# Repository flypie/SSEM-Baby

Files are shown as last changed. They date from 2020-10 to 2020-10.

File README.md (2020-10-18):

# SSEM-Baby

This is a work in progress.

All of the IP belongs to the Computer Conservation Society this project is purely to convert the diagrams to KiCAD as a format with greater utility. https://computerconservationsociety.org/ssemvolunteers/volunteers/index.html

I do not claim any rights whatsoever.

If anyone want to do help out with checks or corrections let me know and I'll try and work out how Merge works.

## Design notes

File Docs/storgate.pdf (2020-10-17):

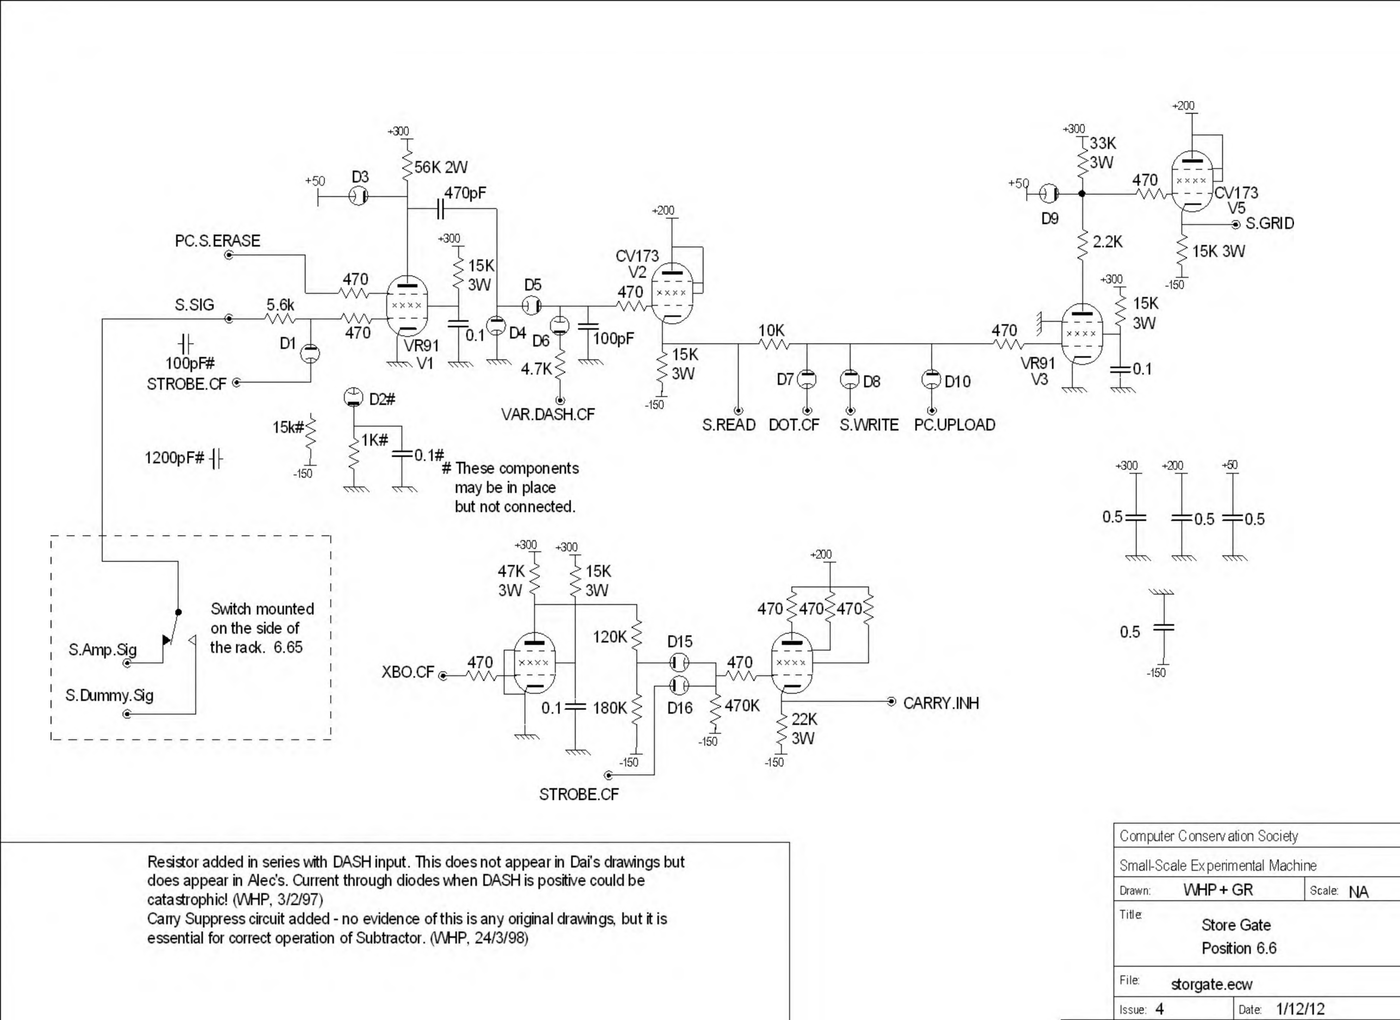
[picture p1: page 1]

Resistor added in series with DASH input. This does not appear in Dai's drawings but does appear in Alec's. Current through diodes when DASH is positive could be catastrophic! {]NHP, 3/2/97)
Carry Suppress circuit added - no evidence of this is any original drawings, but it is essential for correct operation of Subtractor. (WHP, 24/3/98)

C o m p u te r C o n s e rv a tio n S o cie ty

S m a ll-S c a le E x p e rim e n ta l M a ch in e

Drawn: | VMHP+GR | Scale: |\|/\
| Store Gate Position 6.6
Flle | storgate.ecw

Issue:

4 | Date: | 1/12/12

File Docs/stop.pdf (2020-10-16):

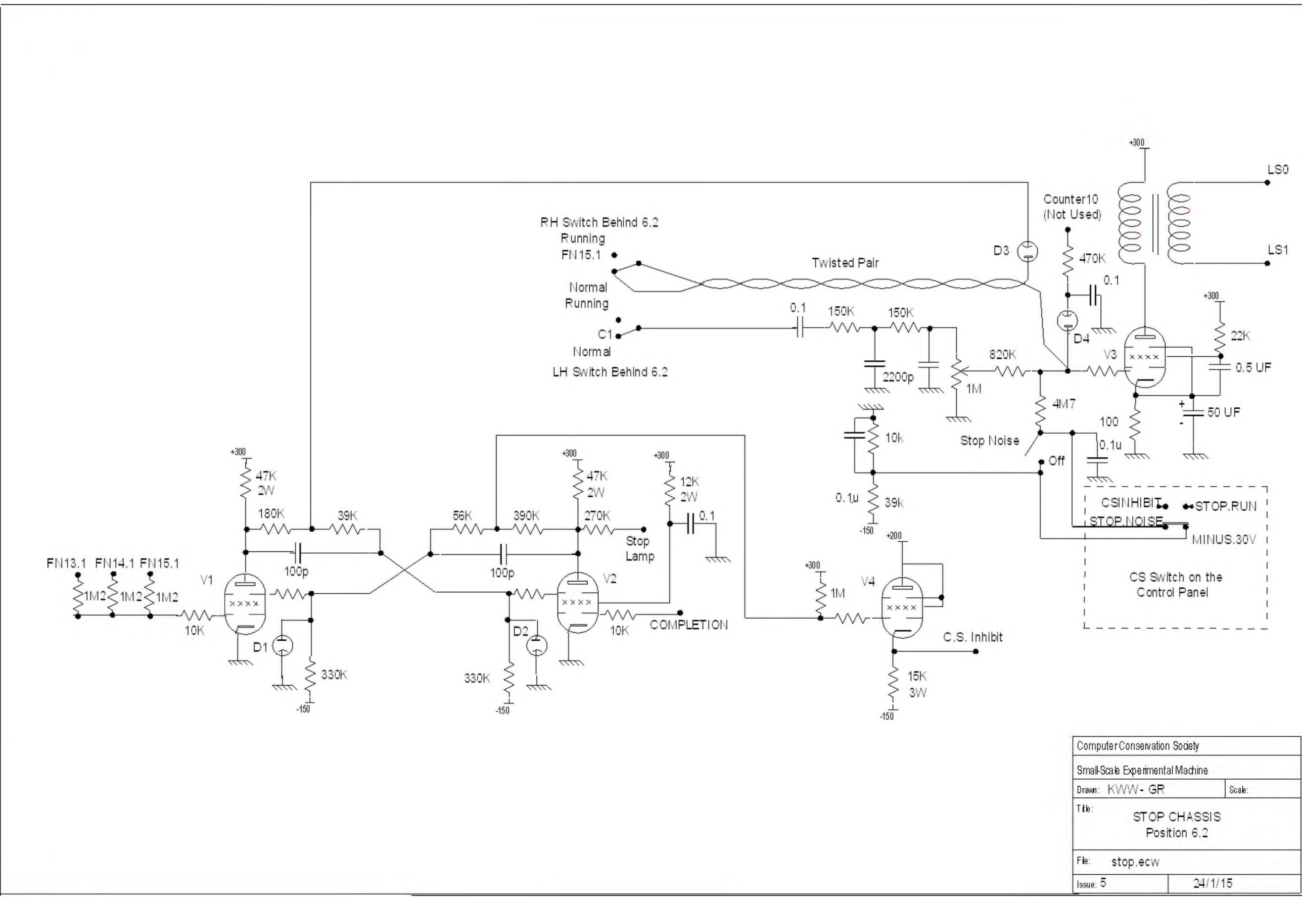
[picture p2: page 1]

+300

FI 113.1 FN 14.1 FI 115.1

>im 2 < im : < im :

V1

'A / W ^ r - — j
10K

LSO

ComputerConseivation Soaety Small-Scale B<perimentalMachine

Draw: KWW- GR | Scale:
Tile: | STOP CHASSIS

Position 6.2

Fie: | stop.ecw
Issue: 0 | 24/1/15

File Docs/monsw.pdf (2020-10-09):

a

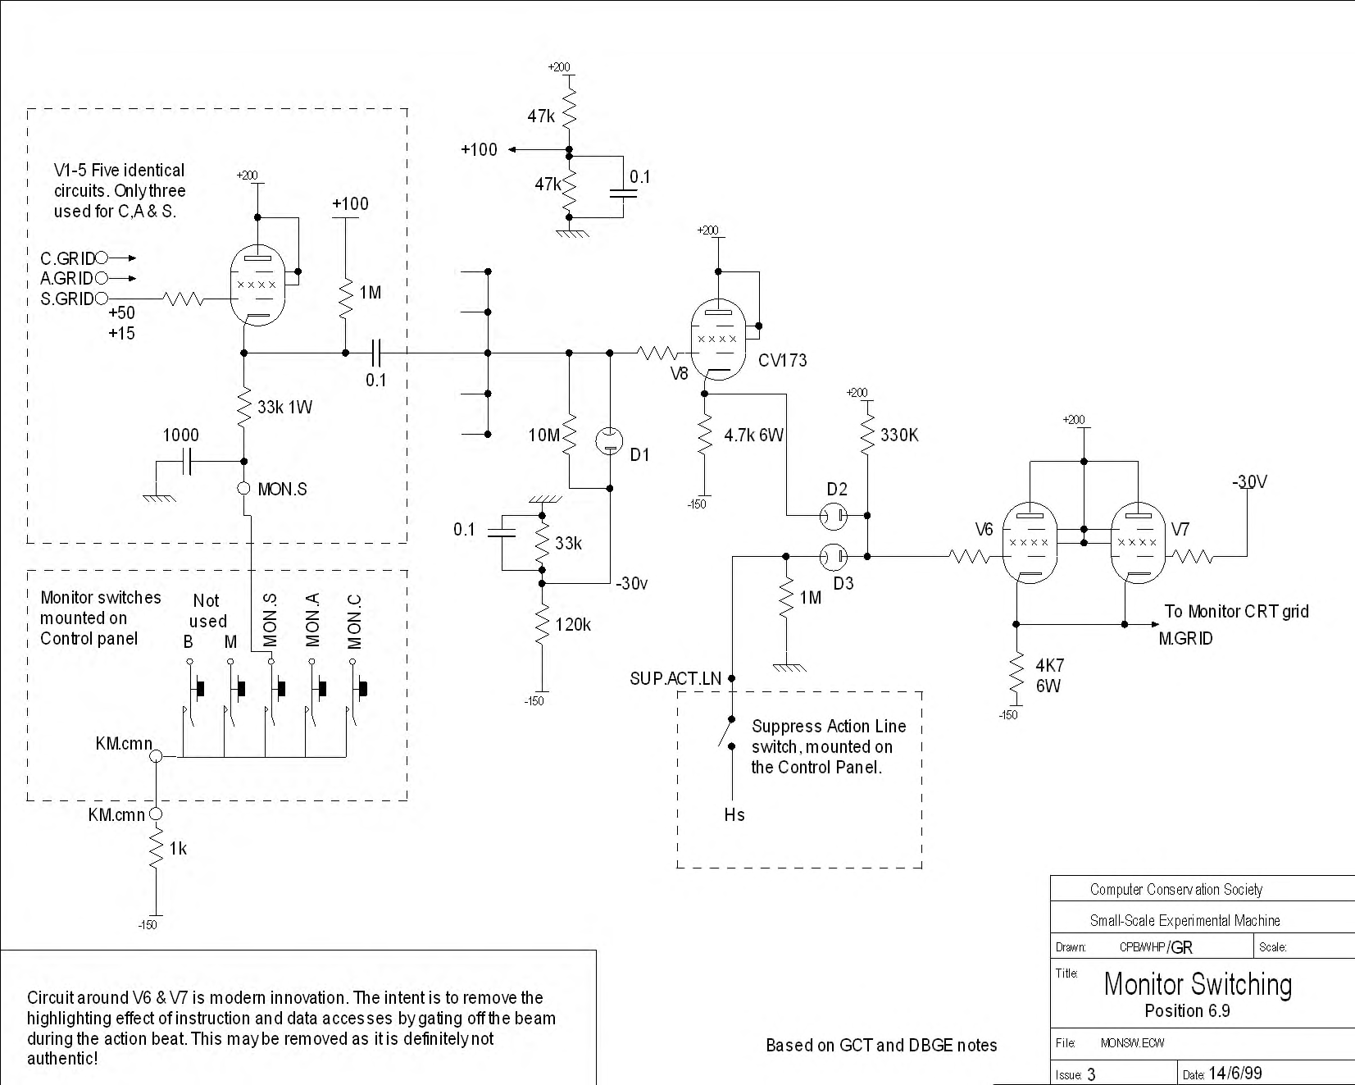
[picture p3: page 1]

+200

V1-5 Five identical | + 2 C 0
circuits. Onlythree
used for C.A& S. | t----
C.GRIDO— ► | / 1___ ___1 \
A.GRIDO—*■ | X X X X
S.GRIDO--------- W V —

+100

+50
+15

0.1
33k 1W

1000

MON.S

Monitor switches
mounted on
Control panel

Not
used
B

KM.cmn.
O-

co

o

<

o

q

o

+ | + | + | +

^

> | > | > | >1 | >

KM.cmn O

1k

-150

Circuit around V6 &V7 is modern innovation. The intent is to remove the highlighting effect of instruction and data accesses by gating off the beam during the action beat. This maybe removed as it is definitely not authentic!

0.1

+200

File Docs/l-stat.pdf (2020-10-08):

# Gb____^At)

l | (? | 0

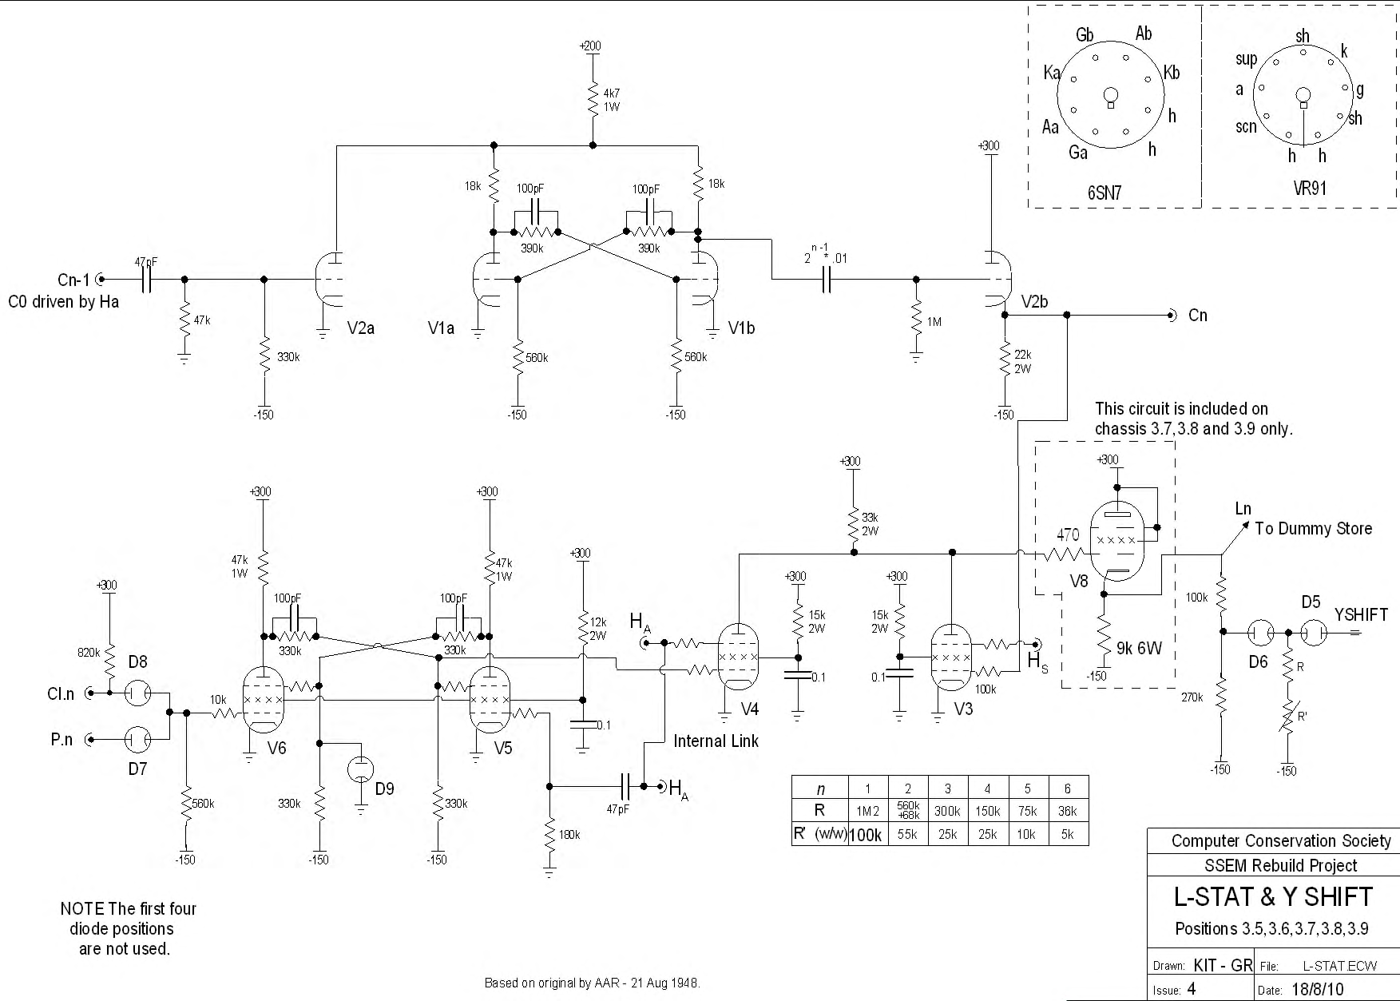
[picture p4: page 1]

+200

Cn-1 (?

# CO driven by Ha

4- V1b

+300 | +300

# NOTE The first four diode positions

are not used.

B a s e d o n o r ig in a l b y A A R - 21 A u g 1 9 4 8.

+300

n -1
2 | *.01
/ | 0 | o
■ '* 7 | O | o vKb

' h

# AaV o o

I,
Ga | h

6SN7

V2b

22k
2 W

-150

+330

33k
2 W
+300 | +300
15k | 15k
2 W | 2 W
-0.1 | 0 .1 -

1

*> Cn

# This circuit is included on

chassis 37,3.8 and 3.9 only.

+300

470
Y W -

V8

t?

i

--- - - i / V W
X X X X | Y 1 S 9k 6W

■ \A A /—

Hs ,

-150 | 1

Ln

# To Dummy Store

100k | D5
D6 | R

# YSHIFT

## -L _L V3

1 COk
270k

R 1

-150

n | 1 | 2 | 3 | 4 | 5 | 6
R | 1 M 2 | o c o | 3 0 0 k | 1 5 0 k | 7 5 k | 3 6 k
R (w/w)100k 5 5 k | 2 5 k | 2 5 k | 1 0 k | 5 k

-150

# Computer Conservation Society SSEM Rebuild Project

# L-STAT& YSHIFT

# Positions 3.5,3.6,37,3.8,3.9

D raw n: KIT - GR

### issue:: 4

### File: L-S T A T .E C W

### Dale: 1 8 / 8 / 1 0

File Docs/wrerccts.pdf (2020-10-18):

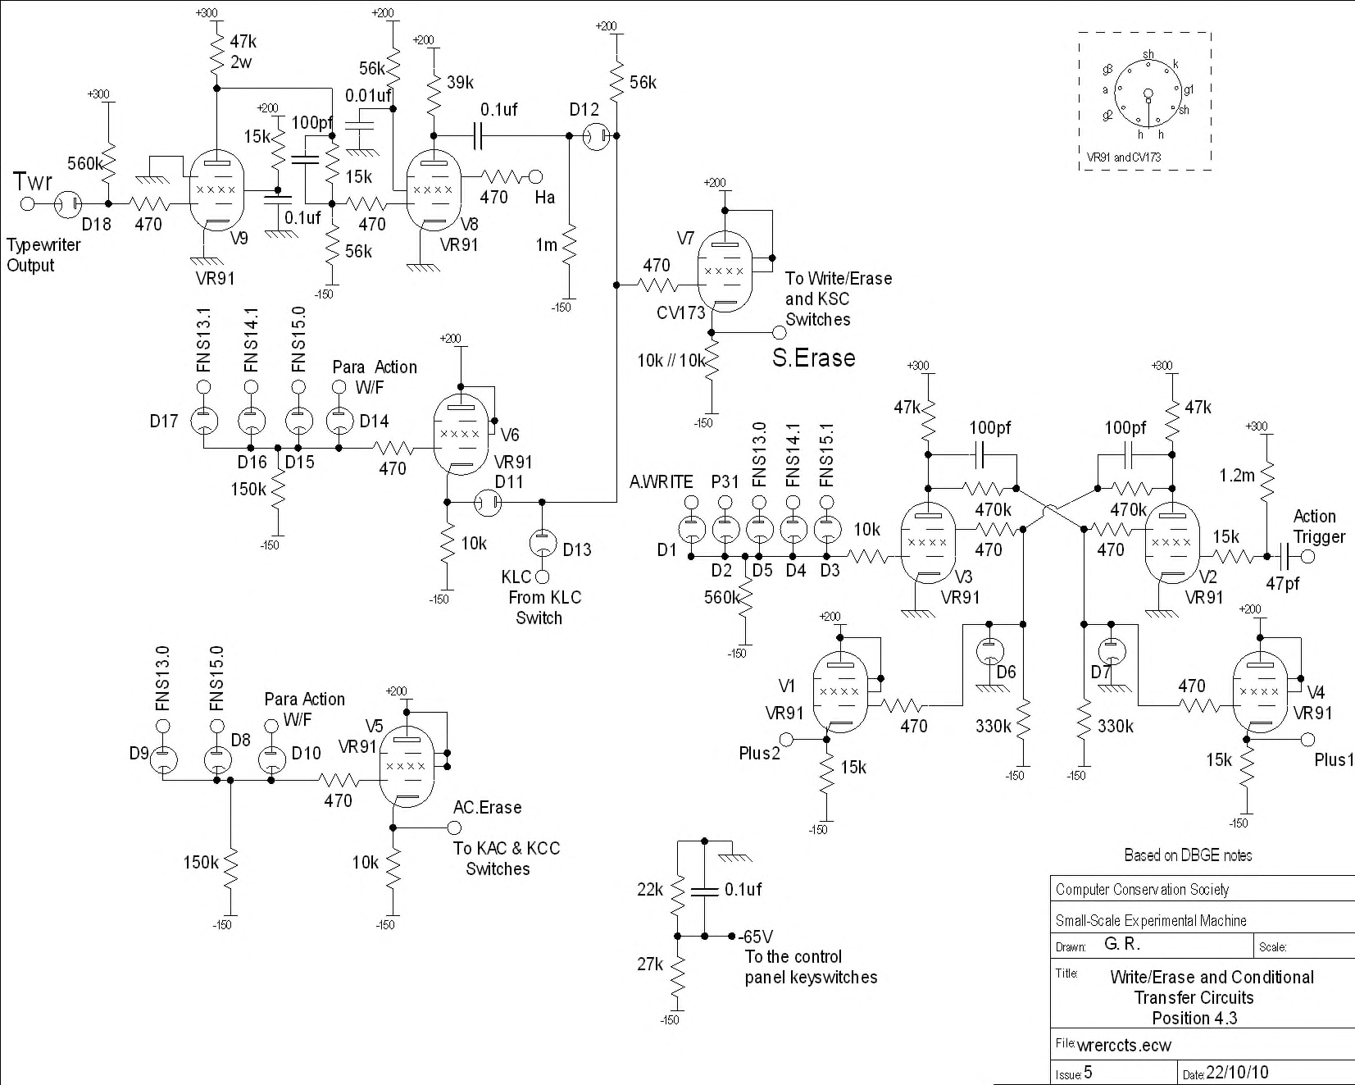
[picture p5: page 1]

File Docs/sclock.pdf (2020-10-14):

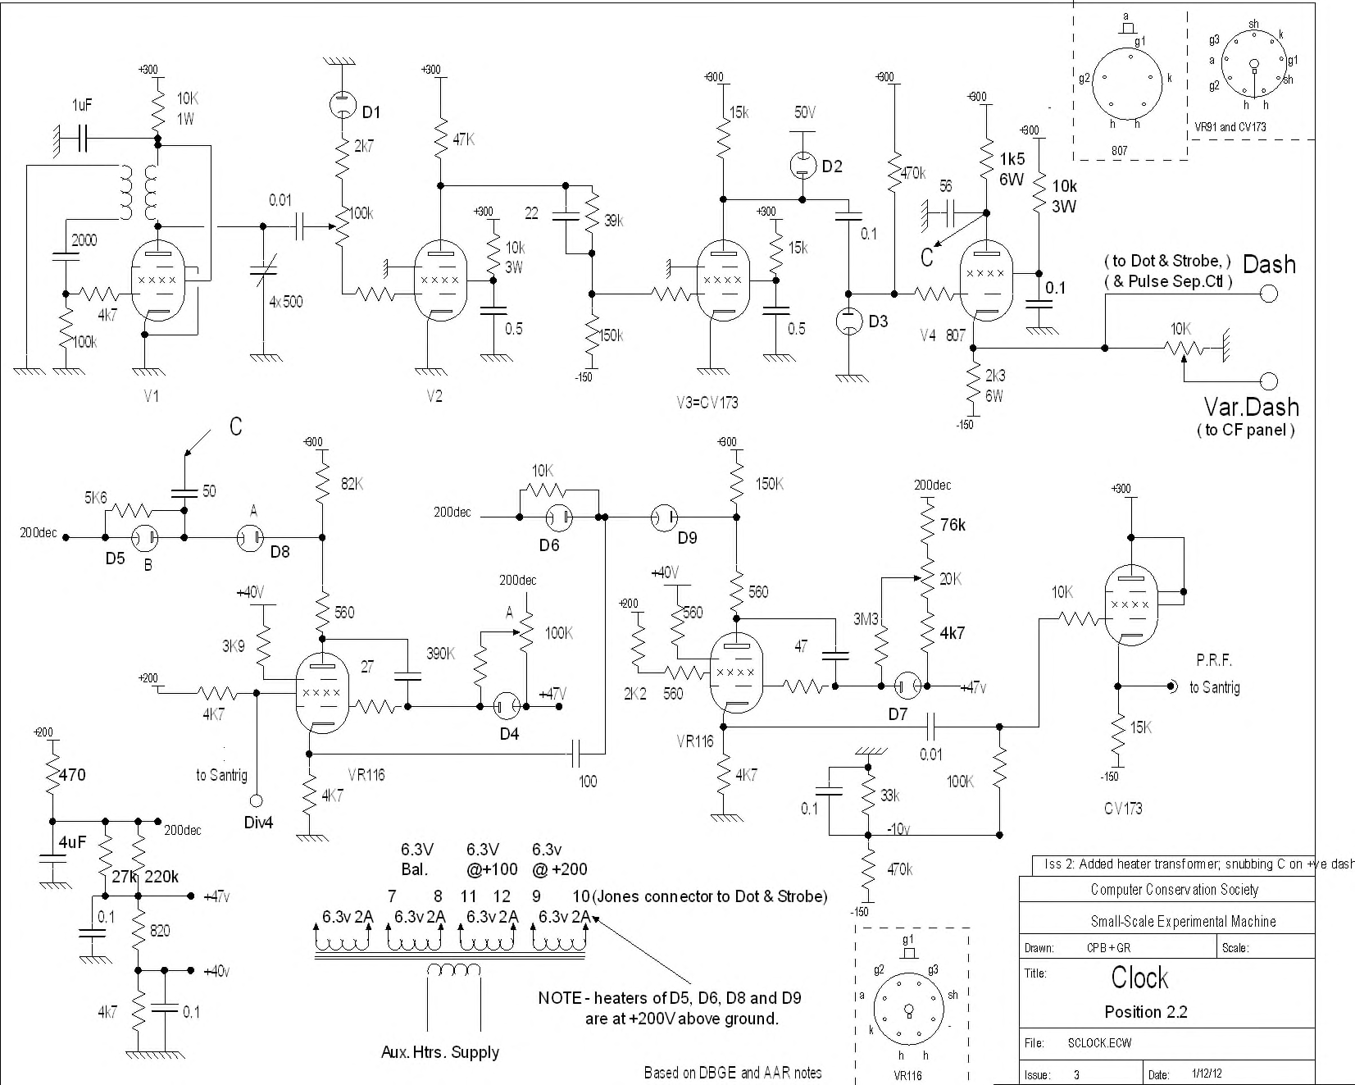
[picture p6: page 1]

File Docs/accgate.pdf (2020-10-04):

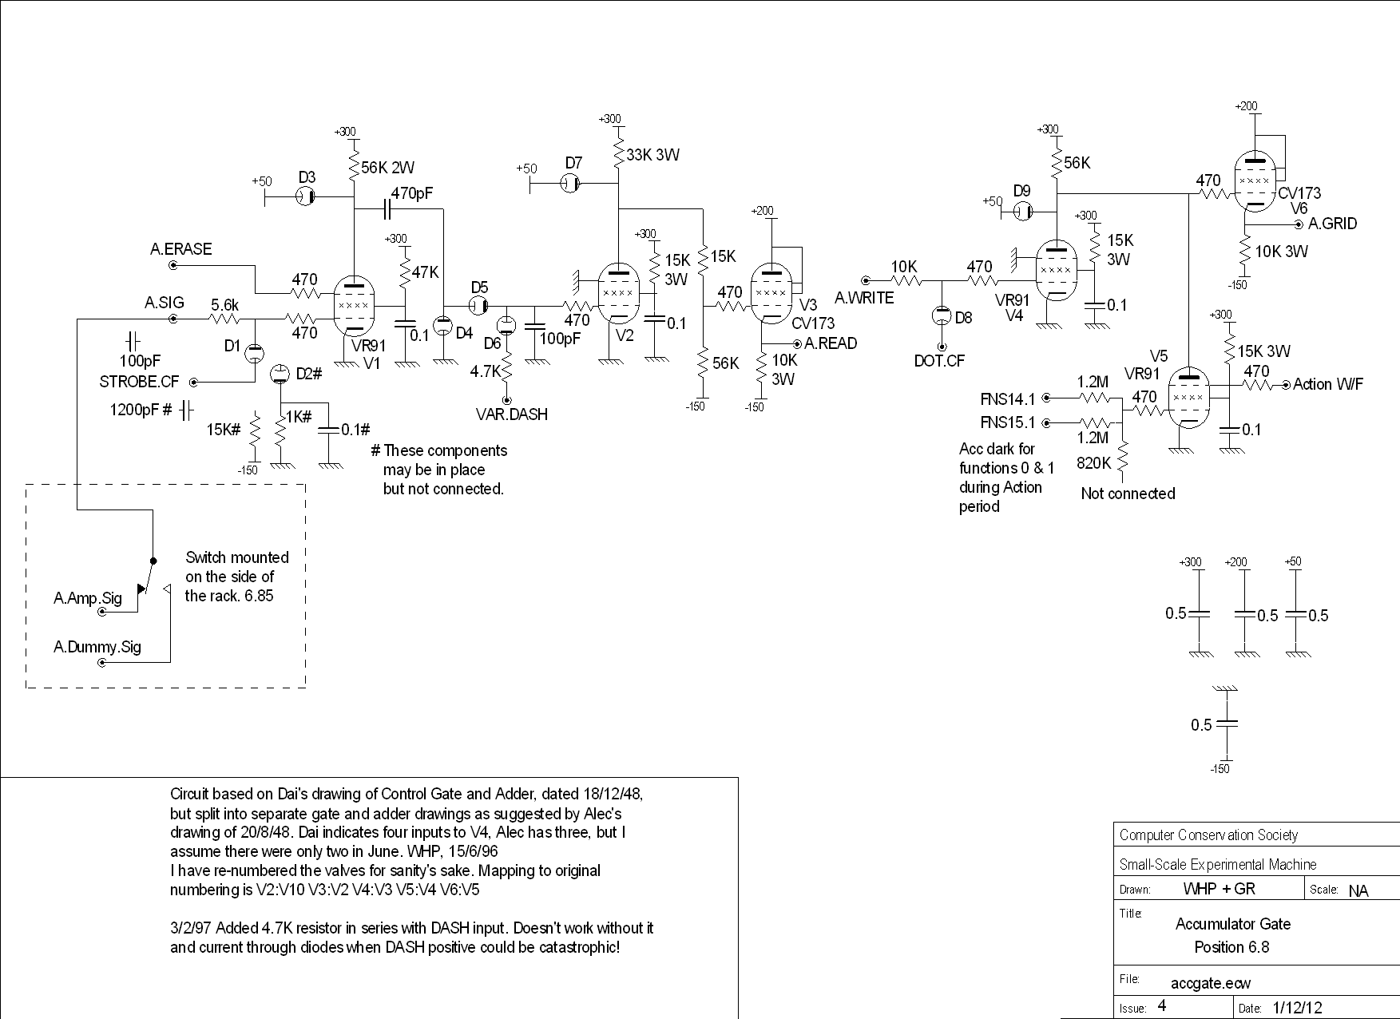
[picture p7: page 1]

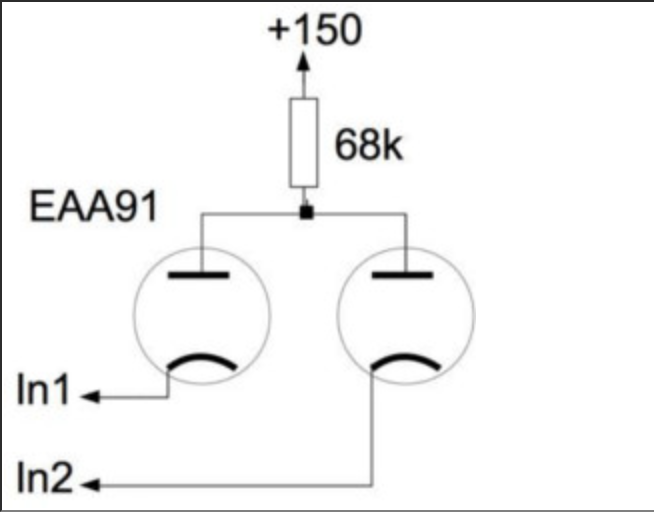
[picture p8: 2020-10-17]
Gates/and.png

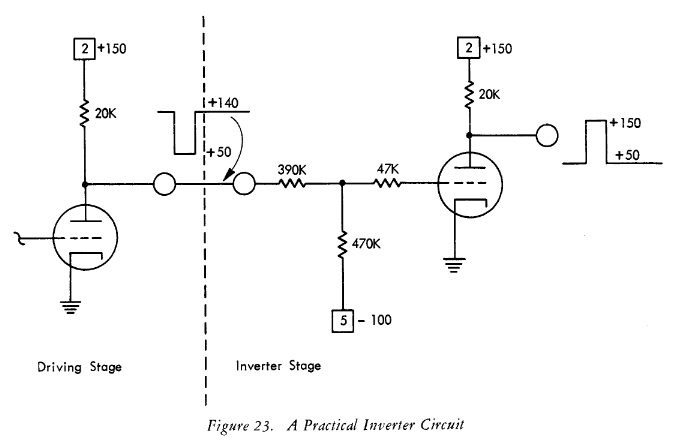
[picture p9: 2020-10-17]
Gates/ibm not.png

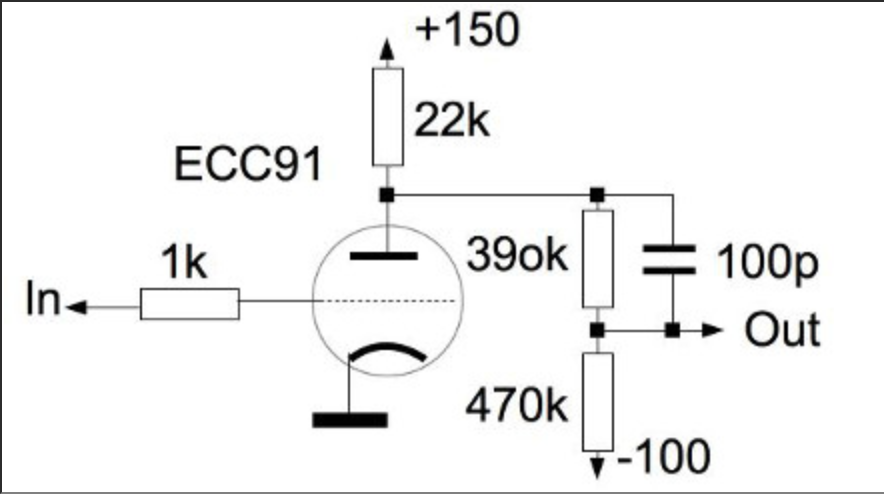
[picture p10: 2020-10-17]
Gates/NOT.png

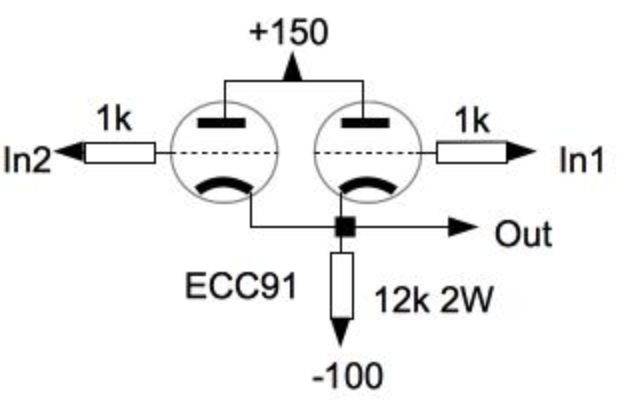
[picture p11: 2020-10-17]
Gates/or.png

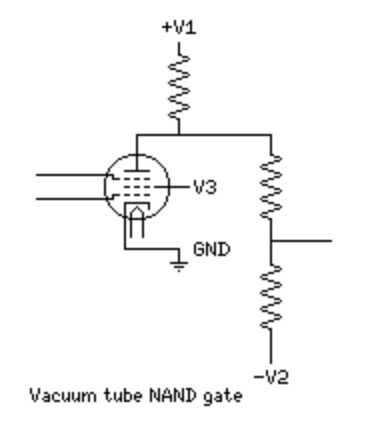
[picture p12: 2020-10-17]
Gates/NAND.png

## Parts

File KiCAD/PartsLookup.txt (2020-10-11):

CR1 DILA22 
CR2 DILA40 + DILA-XHI10 
CR3 DILA40 + DILA-XHI01
CR4 DILA22

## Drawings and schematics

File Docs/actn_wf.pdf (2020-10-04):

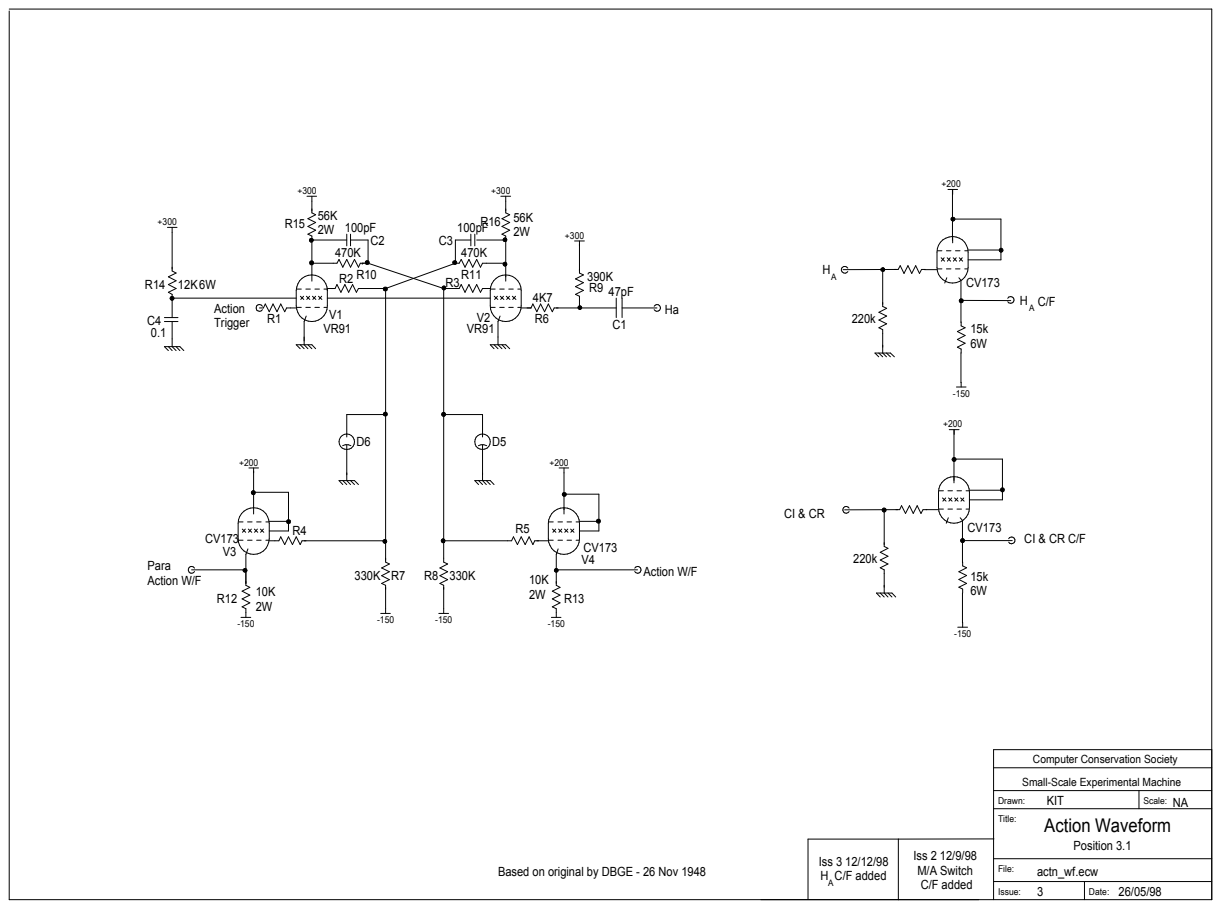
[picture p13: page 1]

Small-Scale Experimental Machine
KIT
Action Waveform

Iss 3 12/12/98 H C/F added A | Iss 2 12/9/98 M/A Switch C/F added

Based on original by DBGE - 26 Nov 1948

Issue: 3 | Date: 26/05/98

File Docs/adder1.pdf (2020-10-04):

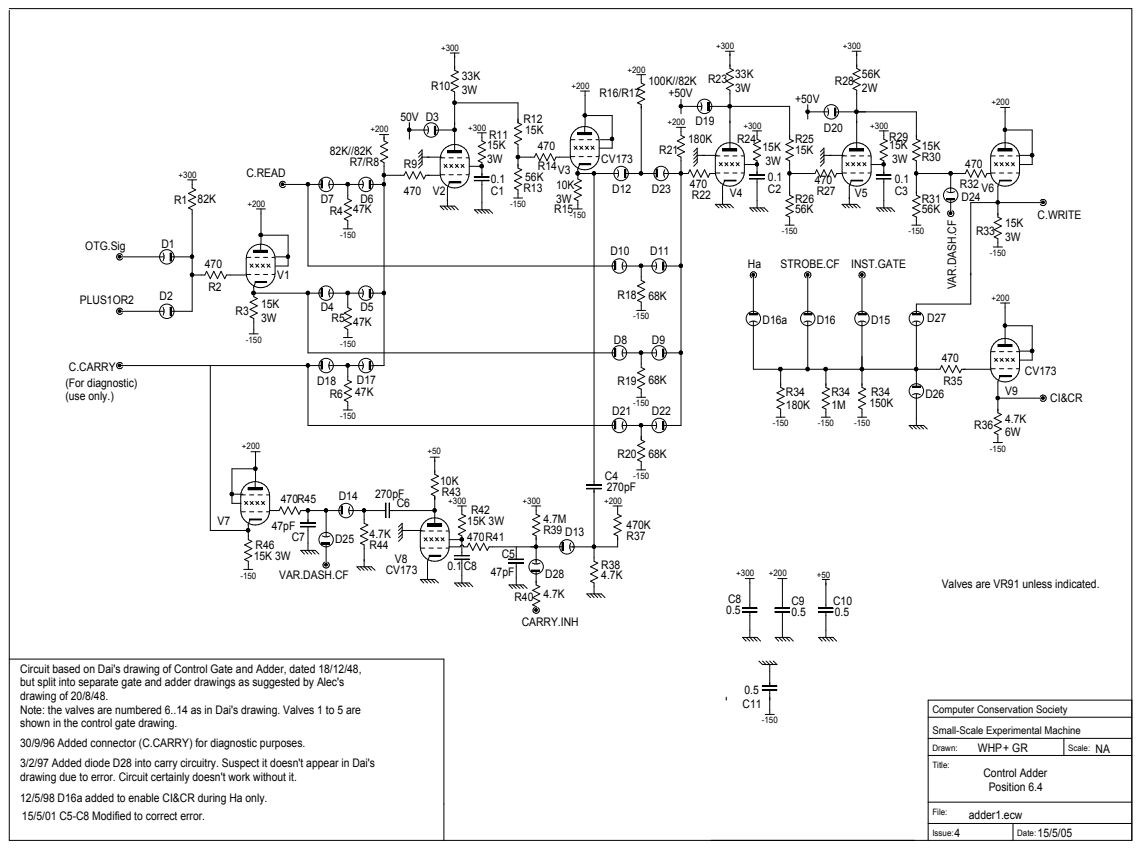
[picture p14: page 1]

Valves are VR91 unless indicated.

Circuit based on Dai's drawing of Control Gate and Adder, dated 18/12/48,
but split into separate gate and adder drawings as suggested by Alec's
drawing of 20/8/48.
Note: the valves are numbered 6..14 as in Dai's drawing. Valves 1 to 5 are
shown in the control gate drawing.
30/9/96 Added connector (C.CARRY) for diagnostic purposes.
3/2/97 Added diode D28 into carry circuitry. Suspect it doesn't appear in Dai's
drawing due to error. Circuit certainly doesn't work without it.

Small-Scale Experimental Machine

12/5/98 D16a added to enable CI&CR during Ha only.
15/5/01 C5-C8 Modified to correct error.

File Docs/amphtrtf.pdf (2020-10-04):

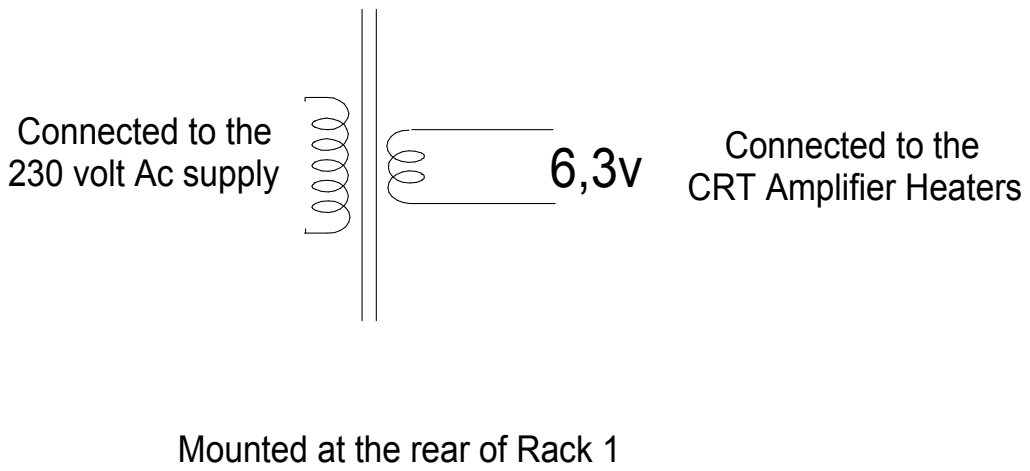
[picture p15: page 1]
Drawn:; Scale:; Title:; File:; Issue:; Date:; Position 1.5; AMPHTRTF.ECW

Connected to the
230 volt Ac supply

CRT Amplifier Heaters

Mounted at the rear of Rack 1

Computer Conservation Society

Small-Scale Experimental Machine

Amp Heater Transformer

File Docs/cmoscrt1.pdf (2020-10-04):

C0

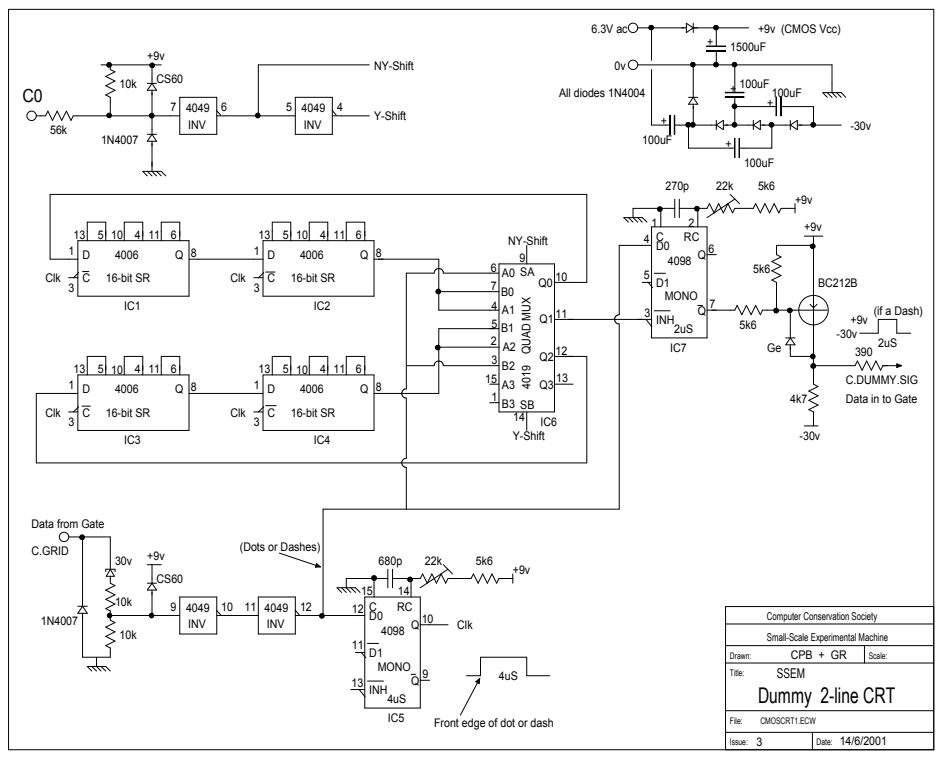
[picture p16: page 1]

C.DUMMY.SIG
Data in to Gate

Small-Scale Experimental Machine
CPB + GR
SSEM
Dummy 2-line CRT

Front edge of dot or dash

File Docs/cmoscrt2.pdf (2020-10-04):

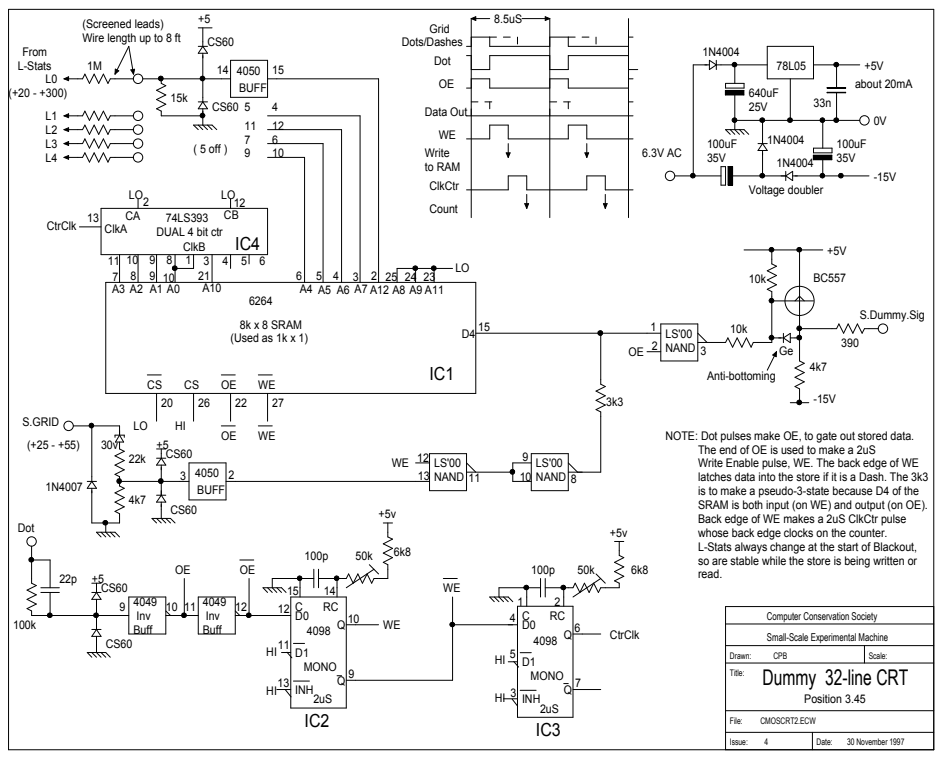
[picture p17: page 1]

(Screened leads)
Wire length up to 8 ft

NOTE: Dot pulses make OE, to gate out stored data.
The end of OE is used to make a 2uS
Write Enable pulse, WE. The back edge of WE
latches data into the store if it is a Dash. The 3k3
is to make a pseudo-3-state because D4 of the
SRAM is both input (on WE) and output (on OE).
Back edge of WE makes a 2uS ClkCtr pulse
whose back edge clocks on the counter.
L-Stats always change at the start of Blackout,
so are stable while the store is being written or
read.

Small-Scale Experimental Machine
Dummy 32-line CRT

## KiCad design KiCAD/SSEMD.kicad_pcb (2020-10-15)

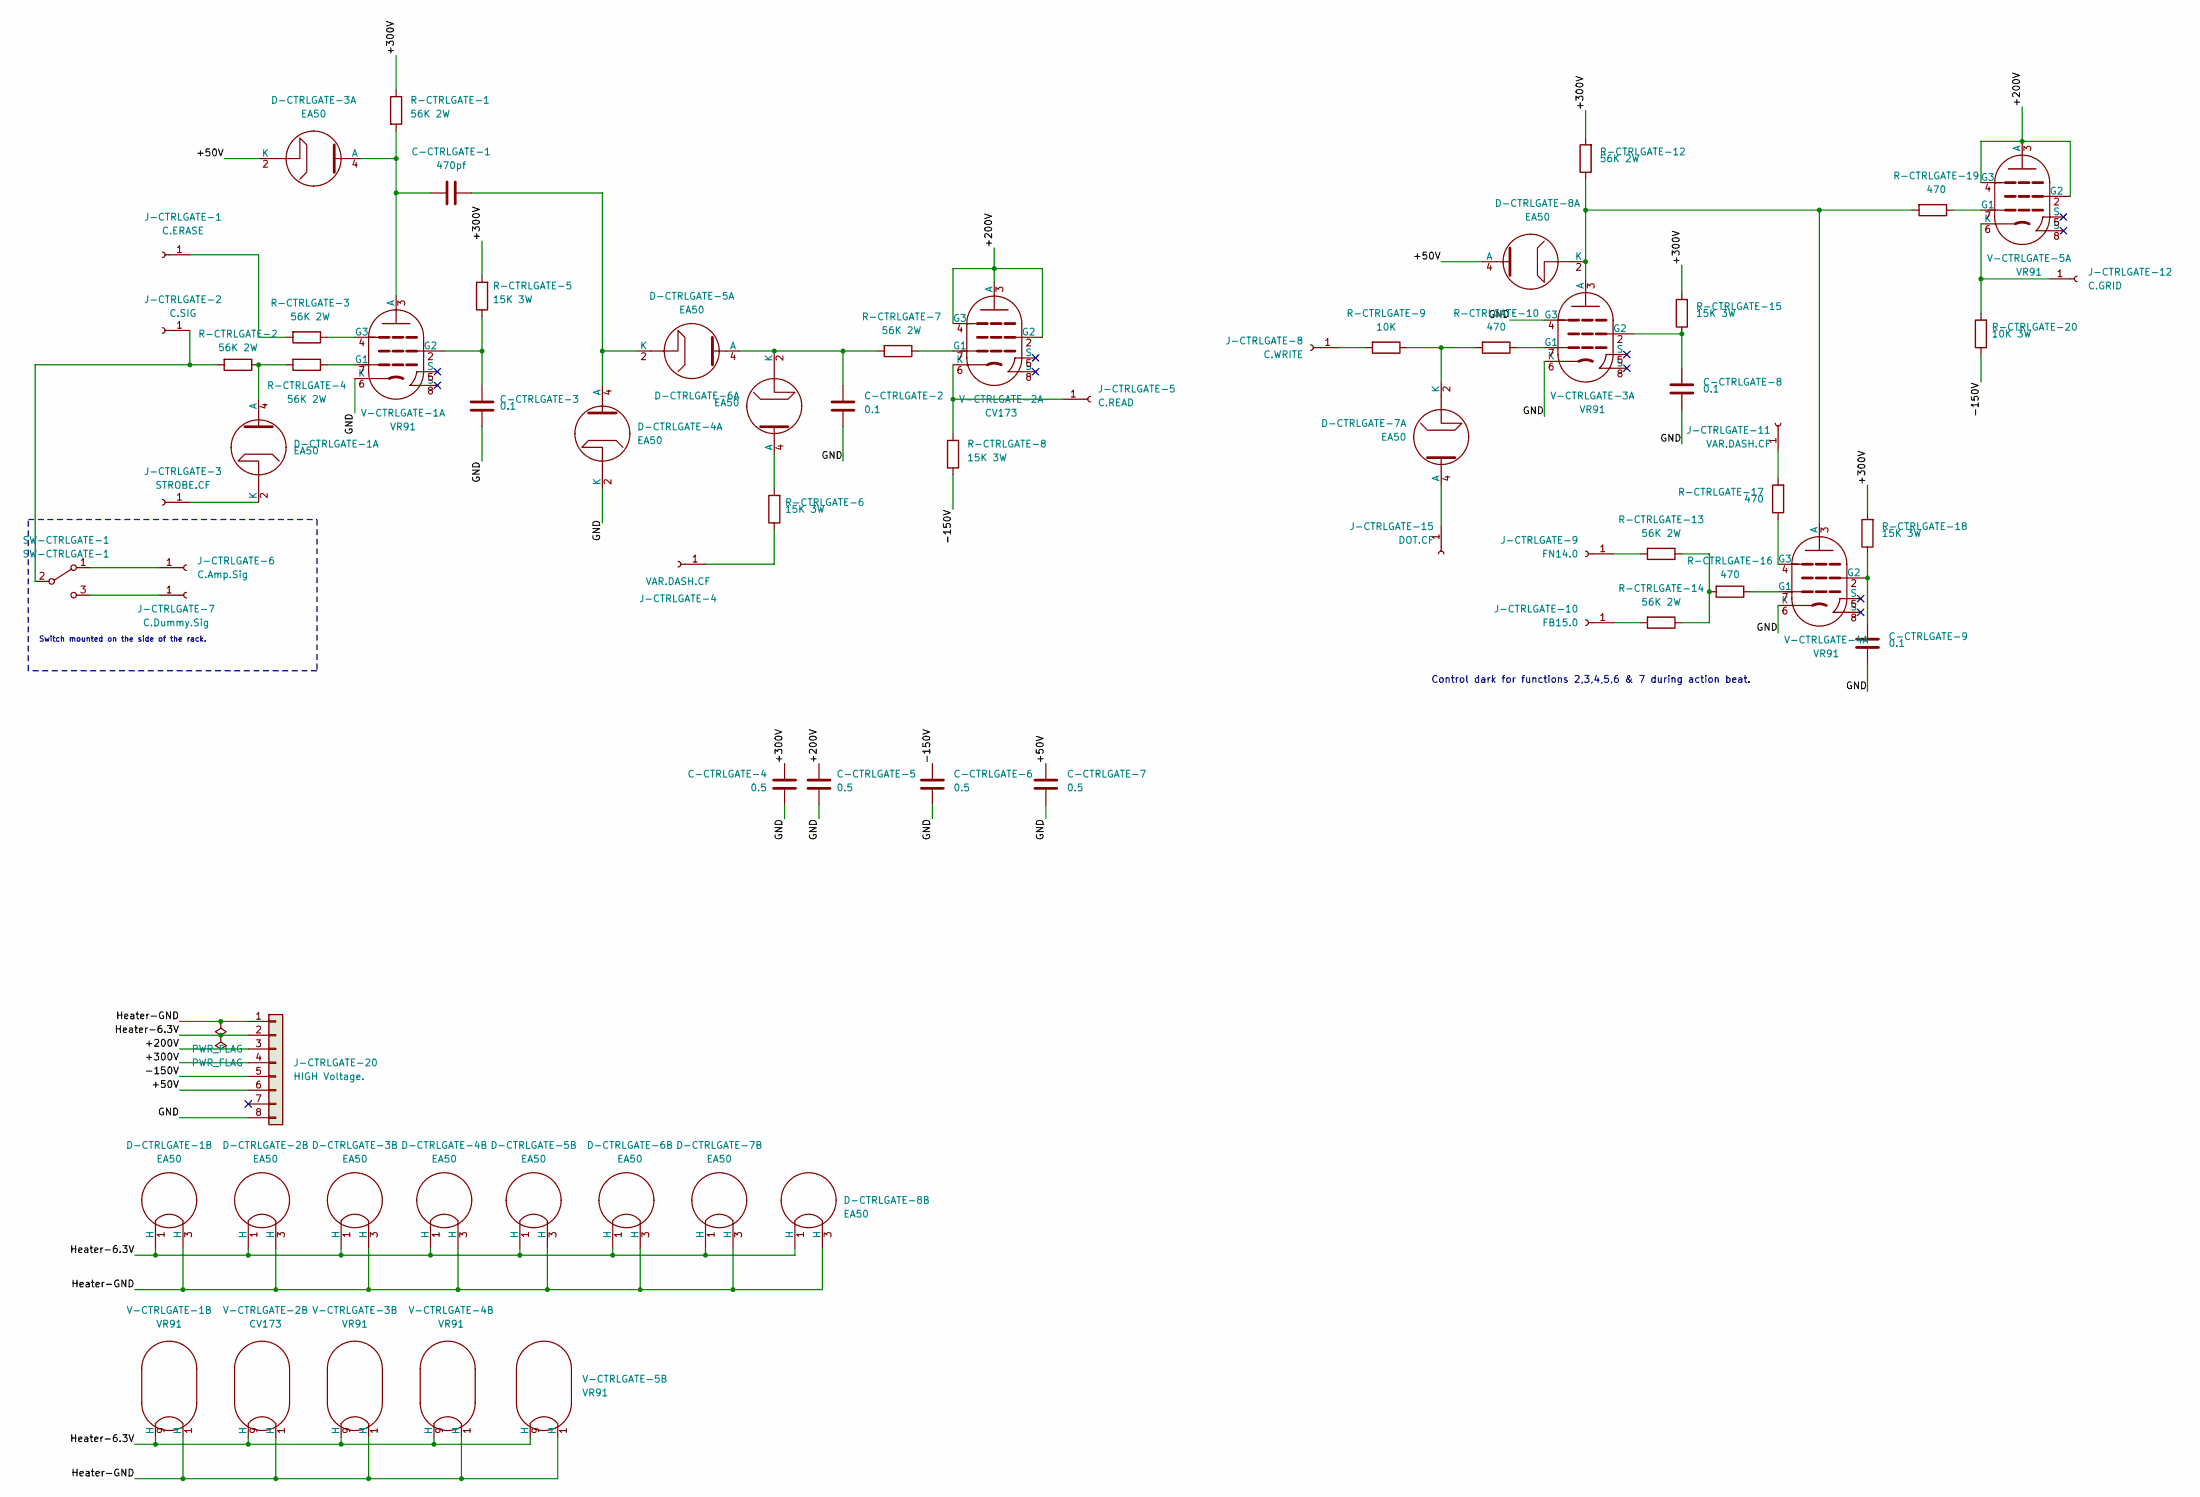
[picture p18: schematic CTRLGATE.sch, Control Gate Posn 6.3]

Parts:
C-CTRLGATE-1: 470pf; C_Disc_D7.5mm_W5.0mm_P5.00mm
C-CTRLGATE-2, C-CTRLGATE-3, C-CTRLGATE-8, C-CTRLGATE-9: 0.1; C_Disc_D7.5mm_W5.0mm_P5.00mm
C-CTRLGATE-4, C-CTRLGATE-5, C-CTRLGATE-6, C-CTRLGATE-7: 0.5; C_Disc_D7.5mm_W5.0mm_P5.00mm
D-CTRLGATE-1, D-CTRLGATE-2, D-CTRLGATE-3, D-CTRLGATE-4, D-CTRLGATE-5, D-CTRLGATE-6, D-CTRLGATE-7, D-CTRLGATE-8: EA50; Valve_B3G
J-CTRLGATE-1: C.ERASE; 242431
J-CTRLGATE-2: C.SIG; 242431
J-CTRLGATE-3: STROBE.CF; 242431
J-CTRLGATE-4, J-CTRLGATE-11: VAR.DASH.CF; 242431
J-CTRLGATE-5: C.READ; 242431
J-CTRLGATE-6: C.Amp.Sig; 242431
J-CTRLGATE-7: C.Dummy.Sig; 242431
J-CTRLGATE-8: C.WRITE; 242431
J-CTRLGATE-9: FN14.0; 242431
J-CTRLGATE-10: FB15.0; 242431
J-CTRLGATE-12: C.GRID; 242431
J-CTRLGATE-15: DOT.CF; 242431
J-CTRLGATE-20: HIGH Voltage.; TE_MATE-N-LOK_1-770970-x_2x04_P4.14mm_Horizontal
R-CTRLGATE-1, R-CTRLGATE-2, R-CTRLGATE-3, R-CTRLGATE-4, R-CTRLGATE-7, R-CTRLGATE-12, R-CTRLGATE-13, R-CTRLGATE-14: 56K 2W; R_Axial_DIN0516_L15.5mm_D5.0mm_P5.08mm_Vertical
R-CTRLGATE-5, R-CTRLGATE-6, R-CTRLGATE-8, R-CTRLGATE-15, R-CTRLGATE-18: 15K 3W; R_Axial_DIN0516_L15.5mm_D5.0mm_P5.08mm_Vertical
R-CTRLGATE-9: 10K; R_Axial_DIN0516_L15.5mm_D5.0mm_P5.08mm_Vertical
R-CTRLGATE-10, R-CTRLGATE-16, R-CTRLGATE-17, R-CTRLGATE-19: 470; R_Axial_DIN0516_L15.5mm_D5.0mm_P5.08mm_Vertical
R-CTRLGATE-20: 10K 3W; R_Axial_DIN0516_L15.5mm_D5.0mm_P5.08mm_Vertical
SW-CTRLGATE-1: SW-CTRLGATE-1; M2011SS1W03
V-CTRLGATE-1, V-CTRLGATE-3, V-CTRLGATE-4, V-CTRLGATE-5: VR91; Valve_9Loctal
V-CTRLGATE-2: CV173; Valve_9Loctal

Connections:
/CTRLGATE/+50V: C-CTRLGATE-7.1, D-CTRLGATE-3.2 (K), D-CTRLGATE-8.4 (A), J-CTRLGATE-20.6
/CTRLGATE/+200V: C-CTRLGATE-5.1, J-CTRLGATE-20.3, V-CTRLGATE-2.2 (G2), V-CTRLGATE-2.3 (A), V-CTRLGATE-2.4 (G3), V-CTRLGATE-5.2 (G2), V-CTRLGATE-5.3 (A), V-CTRLGATE-5.4 (G3)
/CTRLGATE/+300V: C-CTRLGATE-4.1, J-CTRLGATE-20.4, R-CTRLGATE-1.1, R-CTRLGATE-5.2, R-CTRLGATE-12.2, R-CTRLGATE-15.2, R-CTRLGATE-18.2
/CTRLGATE/-150V: C-CTRLGATE-6.2, J-CTRLGATE-20.5, R-CTRLGATE-8.1, R-CTRLGATE-20.1
/CTRLGATE/GND: C-CTRLGATE-2.2, C-CTRLGATE-3.2, C-CTRLGATE-4.2, C-CTRLGATE-5.2, C-CTRLGATE-6.1, C-CTRLGATE-7.2, C-CTRLGATE-8.2, C-CTRLGATE-9.2, D-CTRLGATE-4.2 (K), J-CTRLGATE-20.8, V-CTRLGATE-1.6 (K), V-CTRLGATE-3.4 (G3), V-CTRLGATE-3.6 (K), V-CTRLGATE-4.6 (K)
/CTRLGATE/Heater-6.3V: D-CTRLGATE-1.1 (H), D-CTRLGATE-2.1 (H), D-CTRLGATE-3.1 (H), D-CTRLGATE-4.1 (H), D-CTRLGATE-5.1 (H), D-CTRLGATE-6.1 (H), D-CTRLGATE-7.1 (H), D-CTRLGATE-8.1 (H), J-CTRLGATE-20.2, V-CTRLGATE-1.9 (H), V-CTRLGATE-2.9 (H), V-CTRLGATE-3.9 (H), V-CTRLGATE-4.9 (H), V-CTRLGATE-5.9 (H)
/CTRLGATE/Heater-GND: D-CTRLGATE-1.3 (H), D-CTRLGATE-2.3 (H), D-CTRLGATE-3.3 (H), D-CTRLGATE-4.3 (H), D-CTRLGATE-5.3 (H), D-CTRLGATE-6.3 (H), D-CTRLGATE-7.3 (H), D-CTRLGATE-8.3 (H), J-CTRLGATE-20.1, V-CTRLGATE-1.1 (H), V-CTRLGATE-2.1 (H), V-CTRLGATE-3.1 (H), V-CTRLGATE-4.1 (H), V-CTRLGATE-5.1 (H)
unnamed: C-CTRLGATE-1.1, D-CTRLGATE-3.4 (A), R-CTRLGATE-1.2, V-CTRLGATE-1.3 (A)
unnamed: C-CTRLGATE-1.2, D-CTRLGATE-4.4 (A), D-CTRLGATE-5.2 (K)
unnamed: C-CTRLGATE-2.1, D-CTRLGATE-5.4 (A), D-CTRLGATE-6.2 (K), R-CTRLGATE-7.2
unnamed: C-CTRLGATE-3.1, R-CTRLGATE-5.1, V-CTRLGATE-1.2 (G2)
unnamed: C-CTRLGATE-8.1, R-CTRLGATE-15.1, V-CTRLGATE-3.2 (G2)
unnamed: C-CTRLGATE-9.1, R-CTRLGATE-18.1, V-CTRLGATE-4.2 (G2)
unnamed: D-CTRLGATE-1.2 (K), J-CTRLGATE-3.1
unnamed: D-CTRLGATE-1.4 (A), R-CTRLGATE-2.1, R-CTRLGATE-4.2
unnamed: D-CTRLGATE-6.4 (A), R-CTRLGATE-6.2
unnamed: D-CTRLGATE-7.2 (K), R-CTRLGATE-9.1, R-CTRLGATE-10.2
unnamed: D-CTRLGATE-7.4 (A), J-CTRLGATE-15.1
unnamed: D-CTRLGATE-8.2 (K), R-CTRLGATE-12.1, R-CTRLGATE-19.2, V-CTRLGATE-3.3 (A), V-CTRLGATE-4.3 (A)
unnamed: J-CTRLGATE-1.1, R-CTRLGATE-3.2
unnamed: J-CTRLGATE-2.1, R-CTRLGATE-2.2, SW-CTRLGATE-1.2 (B)
unnamed: J-CTRLGATE-4.1, R-CTRLGATE-6.1
unnamed: J-CTRLGATE-5.1, R-CTRLGATE-8.2, V-CTRLGATE-2.6 (K)
unnamed: J-CTRLGATE-6.1, SW-CTRLGATE-1.1 (A)
unnamed: J-CTRLGATE-7.1, SW-CTRLGATE-1.3 (C)
unnamed: J-CTRLGATE-8.1, R-CTRLGATE-9.2
unnamed: J-CTRLGATE-9.1, R-CTRLGATE-13.2
unnamed: J-CTRLGATE-10.1, R-CTRLGATE-14.2
unnamed: J-CTRLGATE-11.1, R-CTRLGATE-17.2
unnamed: J-CTRLGATE-12.1, R-CTRLGATE-20.2, V-CTRLGATE-5.6 (K)
unnamed: R-CTRLGATE-3.1, V-CTRLGATE-1.4 (G3)
unnamed: R-CTRLGATE-4.1, V-CTRLGATE-1.7 (G1)
unnamed: R-CTRLGATE-7.1, V-CTRLGATE-2.7 (G1)
unnamed: R-CTRLGATE-10.1, V-CTRLGATE-3.7 (G1)
unnamed: R-CTRLGATE-13.1, R-CTRLGATE-14.1, R-CTRLGATE-16.2
unnamed: R-CTRLGATE-16.1, V-CTRLGATE-4.7 (G1)
unnamed: R-CTRLGATE-17.1, V-CTRLGATE-4.4 (G3)
unnamed: R-CTRLGATE-19.1, V-CTRLGATE-5.7 (G1)

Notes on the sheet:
Switch mounted on the side of the rack.
Control dark for functions 2,3,4,5,6 & 7 during action beat.

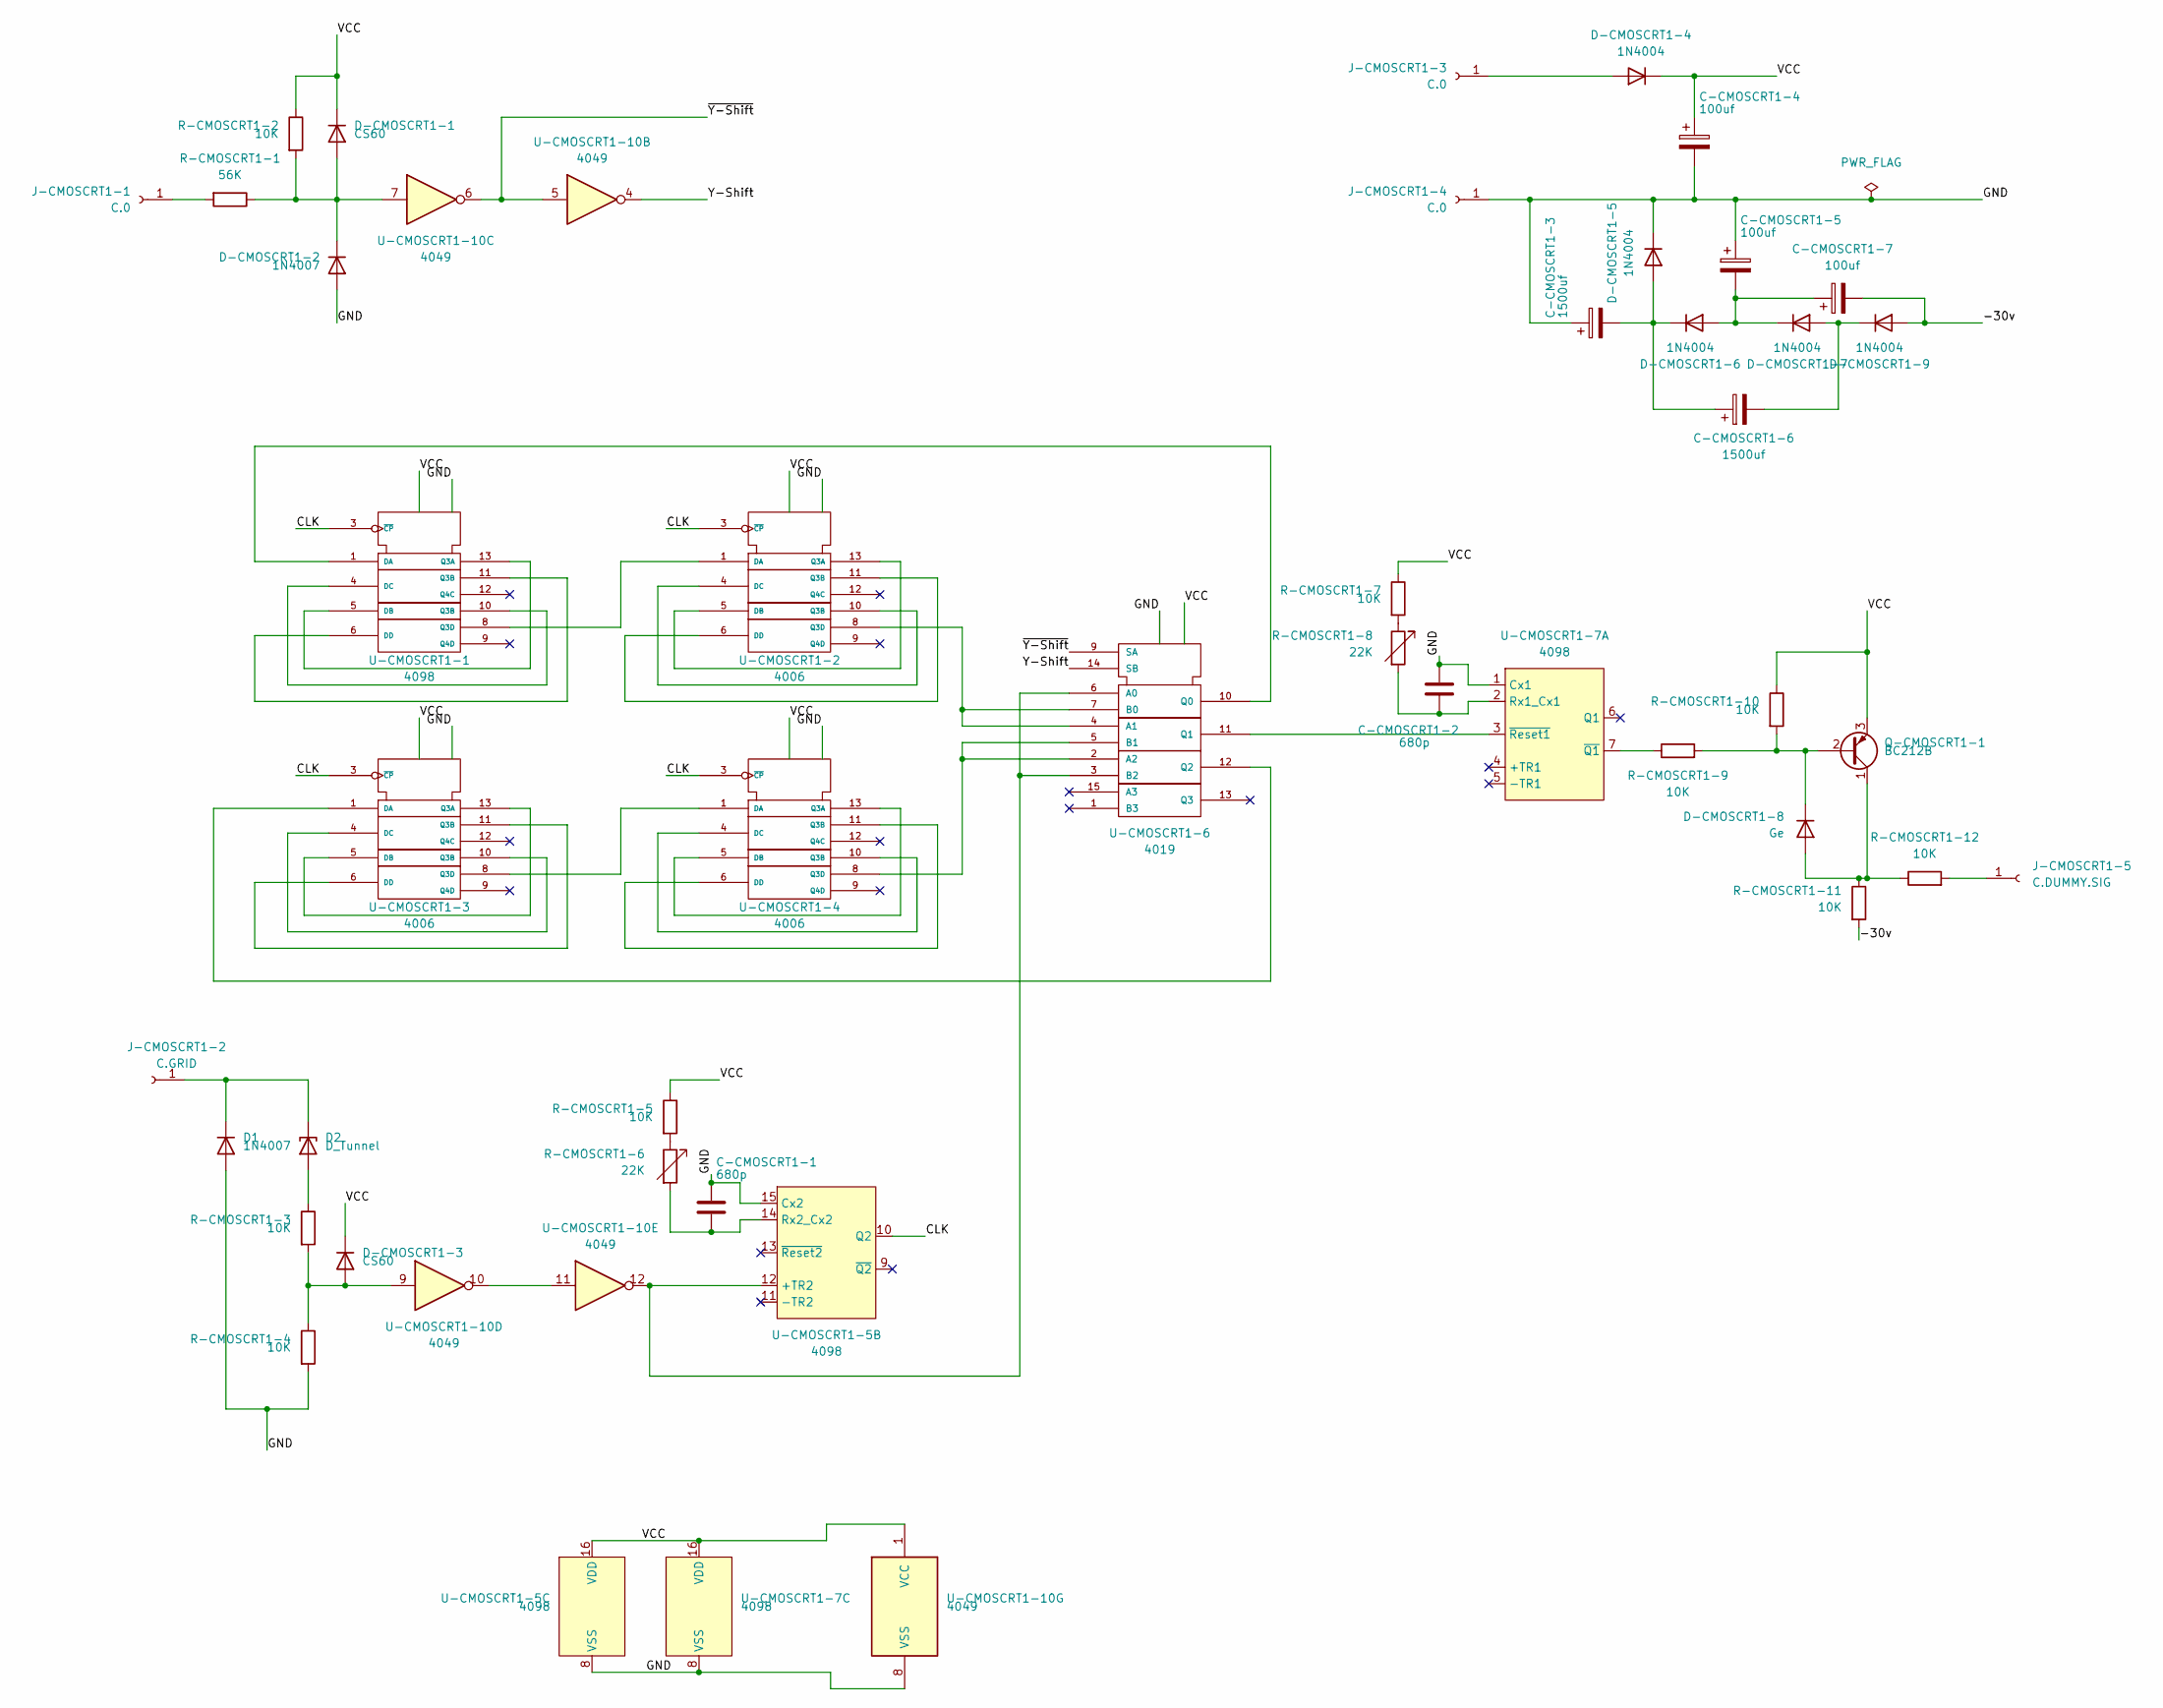
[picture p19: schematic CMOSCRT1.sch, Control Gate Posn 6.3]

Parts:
C-CMOSCRT1-1, C-CMOSCRT1-2: 680p; C_Disc_D7.5mm_W5.0mm_P5.00mm
C-CMOSCRT1-3, C-CMOSCRT1-6: 1500uf; C_Disc_D7.5mm_W5.0mm_P5.00mm
C-CMOSCRT1-4, C-CMOSCRT1-5, C-CMOSCRT1-7: 100uf; C_Disc_D7.5mm_W5.0mm_P5.00mm
D1: 1N4007; D_DO-41_SOD81_P10.16mm_Horizontal
D2: D_Tunnel; D_DO-201_P15.24mm_Horizontal
D-CMOSCRT1-1, D-CMOSCRT1-3: CS60; D_T-1_P5.08mm_Horizontal
D-CMOSCRT1-2: 1N4007; D_DO-41_SOD81_P10.16mm_Horizontal
D-CMOSCRT1-4, D-CMOSCRT1-5, D-CMOSCRT1-6, D-CMOSCRT1-7, D-CMOSCRT1-9: 1N4004; D_DO-41_SOD81_P10.16mm_Horizontal
D-CMOSCRT1-8: Ge; D_DO-41_SOD81_P10.16mm_Horizontal
J-CMOSCRT1-1, J-CMOSCRT1-3, J-CMOSCRT1-4: C.0; 242431
J-CMOSCRT1-2: C.GRID; 242431
J-CMOSCRT1-5: C.DUMMY.SIG; 242431
Q-CMOSCRT1-1: BC212B; TO-92_Inline
R-CMOSCRT1-1: 56K; R_Axial_DIN0516_L15.5mm_D5.0mm_P5.08mm_Vertical
R-CMOSCRT1-2, R-CMOSCRT1-3, R-CMOSCRT1-4, R-CMOSCRT1-5, R-CMOSCRT1-7, R-CMOSCRT1-9, R-CMOSCRT1-10, R-CMOSCRT1-11, R-CMOSCRT1-12: 10K; R_Axial_DIN0516_L15.5mm_D5.0mm_P5.08mm_Vertical
R-CMOSCRT1-6, R-CMOSCRT1-8: 22K; R_Axial_DIN0516_L15.5mm_D5.0mm_P5.08mm_Vertical
U-CMOSCRT1-1: 4098; DIP-14_W7.62mm
U-CMOSCRT1-2, U-CMOSCRT1-3, U-CMOSCRT1-4: 4006; DIP-14_W7.62mm
U-CMOSCRT1-5, U-CMOSCRT1-7: 4098; DIP-16_W7.62mm
U-CMOSCRT1-6: 4019; DIP-16_W7.62mm
U-CMOSCRT1-10: 4049; DIP-14_W7.62mm

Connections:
/CMOSCRT1/-30v: C-CMOSCRT1-7.2, D-CMOSCRT1-9.2 (A), R-CMOSCRT1-11.2
/CMOSCRT1/CLK: U-CMOSCRT1-1.3 (~CP), U-CMOSCRT1-2.3 (~CP), U-CMOSCRT1-3.3 (~CP), U-CMOSCRT1-4.3 (~CP), U-CMOSCRT1-5.10 (Q2)
/CMOSCRT1/Y-Shift: U-CMOSCRT1-6.14 (SB), U-CMOSCRT1-10.4
/CMOSCRT1/~Y-Shift: U-CMOSCRT1-6.9 (SA), U-CMOSCRT1-10.5, U-CMOSCRT1-10.6
unnamed: C-CMOSCRT1-1.2, R-CMOSCRT1-6.2, U-CMOSCRT1-5.14 (Rx2_Cx2)
unnamed: C-CMOSCRT1-2.2, R-CMOSCRT1-8.2, U-CMOSCRT1-7.2 (Rx1_Cx1)
unnamed: C-CMOSCRT1-3.2, C-CMOSCRT1-6.1, D-CMOSCRT1-5.2 (A), D-CMOSCRT1-6.1 (K)
unnamed: C-CMOSCRT1-5.2, C-CMOSCRT1-7.1, D-CMOSCRT1-6.2 (A), D-CMOSCRT1-7.1 (K)
unnamed: C-CMOSCRT1-6.2, D-CMOSCRT1-7.2 (A), D-CMOSCRT1-9.1 (K)
unnamed: D1.1 (K), D2.1 (K), J-CMOSCRT1-2.1
unnamed: D2.2 (A), R-CMOSCRT1-3.1
unnamed: D-CMOSCRT1-1.2 (A), D-CMOSCRT1-2.1 (K), R-CMOSCRT1-1.1, R-CMOSCRT1-2.2, U-CMOSCRT1-10.7
unnamed: D-CMOSCRT1-3.2 (A), R-CMOSCRT1-3.2, R-CMOSCRT1-4.1, U-CMOSCRT1-10.9
unnamed: D-CMOSCRT1-4.2 (A), J-CMOSCRT1-3.1
unnamed: D-CMOSCRT1-8.1 (K), Q-CMOSCRT1-1.2 (B), R-CMOSCRT1-9.2, R-CMOSCRT1-10.2
unnamed: D-CMOSCRT1-8.2 (A), Q-CMOSCRT1-1.1 (C), R-CMOSCRT1-11.1, R-CMOSCRT1-12.1
unnamed: J-CMOSCRT1-1.1, R-CMOSCRT1-1.2
unnamed: J-CMOSCRT1-5.1, R-CMOSCRT1-12.2
unnamed: R-CMOSCRT1-5.2, R-CMOSCRT1-6.1
unnamed: R-CMOSCRT1-7.2, R-CMOSCRT1-8.1
unnamed: R-CMOSCRT1-9.1, U-CMOSCRT1-7.7 (~Q1)
unnamed: U-CMOSCRT1-1.1 (DA), U-CMOSCRT1-6.10 (Q0)
unnamed: U-CMOSCRT1-1.8 (Q3D), U-CMOSCRT1-2.1 (DA)
unnamed: U-CMOSCRT1-1.4 (DC), U-CMOSCRT1-1.10 (Q3B)
unnamed: U-CMOSCRT1-1.6 (DD), U-CMOSCRT1-1.11 (Q3B)
unnamed: U-CMOSCRT1-1.5 (DB), U-CMOSCRT1-1.13 (Q3A)
unnamed: U-CMOSCRT1-2.8 (Q3D), U-CMOSCRT1-6.4 (A1), U-CMOSCRT1-6.7 (B0)
unnamed: U-CMOSCRT1-2.4 (DC), U-CMOSCRT1-2.10 (Q3B)
unnamed: U-CMOSCRT1-2.6 (DD), U-CMOSCRT1-2.11 (Q3B)
unnamed: U-CMOSCRT1-2.5 (DB), U-CMOSCRT1-2.13 (Q3A)
unnamed: U-CMOSCRT1-3.1 (DA), U-CMOSCRT1-6.12 (Q2)
unnamed: U-CMOSCRT1-3.8 (Q3D), U-CMOSCRT1-4.1 (DA)
unnamed: U-CMOSCRT1-3.4 (DC), U-CMOSCRT1-3.10 (Q3B)
unnamed: U-CMOSCRT1-3.6 (DD), U-CMOSCRT1-3.11 (Q3B)
unnamed: U-CMOSCRT1-3.5 (DB), U-CMOSCRT1-3.13 (Q3A)
unnamed: U-CMOSCRT1-4.8 (Q3D), U-CMOSCRT1-6.2 (A2), U-CMOSCRT1-6.5 (B1)
unnamed: U-CMOSCRT1-4.4 (DC), U-CMOSCRT1-4.10 (Q3B)
unnamed: U-CMOSCRT1-4.6 (DD), U-CMOSCRT1-4.11 (Q3B)
unnamed: U-CMOSCRT1-4.5 (DB), U-CMOSCRT1-4.13 (Q3A)
unnamed: U-CMOSCRT1-6.11 (Q1), U-CMOSCRT1-7.3 (~Reset1)
unnamed: U-CMOSCRT1-10.10, U-CMOSCRT1-10.11
unnamed: U-CMOSCRT1-5.12 (+TR2), U-CMOSCRT1-6.3 (B2), U-CMOSCRT1-6.6 (A0), U-CMOSCRT1-10.12
Vdd: C-CMOSCRT1-4.1, D-CMOSCRT1-1.1 (K), D-CMOSCRT1-3.1 (K), D-CMOSCRT1-4.1 (K), Q-CMOSCRT1-1.3 (E), R-CMOSCRT1-2.1, R-CMOSCRT1-5.1, R-CMOSCRT1-7.1, R-CMOSCRT1-10.1, U-CMOSCRT1-1.14 (Vdd), U-CMOSCRT1-2.14 (Vdd), U-CMOSCRT1-3.14 (Vdd), U-CMOSCRT1-4.14 (Vdd), U-CMOSCRT1-5.16 (VDD), U-CMOSCRT1-6.16 (Vdd), U-CMOSCRT1-7.16 (VDD), U-CMOSCRT1-10.1 (VCC)
Vss: C-CMOSCRT1-1.1, C-CMOSCRT1-2.1, C-CMOSCRT1-3.1, C-CMOSCRT1-4.2, C-CMOSCRT1-5.1, D1.2 (A), D-CMOSCRT1-2.2 (A), D-CMOSCRT1-5.1 (K), J-CMOSCRT1-4.1, R-CMOSCRT1-4.2, U-CMOSCRT1-1.7 (Vss), U-CMOSCRT1-2.7 (Vss), U-CMOSCRT1-3.7 (Vss), U-CMOSCRT1-4.7 (Vss), U-CMOSCRT1-5.8 (VSS), U-CMOSCRT1-5.15 (Cx2), U-CMOSCRT1-6.8 (Vss), U-CMOSCRT1-7.1 (Cx1), U-CMOSCRT1-7.8 (VSS), U-CMOSCRT1-10.8 (VSS)

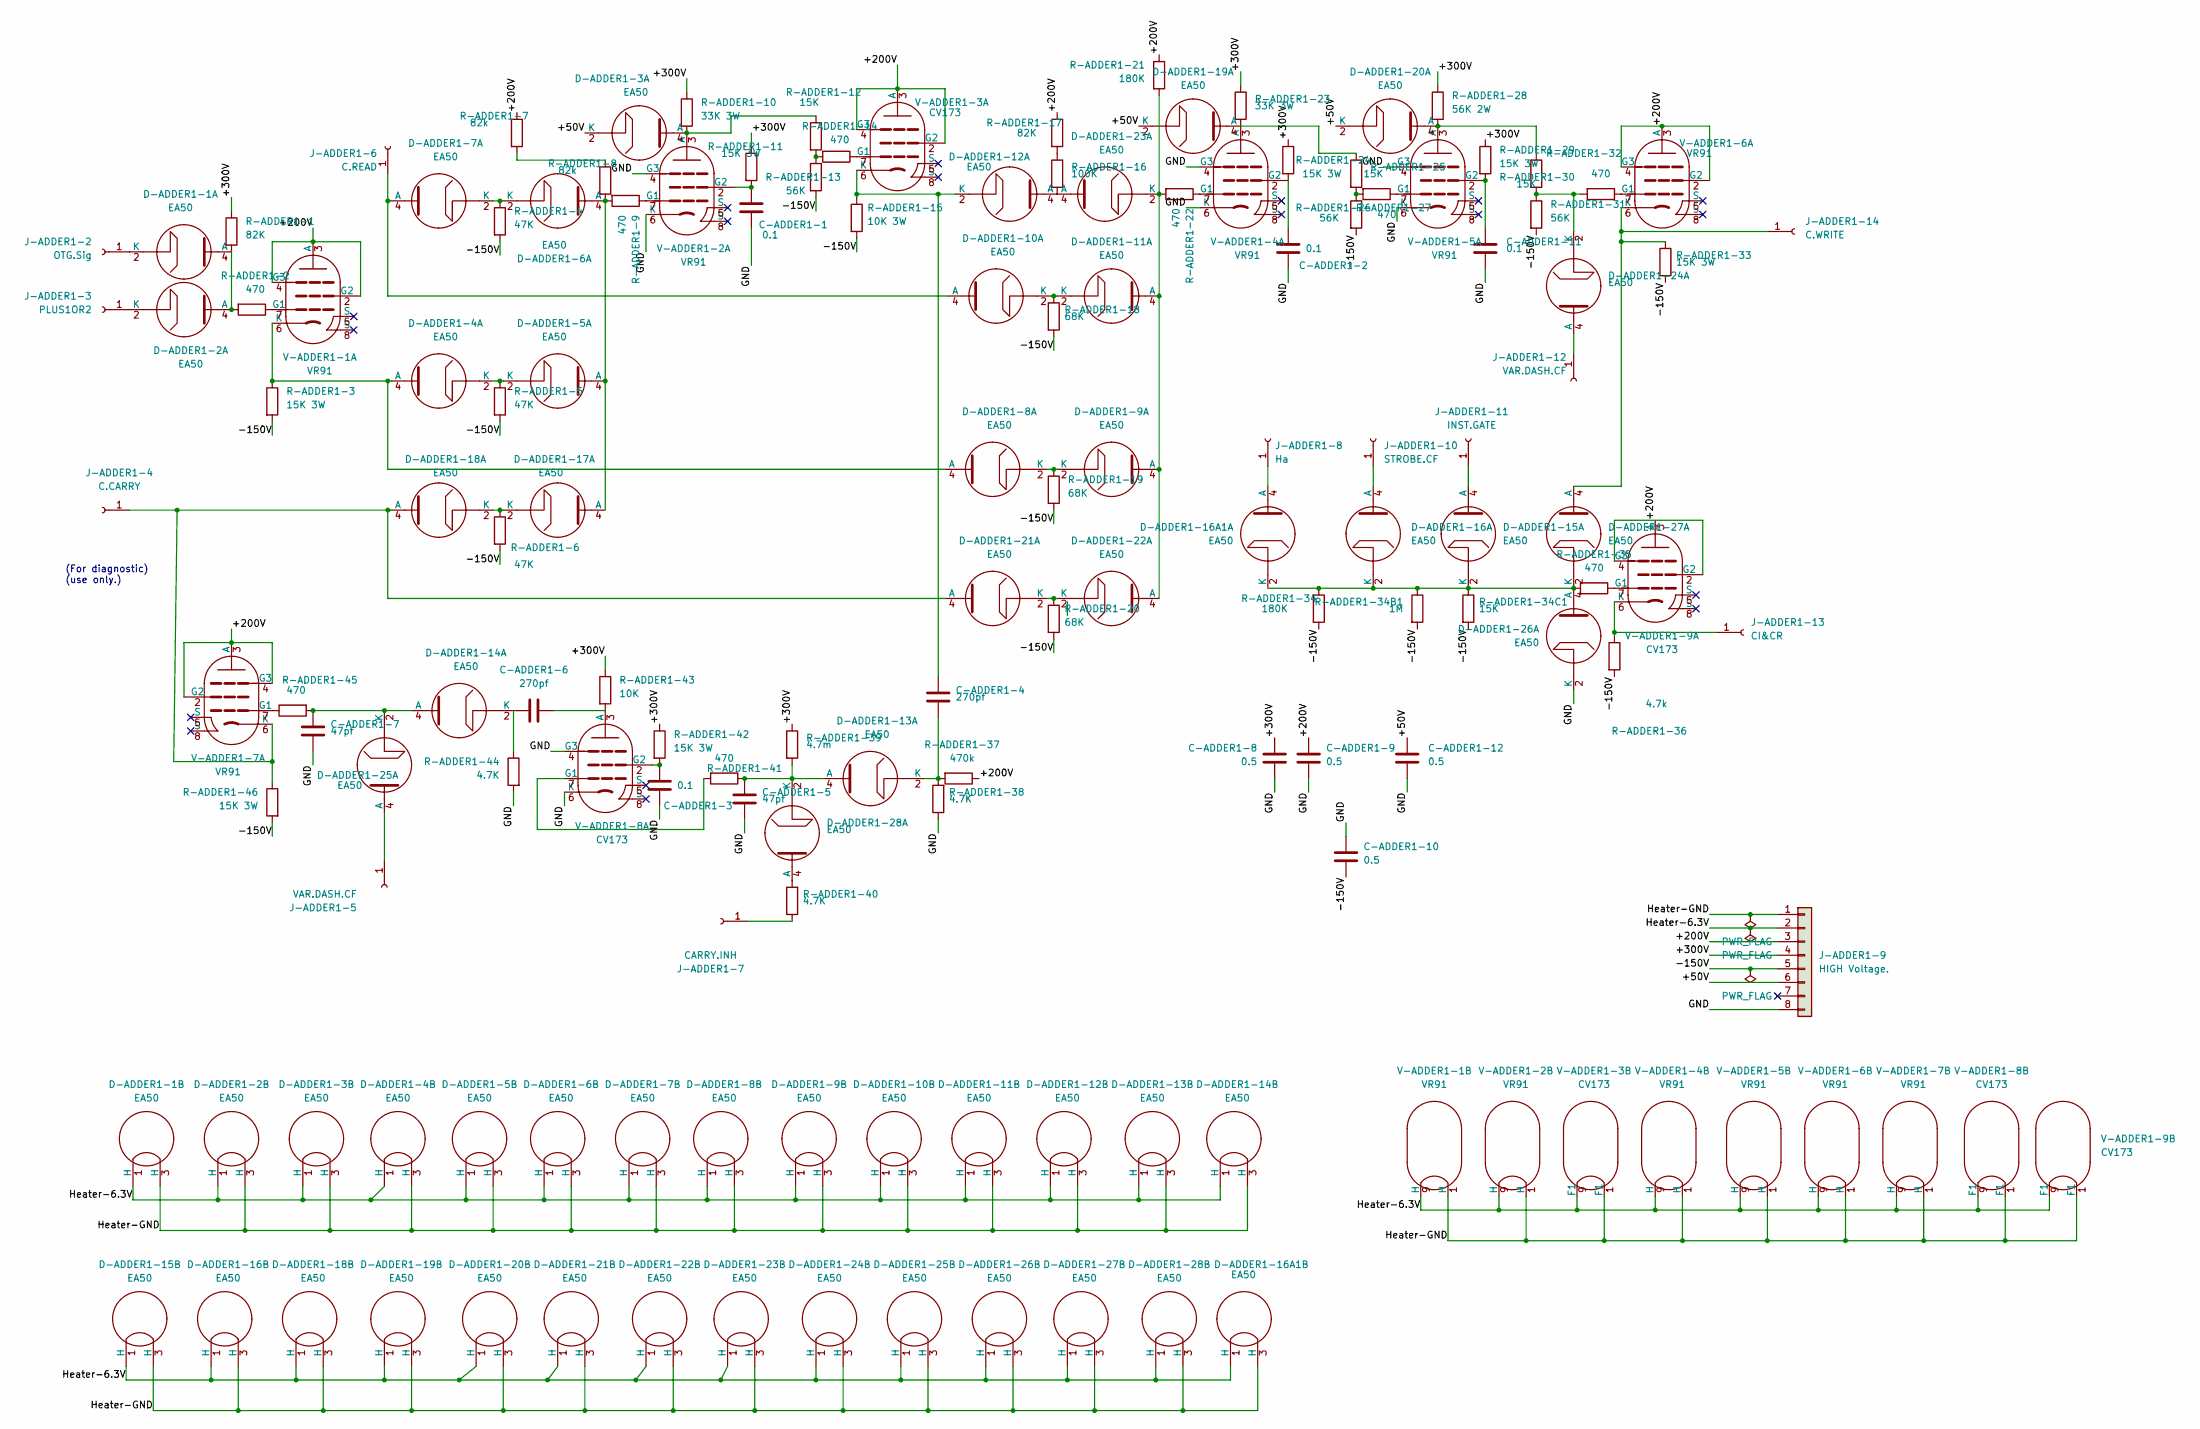
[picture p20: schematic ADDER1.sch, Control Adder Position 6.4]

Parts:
C-ADDER1-1, C-ADDER1-2, C-ADDER1-3, C-ADDER1-11: 0.1; C_Disc_D7.5mm_W5.0mm_P5.00mm
C-ADDER1-4, C-ADDER1-6: 270pf; C_Disc_D7.5mm_W5.0mm_P5.00mm
C-ADDER1-5, C-ADDER1-7: 47pf; C_Disc_D7.5mm_W5.0mm_P5.00mm
C-ADDER1-8, C-ADDER1-9, C-ADDER1-10, C-ADDER1-12: 0.5; C_Disc_D7.5mm_W5.0mm_P5.00mm
D-ADDER1-1, D-ADDER1-2, D-ADDER1-3, D-ADDER1-4, D-ADDER1-5, D-ADDER1-6, D-ADDER1-7, D-ADDER1-8, D-ADDER1-9, D-ADDER1-10, D-ADDER1-11, D-ADDER1-12, D-ADDER1-13, D-ADDER1-14, D-ADDER1-15, D-ADDER1-16, D-ADDER1-16A1, D-ADDER1-17, D-ADDER1-18, D-ADDER1-19, D-ADDER1-20, D-ADDER1-21, D-ADDER1-22, D-ADDER1-23, D-ADDER1-24, D-ADDER1-25, D-ADDER1-26, D-ADDER1-27, D-ADDER1-28: EA50; Valve_B3G
J-ADDER1-2: OTG.Sig; 242431
J-ADDER1-3: PLUS1OR2; 242431
J-ADDER1-4: C.CARRY; 242431
J-ADDER1-5, J-ADDER1-12: VAR.DASH.CF; 242431
J-ADDER1-6: C.READ; 242431
J-ADDER1-7: CARRY.INH; 242431
J-ADDER1-8: Ha; 242431
J-ADDER1-9: HIGH Voltage.; TE_MATE-N-LOK_1-770970-x_2x04_P4.14mm_Horizontal
J-ADDER1-10: STROBE.CF; 242431
J-ADDER1-11: INST.GATE; 242431
J-ADDER1-13: CI&CR; 242431
J-ADDER1-14: C.WRITE; 242431
R-ADDER1-1, R-ADDER1-17: 82K; R_Axial_DIN0516_L15.5mm_D5.0mm_P5.08mm_Vertical
R-ADDER1-2, R-ADDER1-9, R-ADDER1-14, R-ADDER1-22, R-ADDER1-27, R-ADDER1-32, R-ADDER1-35, R-ADDER1-41, R-ADDER1-45: 470; R_Axial_DIN0516_L15.5mm_D5.0mm_P5.08mm_Vertical
R-ADDER1-3, R-ADDER1-11, R-ADDER1-24, R-ADDER1-29, R-ADDER1-33, R-ADDER1-42, R-ADDER1-46: 15K 3W; R_Axial_DIN0516_L15.5mm_D5.0mm_P5.08mm_Vertical
R-ADDER1-4, R-ADDER1-5, R-ADDER1-6: 47K; R_Axial_DIN0516_L15.5mm_D5.0mm_P5.08mm_Vertical
R-ADDER1-7, R-ADDER1-8: 82k; R_Axial_DIN0516_L15.5mm_D5.0mm_P5.08mm_Vertical
R-ADDER1-10, R-ADDER1-23: 33K 3W; R_Axial_DIN0516_L15.5mm_D5.0mm_P5.08mm_Vertical
R-ADDER1-12, R-ADDER1-25, R-ADDER1-30, R-ADDER1-34C1: 15K; R_Axial_DIN0516_L15.5mm_D5.0mm_P5.08mm_Vertical
R-ADDER1-13, R-ADDER1-26, R-ADDER1-31: 56K; R_Axial_DIN0516_L15.5mm_D5.0mm_P5.08mm_Vertical
R-ADDER1-15: 10K 3W; R_Axial_DIN0516_L15.5mm_D5.0mm_P5.08mm_Vertical
R-ADDER1-16: 100K; R_Axial_DIN0516_L15.5mm_D5.0mm_P5.08mm_Vertical
R-ADDER1-18, R-ADDER1-19, R-ADDER1-20: 68K; R_Axial_DIN0516_L15.5mm_D5.0mm_P5.08mm_Vertical
R-ADDER1-21, R-ADDER1-34: 180K; R_Axial_DIN0516_L15.5mm_D5.0mm_P5.08mm_Vertical
R-ADDER1-28: 56K 2W; R_Axial_DIN0516_L15.5mm_D5.0mm_P5.08mm_Vertical
R-ADDER1-34B1: 1M; R_Axial_DIN0516_L15.5mm_D5.0mm_P5.08mm_Vertical
R-ADDER1-36: 4.7k; R_Axial_DIN0516_L15.5mm_D5.0mm_P5.08mm_Vertical
R-ADDER1-37: 470k; R_Axial_DIN0516_L15.5mm_D5.0mm_P5.08mm_Vertical
R-ADDER1-38, R-ADDER1-40, R-ADDER1-44: 4.7K; R_Axial_DIN0516_L15.5mm_D5.0mm_P5.08mm_Vertical
R-ADDER1-39: 4.7m; R_Axial_DIN0516_L15.5mm_D5.0mm_P5.08mm_Vertical
R-ADDER1-43: 10K; R_Axial_DIN0516_L15.5mm_D5.0mm_P5.08mm_Vertical
V-ADDER1-1, V-ADDER1-2, V-ADDER1-4, V-ADDER1-5, V-ADDER1-6, V-ADDER1-7: VR91; Valve_9Loctal
V-ADDER1-3, V-ADDER1-8, V-ADDER1-9: CV173; Valve_9Loctal

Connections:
/ADDER1/+50V: C-ADDER1-12.1, D-ADDER1-3.2 (K), D-ADDER1-19.2 (K), D-ADDER1-20.2 (K), J-ADDER1-9.6
/ADDER1/+200V: C-ADDER1-9.1, J-ADDER1-9.3, R-ADDER1-7.1, R-ADDER1-17.1, R-ADDER1-21.1, R-ADDER1-37.1, V-ADDER1-1.2 (G2), V-ADDER1-1.3 (A), V-ADDER1-1.4 (G3), V-ADDER1-3.2 (G2), V-ADDER1-3.3 (A), V-ADDER1-3.4 (G3), V-ADDER1-6.2 (G2), V-ADDER1-6.3 (A), V-ADDER1-6.4 (G3), V-ADDER1-7.2 (G2), V-ADDER1-7.3 (A), V-ADDER1-7.4 (G3), V-ADDER1-9.2 (G2), V-ADDER1-9.3 (A), V-ADDER1-9.4 (G3)
/ADDER1/+300V: C-ADDER1-8.1, J-ADDER1-9.4, R-ADDER1-1.1, R-ADDER1-10.1, R-ADDER1-11.1, R-ADDER1-23.1, R-ADDER1-24.1, R-ADDER1-28.1, R-ADDER1-29.1, R-ADDER1-39.1, R-ADDER1-42.1, R-ADDER1-43.1
/ADDER1/-150V: C-ADDER1-10.2, J-ADDER1-9.5, R-ADDER1-3.2, R-ADDER1-4.2, R-ADDER1-5.2, R-ADDER1-6.2, R-ADDER1-13.2, R-ADDER1-15.2, R-ADDER1-18.2, R-ADDER1-19.2, R-ADDER1-20.2, R-ADDER1-26.2, R-ADDER1-31.2, R-ADDER1-33.2, R-ADDER1-34.2, R-ADDER1-34B1.2, R-ADDER1-34C1.2, R-ADDER1-36.2, R-ADDER1-46.2
/ADDER1/GND: C-ADDER1-1.2, C-ADDER1-2.2, C-ADDER1-3.2, C-ADDER1-5.2, C-ADDER1-7.2, C-ADDER1-8.2, C-ADDER1-9.2, C-ADDER1-10.1, C-ADDER1-11.2, C-ADDER1-12.2, D-ADDER1-26.2 (K), J-ADDER1-9.8, R-ADDER1-38.1, R-ADDER1-44.2, V-ADDER1-2.4 (G3), V-ADDER1-2.6 (K), V-ADDER1-4.4 (G3), V-ADDER1-4.6 (K), V-ADDER1-5.4 (G3), V-ADDER1-5.6 (K), V-ADDER1-8.4 (G3), V-ADDER1-8.6 (K)
/ADDER1/Heater-6.3V: D-ADDER1-1.1 (H), D-ADDER1-2.1 (H), D-ADDER1-3.1 (H), D-ADDER1-4.1 (H), D-ADDER1-5.1 (H), D-ADDER1-6.1 (H), D-ADDER1-7.1 (H), D-ADDER1-8.1 (H), D-ADDER1-9.1 (H), D-ADDER1-10.1 (H), D-ADDER1-11.1 (H), D-ADDER1-12.1 (H), D-ADDER1-13.1 (H), D-ADDER1-14.1 (H), D-ADDER1-15.1 (H), D-ADDER1-16.1 (H), D-ADDER1-16A1.1 (H), D-ADDER1-18.1 (H), D-ADDER1-19.1 (H), D-ADDER1-20.1 (H), D-ADDER1-21.1 (H), D-ADDER1-22.1 (H), D-ADDER1-23.1 (H), D-ADDER1-24.1 (H), D-ADDER1-25.1 (H), D-ADDER1-26.1 (H), D-ADDER1-27.1 (H), D-ADDER1-28.1 (H), J-ADDER1-9.2, V-ADDER1-1.9 (H), V-ADDER1-2.9 (H), V-ADDER1-3.9 (F1), V-ADDER1-4.9 (H), V-ADDER1-5.9 (H), V-ADDER1-6.9 (H), V-ADDER1-7.9 (H), V-ADDER1-8.9 (F1), V-ADDER1-9.9 (F1)
/ADDER1/Heater-GND: D-ADDER1-1.3 (H), D-ADDER1-2.3 (H), D-ADDER1-3.3 (H), D-ADDER1-4.3 (H), D-ADDER1-5.3 (H), D-ADDER1-6.3 (H), D-ADDER1-7.3 (H), D-ADDER1-8.3 (H), D-ADDER1-9.3 (H), D-ADDER1-10.3 (H), D-ADDER1-11.3 (H), D-ADDER1-12.3 (H), D-ADDER1-13.3 (H), D-ADDER1-14.3 (H), D-ADDER1-15.3 (H), D-ADDER1-16.3 (H), D-ADDER1-16A1.3 (H), D-ADDER1-18.3 (H), D-ADDER1-19.3 (H), D-ADDER1-20.3 (H), D-ADDER1-21.3 (H), D-ADDER1-22.3 (H), D-ADDER1-23.3 (H), D-ADDER1-24.3 (H), D-ADDER1-25.3 (H), D-ADDER1-26.3 (H), D-ADDER1-27.3 (H), D-ADDER1-28.3 (H), J-ADDER1-9.1, V-ADDER1-1.1 (H), V-ADDER1-2.1 (H), V-ADDER1-3.1 (F1), V-ADDER1-4.1 (H), V-ADDER1-5.1 (H), V-ADDER1-6.1 (H), V-ADDER1-7.1 (H), V-ADDER1-8.1 (F1), V-ADDER1-9.1 (F1)
unnamed: C-ADDER1-1.1, R-ADDER1-11.2, V-ADDER1-2.2 (G2)
unnamed: C-ADDER1-2.1, R-ADDER1-24.2, V-ADDER1-4.2 (G2)
unnamed: C-ADDER1-3.1, R-ADDER1-42.2, V-ADDER1-8.2 (G2)
unnamed: C-ADDER1-4.1, D-ADDER1-12.2 (K), R-ADDER1-15.1, V-ADDER1-3.6 (K)
unnamed: C-ADDER1-4.2, D-ADDER1-13.2 (K), R-ADDER1-37.2, R-ADDER1-38.2
unnamed: C-ADDER1-5.1, D-ADDER1-13.4 (A), D-ADDER1-28.2 (K), R-ADDER1-39.2, R-ADDER1-41.1
unnamed: C-ADDER1-6.1, R-ADDER1-43.2, V-ADDER1-8.3 (A)
unnamed: C-ADDER1-6.2, D-ADDER1-14.2 (K), R-ADDER1-44.1
unnamed: C-ADDER1-7.1, D-ADDER1-14.4 (A), D-ADDER1-25.2 (K), R-ADDER1-45.2
unnamed: C-ADDER1-11.1, R-ADDER1-29.2, V-ADDER1-5.2 (G2)
unnamed: D-ADDER1-1.2 (K), J-ADDER1-2.1
unnamed: D-ADDER1-1.4 (A), D-ADDER1-2.4 (A), R-ADDER1-1.2, R-ADDER1-2.2
unnamed: D-ADDER1-2.2 (K), J-ADDER1-3.1
unnamed: D-ADDER1-3.4 (A), R-ADDER1-10.2, R-ADDER1-12.1, V-ADDER1-2.3 (A)
unnamed: D-ADDER1-4.2 (K), D-ADDER1-5.2 (K), R-ADDER1-5.1
unnamed: D-ADDER1-4.4 (A), D-ADDER1-8.4 (A), R-ADDER1-3.1, V-ADDER1-1.6 (K)
unnamed: D-ADDER1-6.2 (K), D-ADDER1-7.2 (K), R-ADDER1-4.1
unnamed: D-ADDER1-8.2 (K), D-ADDER1-9.2 (K), R-ADDER1-19.1
unnamed: D-ADDER1-10.2 (K), D-ADDER1-11.2 (K), R-ADDER1-18.1
unnamed: D-ADDER1-7.4 (A), D-ADDER1-10.4 (A), J-ADDER1-6.1
unnamed: D-ADDER1-9.4 (A), D-ADDER1-11.4 (A), D-ADDER1-22.4 (A), D-ADDER1-23.2 (K), R-ADDER1-21.2, R-ADDER1-22.2
unnamed: D-ADDER1-12.4 (A), D-ADDER1-23.4 (A), R-ADDER1-16.2
unnamed: D-ADDER1-15.2 (K), D-ADDER1-16.2 (K), D-ADDER1-16A1.2 (K), D-ADDER1-26.4 (A), D-ADDER1-27.2 (K), R-ADDER1-34.1, R-ADDER1-34B1.1, R-ADDER1-34C1.1, R-ADDER1-35.2
unnamed: D-ADDER1-15.4 (A), J-ADDER1-11.1
unnamed: D-ADDER1-16.4 (A), J-ADDER1-10.1
unnamed: D-ADDER1-16A1.4 (A), J-ADDER1-8.1
unnamed: D-ADDER1-17.2 (K), D-ADDER1-18.2 (K), R-ADDER1-6.1
unnamed: D-ADDER1-5.4 (A), D-ADDER1-6.4 (A), D-ADDER1-17.4 (A), R-ADDER1-8.2, R-ADDER1-9.2
unnamed: D-ADDER1-18.4 (A), D-ADDER1-21.4 (A), J-ADDER1-4.1, R-ADDER1-46.1, V-ADDER1-7.6 (K)
unnamed: D-ADDER1-19.4 (A), R-ADDER1-23.2, R-ADDER1-25.1, V-ADDER1-4.3 (A)
unnamed: D-ADDER1-20.4 (A), R-ADDER1-28.2, R-ADDER1-30.1, V-ADDER1-5.3 (A)
unnamed: D-ADDER1-21.2 (K), D-ADDER1-22.2 (K), R-ADDER1-20.1
unnamed: D-ADDER1-24.2 (K), R-ADDER1-30.2, R-ADDER1-31.1, R-ADDER1-32.2
unnamed: D-ADDER1-24.4 (A), J-ADDER1-12.1
unnamed: D-ADDER1-25.4 (A), J-ADDER1-5.1
unnamed: D-ADDER1-27.4 (A), J-ADDER1-14.1, R-ADDER1-33.1, V-ADDER1-6.6 (K)
unnamed: D-ADDER1-28.4 (A), R-ADDER1-40.2
unnamed: J-ADDER1-7.1, R-ADDER1-40.1
unnamed: J-ADDER1-13.1, R-ADDER1-36.1, V-ADDER1-9.6 (K)
unnamed: R-ADDER1-2.1, V-ADDER1-1.7 (G1)
unnamed: R-ADDER1-7.2, R-ADDER1-8.1
unnamed: R-ADDER1-9.1, V-ADDER1-2.7 (G1)
unnamed: R-ADDER1-12.2, R-ADDER1-13.1, R-ADDER1-14.2
unnamed: R-ADDER1-14.1, V-ADDER1-3.7 (G1)
unnamed: R-ADDER1-16.1, R-ADDER1-17.2
unnamed: R-ADDER1-22.1, V-ADDER1-4.7 (G1)
unnamed: R-ADDER1-25.2, R-ADDER1-26.1, R-ADDER1-27.2
unnamed: R-ADDER1-27.1, V-ADDER1-5.7 (G1)
unnamed: R-ADDER1-32.1, V-ADDER1-6.7 (G1)
unnamed: R-ADDER1-35.1, V-ADDER1-9.7 (G1)
unnamed: R-ADDER1-41.2, V-ADDER1-8.7 (G1)
unnamed: R-ADDER1-45.1, V-ADDER1-7.7 (G1)

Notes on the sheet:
(For diagnostic) (use only.)

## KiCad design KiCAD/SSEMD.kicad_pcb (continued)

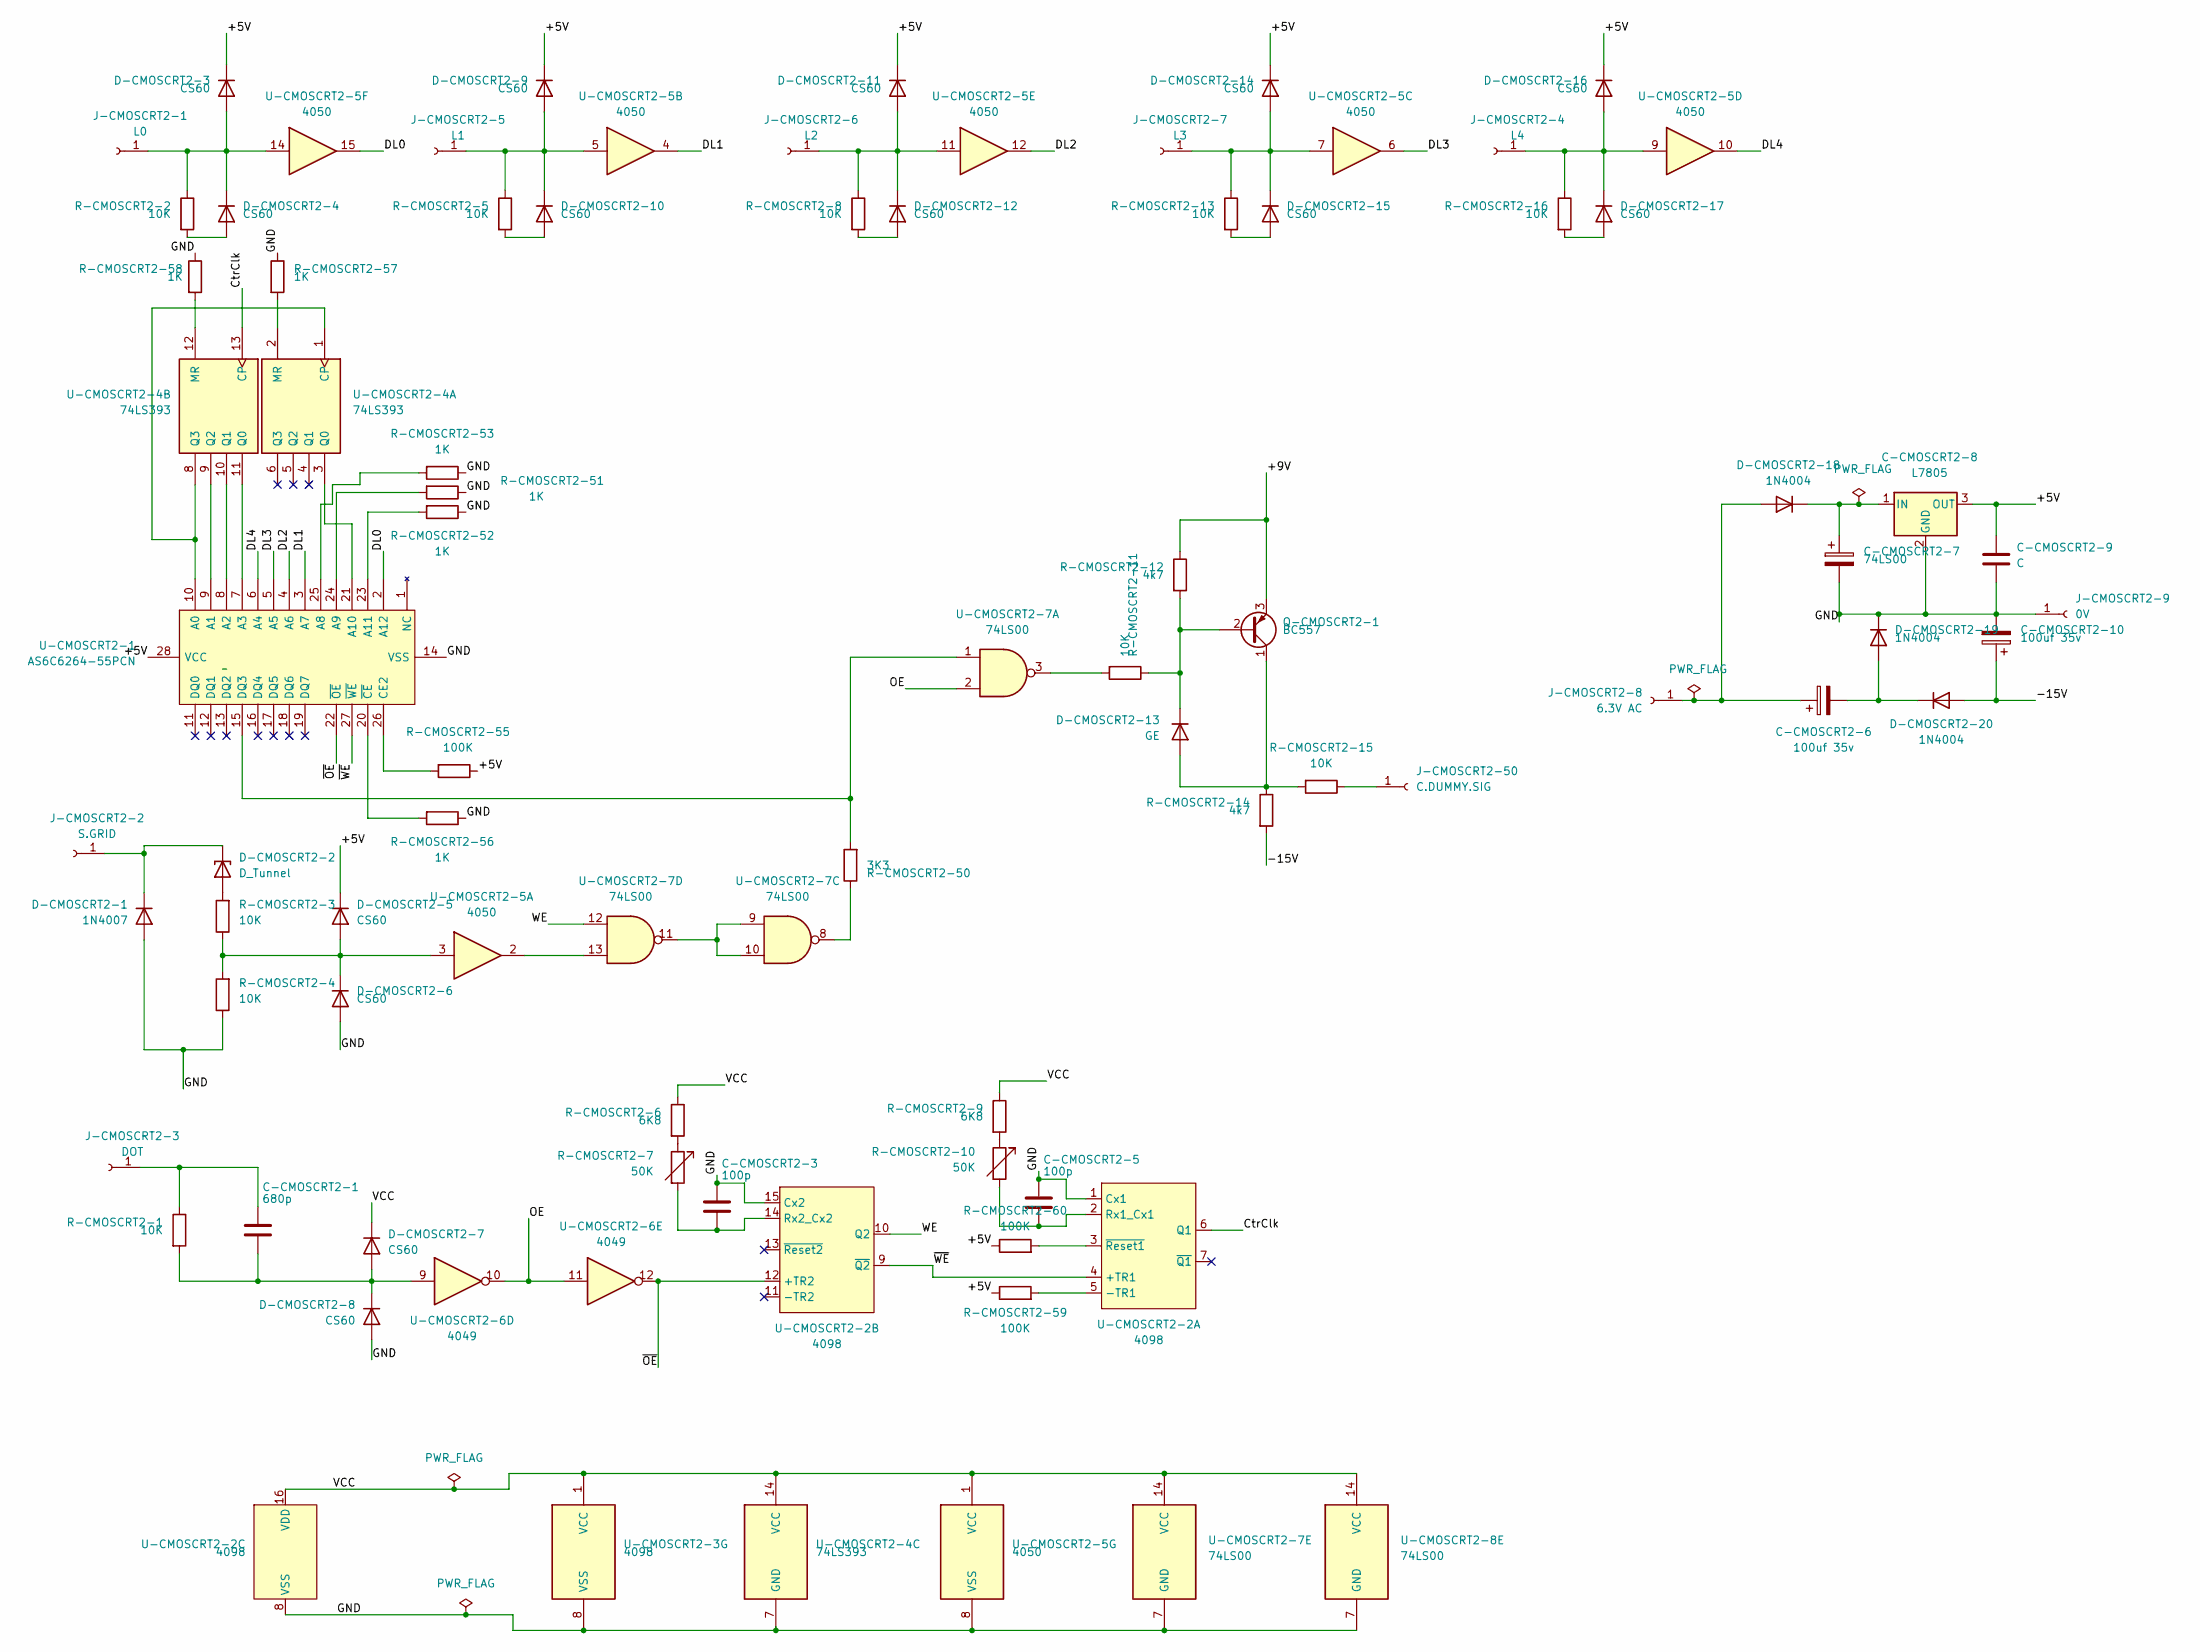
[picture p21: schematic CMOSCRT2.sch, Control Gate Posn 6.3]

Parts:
C-CMOSCRT2-1: 680p; C_Disc_D7.5mm_W5.0mm_P5.00mm
C-CMOSCRT2-3, C-CMOSCRT2-5: 100p; C_Disc_D7.5mm_W5.0mm_P5.00mm
C-CMOSCRT2-6, C-CMOSCRT2-10: 100uf 35v; CP_Radial_D5.0mm_P2.50mm
C-CMOSCRT2-7: 74LS00; CP_Radial_D5.0mm_P2.50mm
C-CMOSCRT2-8: L7805; TO-220-3_Vertical
C-CMOSCRT2-9: C; C_Disc_D3.8mm_W2.6mm_P2.50mm
D-CMOSCRT2-1: 1N4007; D_DO-41_SOD81_P10.16mm_Horizontal
D-CMOSCRT2-2: D_Tunnel; D_DO-41_SOD81_P10.16mm_Horizontal
D-CMOSCRT2-3, D-CMOSCRT2-4, D-CMOSCRT2-5, D-CMOSCRT2-6, D-CMOSCRT2-7, D-CMOSCRT2-8, D-CMOSCRT2-9, D-CMOSCRT2-10, D-CMOSCRT2-11, D-CMOSCRT2-12, D-CMOSCRT2-14, D-CMOSCRT2-15, D-CMOSCRT2-16, D-CMOSCRT2-17: CS60; D_DO-41_SOD81_P10.16mm_Horizontal
D-CMOSCRT2-13: GE; D_DO-41_SOD81_P10.16mm_Horizontal
D-CMOSCRT2-18, D-CMOSCRT2-19, D-CMOSCRT2-20: 1N4004; D_DO-41_SOD81_P10.16mm_Horizontal
J-CMOSCRT2-1: L0; 242431
J-CMOSCRT2-2: S.GRID; 242431
J-CMOSCRT2-3: DOT; 242431
J-CMOSCRT2-4: L4; 242431
J-CMOSCRT2-5: L1; 242431
J-CMOSCRT2-6: L2; 242431
J-CMOSCRT2-7: L3; 242431
J-CMOSCRT2-8: 6.3V AC; 242431
J-CMOSCRT2-9: 0V; 242431
J-CMOSCRT2-50: C.DUMMY.SIG; 242431
Q-CMOSCRT2-1: BC557; TO-92_Inline
R-CMOSCRT2-1, R-CMOSCRT2-2, R-CMOSCRT2-3, R-CMOSCRT2-4, R-CMOSCRT2-5, R-CMOSCRT2-8, R-CMOSCRT2-11, R-CMOSCRT2-13, R-CMOSCRT2-15, R-CMOSCRT2-16: 10K; R_Axial_DIN0516_L15.5mm_D5.0mm_P5.08mm_Vertical
R-CMOSCRT2-6, R-CMOSCRT2-9: 6K8; R_Axial_DIN0516_L15.5mm_D5.0mm_P5.08mm_Vertical
R-CMOSCRT2-7, R-CMOSCRT2-10: 50K; Potentiometer_Omeg_PC16BU_Vertical
R-CMOSCRT2-12, R-CMOSCRT2-14: 4k7; R_Axial_DIN0516_L15.5mm_D5.0mm_P5.08mm_Vertical
R-CMOSCRT2-50: 3K3; R_Axial_DIN0516_L15.5mm_D5.0mm_P5.08mm_Vertical
R-CMOSCRT2-51, R-CMOSCRT2-52, R-CMOSCRT2-53, R-CMOSCRT2-56, R-CMOSCRT2-57, R-CMOSCRT2-58: 1K; R_Axial_DIN0516_L15.5mm_D5.0mm_P5.08mm_Vertical
R-CMOSCRT2-55, R-CMOSCRT2-59, R-CMOSCRT2-60: 100K; R_Axial_DIN0516_L15.5mm_D5.0mm_P5.08mm_Vertical
U-CMOSCRT2-1: AS6C6264-55PCN; DIP1524W51P254L3632H394Q28N; Manufacturer_Part_Number AS6C6264-55PCN; Mouser Part Number 913-AS6C6264-55PCN
U-CMOSCRT2-2: 4098; DIP-16_W7.62mm
U-CMOSCRT2-3: 4098; DIP-14_W7.62mm
U-CMOSCRT2-4: 74LS393; DIP-14_W7.62mm
U-CMOSCRT2-5: 4050; DIP-16_W7.62mm
U-CMOSCRT2-6: 4049; DIP-14_W7.62mm
U-CMOSCRT2-7, U-CMOSCRT2-8: 74LS00; DIP-14_W7.62mm

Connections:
/CMOSCRT2/+5V: C-CMOSCRT2-8.3 (OUT), C-CMOSCRT2-9.1, D-CMOSCRT2-3.1 (K), D-CMOSCRT2-5.1 (K), D-CMOSCRT2-9.1 (K), D-CMOSCRT2-11.1 (K), D-CMOSCRT2-14.1 (K), D-CMOSCRT2-16.1 (K), R-CMOSCRT2-55.1, R-CMOSCRT2-59.1, R-CMOSCRT2-60.1, U-CMOSCRT2-1.28 (VCC)
/CMOSCRT2/+9V: Q-CMOSCRT2-1.3 (E), R-CMOSCRT2-12.1
/CMOSCRT2/-15V: C-CMOSCRT2-10.1, D-CMOSCRT2-20.2 (A), R-CMOSCRT2-14.2
/CMOSCRT2/CtrClk: U-CMOSCRT2-2.6 (Q1), U-CMOSCRT2-4.13 (CP)
/CMOSCRT2/DL0: U-CMOSCRT2-1.2 (A12), U-CMOSCRT2-5.15
/CMOSCRT2/DL1: U-CMOSCRT2-1.3 (A7), U-CMOSCRT2-5.4
/CMOSCRT2/DL2: U-CMOSCRT2-1.4 (A6), U-CMOSCRT2-5.12
/CMOSCRT2/DL3: U-CMOSCRT2-1.5 (A5), U-CMOSCRT2-5.6
/CMOSCRT2/DL4: U-CMOSCRT2-1.6 (A4), U-CMOSCRT2-5.10
/CMOSCRT2/GND: C-CMOSCRT2-3.1, C-CMOSCRT2-5.1, C-CMOSCRT2-7.2, C-CMOSCRT2-8.2 (GND), C-CMOSCRT2-9.2, C-CMOSCRT2-10.2, D-CMOSCRT2-1.2 (A), D-CMOSCRT2-6.2 (A), D-CMOSCRT2-8.2 (A), D-CMOSCRT2-19.1 (K), J-CMOSCRT2-9.1, R-CMOSCRT2-4.1, R-CMOSCRT2-51.1, R-CMOSCRT2-52.1, R-CMOSCRT2-53.1, R-CMOSCRT2-56.1, R-CMOSCRT2-57.1, R-CMOSCRT2-58.1, U-CMOSCRT2-1.14 (VSS), U-CMOSCRT2-2.1 (Cx1), U-CMOSCRT2-2.8 (VSS), U-CMOSCRT2-2.15 (Cx2), U-CMOSCRT2-3.8 (VSS), U-CMOSCRT2-4.7 (GND), U-CMOSCRT2-5.8 (VSS), U-CMOSCRT2-7.7 (GND), U-CMOSCRT2-8.7 (GND)
/CMOSCRT2/OE: U-CMOSCRT2-6.10, U-CMOSCRT2-6.11, U-CMOSCRT2-7.2
/CMOSCRT2/VCC: D-CMOSCRT2-7.1 (K), R-CMOSCRT2-6.1, R-CMOSCRT2-9.1, U-CMOSCRT2-2.16 (VDD), U-CMOSCRT2-3.1 (VCC), U-CMOSCRT2-4.14 (VCC), U-CMOSCRT2-5.1 (VCC), U-CMOSCRT2-7.14 (VCC), U-CMOSCRT2-8.14 (VCC)
/CMOSCRT2/WE: U-CMOSCRT2-2.10 (Q2), U-CMOSCRT2-7.12
/CMOSCRT2/~OE: U-CMOSCRT2-1.22 (~OE), U-CMOSCRT2-2.12 (+TR2), U-CMOSCRT2-6.12
/CMOSCRT2/~WE: U-CMOSCRT2-1.27 (~WE), U-CMOSCRT2-2.4 (+TR1), U-CMOSCRT2-2.9 (~Q2)
unnamed: C-CMOSCRT2-1.1, J-CMOSCRT2-3.1, R-CMOSCRT2-1.1
unnamed: C-CMOSCRT2-1.2, D-CMOSCRT2-7.2 (A), D-CMOSCRT2-8.1 (K), R-CMOSCRT2-1.2, U-CMOSCRT2-6.9
unnamed: C-CMOSCRT2-3.2, R-CMOSCRT2-7.2, U-CMOSCRT2-2.14 (Rx2_Cx2)
unnamed: C-CMOSCRT2-5.2, R-CMOSCRT2-10.2, U-CMOSCRT2-2.2 (Rx1_Cx1)
unnamed: C-CMOSCRT2-6.1, D-CMOSCRT2-18.2 (A), J-CMOSCRT2-8.1
unnamed: C-CMOSCRT2-6.2, D-CMOSCRT2-19.2 (A), D-CMOSCRT2-20.1 (K)
unnamed: C-CMOSCRT2-7.1, C-CMOSCRT2-8.1 (IN), D-CMOSCRT2-18.1 (K)
unnamed: D-CMOSCRT2-1.1 (K), D-CMOSCRT2-2.1 (K), J-CMOSCRT2-2.1
unnamed: D-CMOSCRT2-2.2 (A), R-CMOSCRT2-3.2
unnamed: D-CMOSCRT2-3.2 (A), D-CMOSCRT2-4.1 (K), J-CMOSCRT2-1.1, R-CMOSCRT2-2.1, U-CMOSCRT2-5.14
unnamed: D-CMOSCRT2-4.2 (A), R-CMOSCRT2-2.2
unnamed: D-CMOSCRT2-5.2 (A), D-CMOSCRT2-6.1 (K), R-CMOSCRT2-3.1, R-CMOSCRT2-4.2, U-CMOSCRT2-5.3
unnamed: D-CMOSCRT2-9.2 (A), D-CMOSCRT2-10.1 (K), J-CMOSCRT2-5.1, R-CMOSCRT2-5.1, U-CMOSCRT2-5.5
unnamed: D-CMOSCRT2-10.2 (A), R-CMOSCRT2-5.2
unnamed: D-CMOSCRT2-11.2 (A), D-CMOSCRT2-12.1 (K), J-CMOSCRT2-6.1, R-CMOSCRT2-8.1, U-CMOSCRT2-5.11
unnamed: D-CMOSCRT2-12.2 (A), R-CMOSCRT2-8.2
unnamed: D-CMOSCRT2-13.1 (K), Q-CMOSCRT2-1.2 (B), R-CMOSCRT2-11.1, R-CMOSCRT2-12.2
unnamed: D-CMOSCRT2-13.2 (A), Q-CMOSCRT2-1.1 (C), R-CMOSCRT2-14.1, R-CMOSCRT2-15.2
unnamed: D-CMOSCRT2-14.2 (A), D-CMOSCRT2-15.1 (K), J-CMOSCRT2-7.1, R-CMOSCRT2-13.1, U-CMOSCRT2-5.7
unnamed: D-CMOSCRT2-15.2 (A), R-CMOSCRT2-13.2
unnamed: D-CMOSCRT2-16.2 (A), D-CMOSCRT2-17.1 (K), J-CMOSCRT2-4.1, R-CMOSCRT2-16.1, U-CMOSCRT2-5.9
unnamed: D-CMOSCRT2-17.2 (A), R-CMOSCRT2-16.2
unnamed: J-CMOSCRT2-50.1, R-CMOSCRT2-15.1
unnamed: R-CMOSCRT2-6.2, R-CMOSCRT2-7.1
unnamed: R-CMOSCRT2-9.2, R-CMOSCRT2-10.1
unnamed: R-CMOSCRT2-11.2, U-CMOSCRT2-7.3
unnamed: R-CMOSCRT2-50.1, U-CMOSCRT2-7.8
unnamed: R-CMOSCRT2-50.2, U-CMOSCRT2-1.15 (DQ3), U-CMOSCRT2-7.1
unnamed: R-CMOSCRT2-51.2, U-CMOSCRT2-1.24 (A9)
unnamed: R-CMOSCRT2-52.2, U-CMOSCRT2-1.23 (A11)
unnamed: R-CMOSCRT2-53.2, U-CMOSCRT2-1.25 (A8)
unnamed: R-CMOSCRT2-55.2, U-CMOSCRT2-1.26 (CE2)
unnamed: R-CMOSCRT2-56.2, U-CMOSCRT2-1.20 (~CE)
unnamed: R-CMOSCRT2-57.2, U-CMOSCRT2-4.2 (MR)
unnamed: R-CMOSCRT2-58.2, U-CMOSCRT2-4.12 (MR)
unnamed: R-CMOSCRT2-59.2, U-CMOSCRT2-2.5 (-TR1)
unnamed: R-CMOSCRT2-60.2, U-CMOSCRT2-2.3 (~Reset1)
unnamed: U-CMOSCRT2-1.7 (A3), U-CMOSCRT2-4.11 (Q0)
unnamed: U-CMOSCRT2-1.8 (A2), U-CMOSCRT2-4.10 (Q1)
unnamed: U-CMOSCRT2-1.9 (A1), U-CMOSCRT2-4.9 (Q2)
unnamed: U-CMOSCRT2-1.10 (A0), U-CMOSCRT2-4.1 (CP), U-CMOSCRT2-4.8 (Q3)
unnamed: U-CMOSCRT2-1.21 (A10), U-CMOSCRT2-4.3 (Q0)
unnamed: U-CMOSCRT2-5.2, U-CMOSCRT2-7.13
unnamed: U-CMOSCRT2-7.9, U-CMOSCRT2-7.10, U-CMOSCRT2-7.11

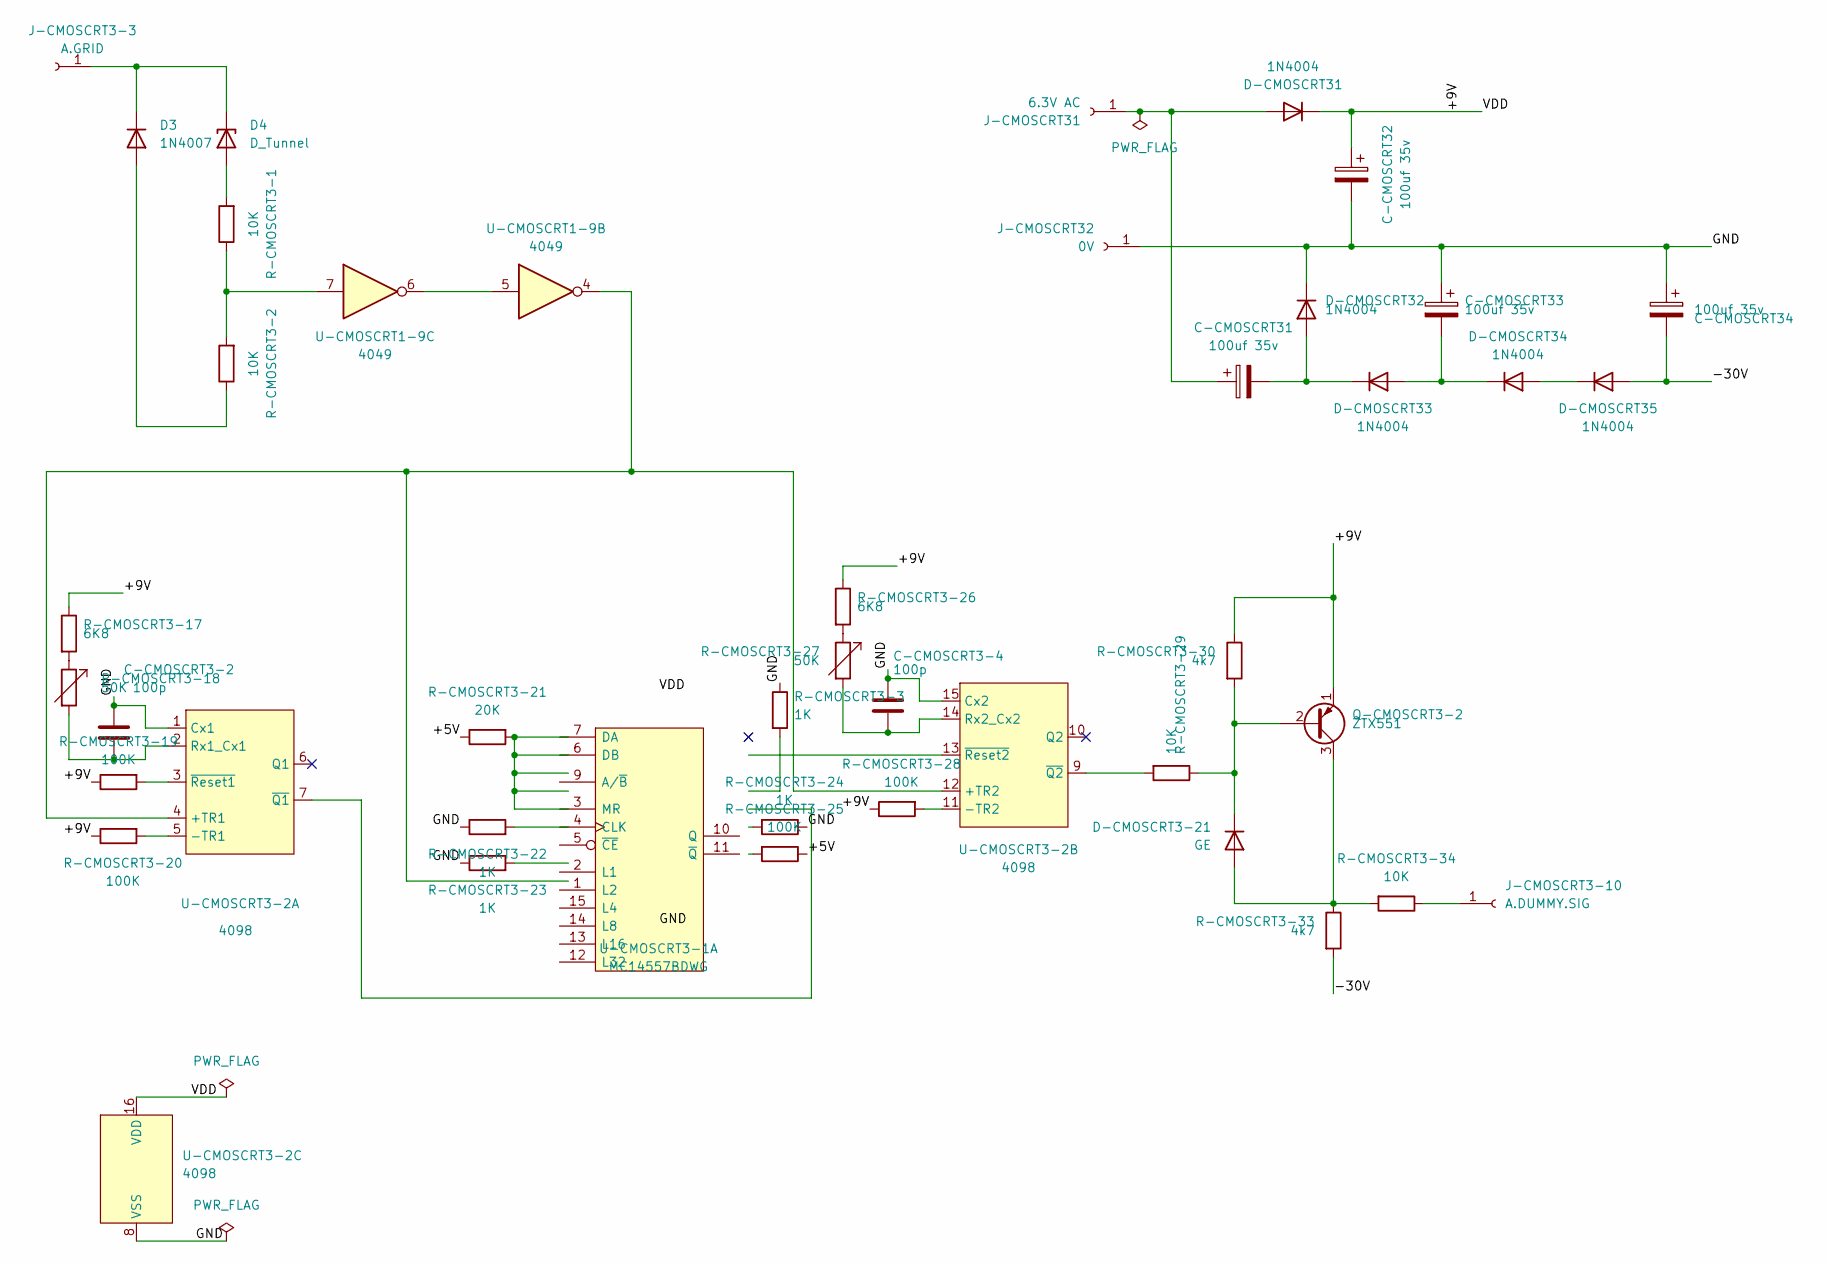
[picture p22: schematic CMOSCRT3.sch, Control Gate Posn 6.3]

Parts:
C-CMOSCRT3-2, C-CMOSCRT3-4: 100p; C_Disc_D7.5mm_W5.0mm_P5.00mm
C-CMOSCRT31, C-CMOSCRT32, C-CMOSCRT33, C-CMOSCRT34: 100uf 35v; CP_Radial_D7.5mm_P2.50mm
D3: 1N4007; D_DO-41_SOD81_P10.16mm_Horizontal
D4: D_Tunnel; D_DO-201_P15.24mm_Horizontal
D-CMOSCRT3-21: GE; D_DO-41_SOD81_P10.16mm_Horizontal
D-CMOSCRT31, D-CMOSCRT32, D-CMOSCRT33, D-CMOSCRT34, D-CMOSCRT35: 1N4004; D_DO-41_SOD81_P10.16mm_Horizontal
J-CMOSCRT3-3: A.GRID; 242431
J-CMOSCRT3-10: A.DUMMY.SIG; 242431
J-CMOSCRT31: 6.3V AC; 242431
J-CMOSCRT32: 0V; 242431
Q-CMOSCRT3-2: ZTX551; TO-92_Inline
R-CMOSCRT3-1, R-CMOSCRT3-2, R-CMOSCRT3-29, R-CMOSCRT3-34: 10K; R_Axial_DIN0516_L15.5mm_D5.0mm_P5.08mm_Vertical
R-CMOSCRT3-3, R-CMOSCRT3-22, R-CMOSCRT3-23, R-CMOSCRT3-24: 1K; R_Axial_DIN0516_L15.5mm_D5.0mm_P5.08mm_Vertical
R-CMOSCRT3-17, R-CMOSCRT3-26: 6K8; R_Axial_DIN0516_L15.5mm_D5.0mm_P5.08mm_Vertical
R-CMOSCRT3-18: 50K; Potentiometer_Omeg_PC16BU_Vertical
R-CMOSCRT3-19, R-CMOSCRT3-20, R-CMOSCRT3-25, R-CMOSCRT3-28: 100K; R_Axial_DIN0516_L15.5mm_D5.0mm_P5.08mm_Vertical
R-CMOSCRT3-21: 20K; R_Axial_DIN0516_L15.5mm_D5.0mm_P5.08mm_Vertical
R-CMOSCRT3-27: 50K; R_Axial_DIN0516_L15.5mm_D5.0mm_P5.08mm_Vertical
R-CMOSCRT3-30, R-CMOSCRT3-33: 4k7; R_Axial_DIN0516_L15.5mm_D5.0mm_P5.08mm_Vertical
U-CMOSCRT1-9: 4049; DIP-14_W7.62mm
U-CMOSCRT3-1: MC14557BDWG; DIP-16_W7.62mm; Manufacturer_Part_Number MC14557BDWG; Mouser Part Number 863-MC14557BDWG
U-CMOSCRT3-2: 4098; DIP-16_W7.62mm

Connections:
/CMOSCRT3/+5V: R-CMOSCRT3-21.1, R-CMOSCRT3-25.1
/CMOSCRT3/+9V: C-CMOSCRT32.1, D-CMOSCRT31.1 (K), Q-CMOSCRT3-2.1 (E), R-CMOSCRT3-17.1, R-CMOSCRT3-19.1, R-CMOSCRT3-20.1, R-CMOSCRT3-26.1, R-CMOSCRT3-28.1, R-CMOSCRT3-30.1, U-CMOSCRT3-2.16 (VDD)
/CMOSCRT3/-30V: C-CMOSCRT34.2, D-CMOSCRT35.2 (A), R-CMOSCRT3-33.2
/CMOSCRT3/GND: C-CMOSCRT3-2.1, C-CMOSCRT3-4.1, C-CMOSCRT32.2, C-CMOSCRT33.1, C-CMOSCRT34.1, D-CMOSCRT32.1 (K), J-CMOSCRT32.1, R-CMOSCRT3-3.1, R-CMOSCRT3-22.1, R-CMOSCRT3-23.1, R-CMOSCRT3-24.1, U-CMOSCRT3-2.1 (Cx1), U-CMOSCRT3-2.8 (VSS), U-CMOSCRT3-2.15 (Cx2)
unnamed: C-CMOSCRT3-2.2, R-CMOSCRT3-18.2, U-CMOSCRT3-2.2 (Rx1_Cx1)
unnamed: C-CMOSCRT3-4.2, R-CMOSCRT3-27.2, U-CMOSCRT3-2.14 (Rx2_Cx2)
unnamed: C-CMOSCRT31.1, D-CMOSCRT31.2 (A), J-CMOSCRT31.1
unnamed: C-CMOSCRT31.2, D-CMOSCRT32.2 (A), D-CMOSCRT33.1 (K)
unnamed: C-CMOSCRT33.2, D-CMOSCRT33.2 (A), D-CMOSCRT34.1 (K)
unnamed: D3.1 (K), D4.1 (K), J-CMOSCRT3-3.1
unnamed: D3.2 (A), R-CMOSCRT3-2.1
unnamed: D4.2 (A), R-CMOSCRT3-1.2
unnamed: D-CMOSCRT3-21.1 (K), Q-CMOSCRT3-2.2 (B), R-CMOSCRT3-29.1, R-CMOSCRT3-30.2
unnamed: D-CMOSCRT3-21.2 (A), Q-CMOSCRT3-2.3 (C), R-CMOSCRT3-33.1, R-CMOSCRT3-34.2
unnamed: D-CMOSCRT34.2 (A), D-CMOSCRT35.1 (K)
unnamed: J-CMOSCRT3-10.1, R-CMOSCRT3-34.1
unnamed: R-CMOSCRT3-1.1, R-CMOSCRT3-2.2, U-CMOSCRT1-9.7
unnamed: R-CMOSCRT3-17.2, R-CMOSCRT3-18.1
unnamed: R-CMOSCRT3-19.2, U-CMOSCRT3-2.3 (~Reset1)
unnamed: R-CMOSCRT3-20.2, U-CMOSCRT3-2.5 (-TR1)
unnamed: R-CMOSCRT3-26.2, R-CMOSCRT3-27.1
unnamed: R-CMOSCRT3-28.2, U-CMOSCRT3-2.11 (-TR2)
unnamed: R-CMOSCRT3-29.2, U-CMOSCRT3-2.9 (~Q2)
unnamed: U-CMOSCRT1-9.4, U-CMOSCRT3-2.4 (+TR1), U-CMOSCRT3-2.12 (+TR2)
unnamed: U-CMOSCRT1-9.5, U-CMOSCRT1-9.6

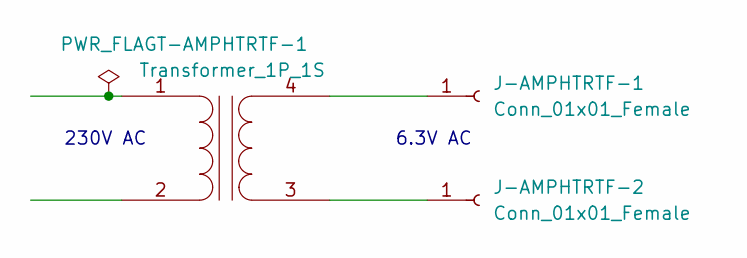
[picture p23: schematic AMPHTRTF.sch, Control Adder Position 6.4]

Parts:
J-AMPHTRTF-1, J-AMPHTRTF-2: Conn_01x01_Female; Banana_Jack_1Pin
T-AMPHTRTF-1: Transformer_1P_1S; FP12950

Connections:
unnamed: J-AMPHTRTF-1.1, T-AMPHTRTF-1.4 (SB)
unnamed: J-AMPHTRTF-2.1, T-AMPHTRTF-1.3 (SA)

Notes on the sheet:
6.3V AC
230V AC

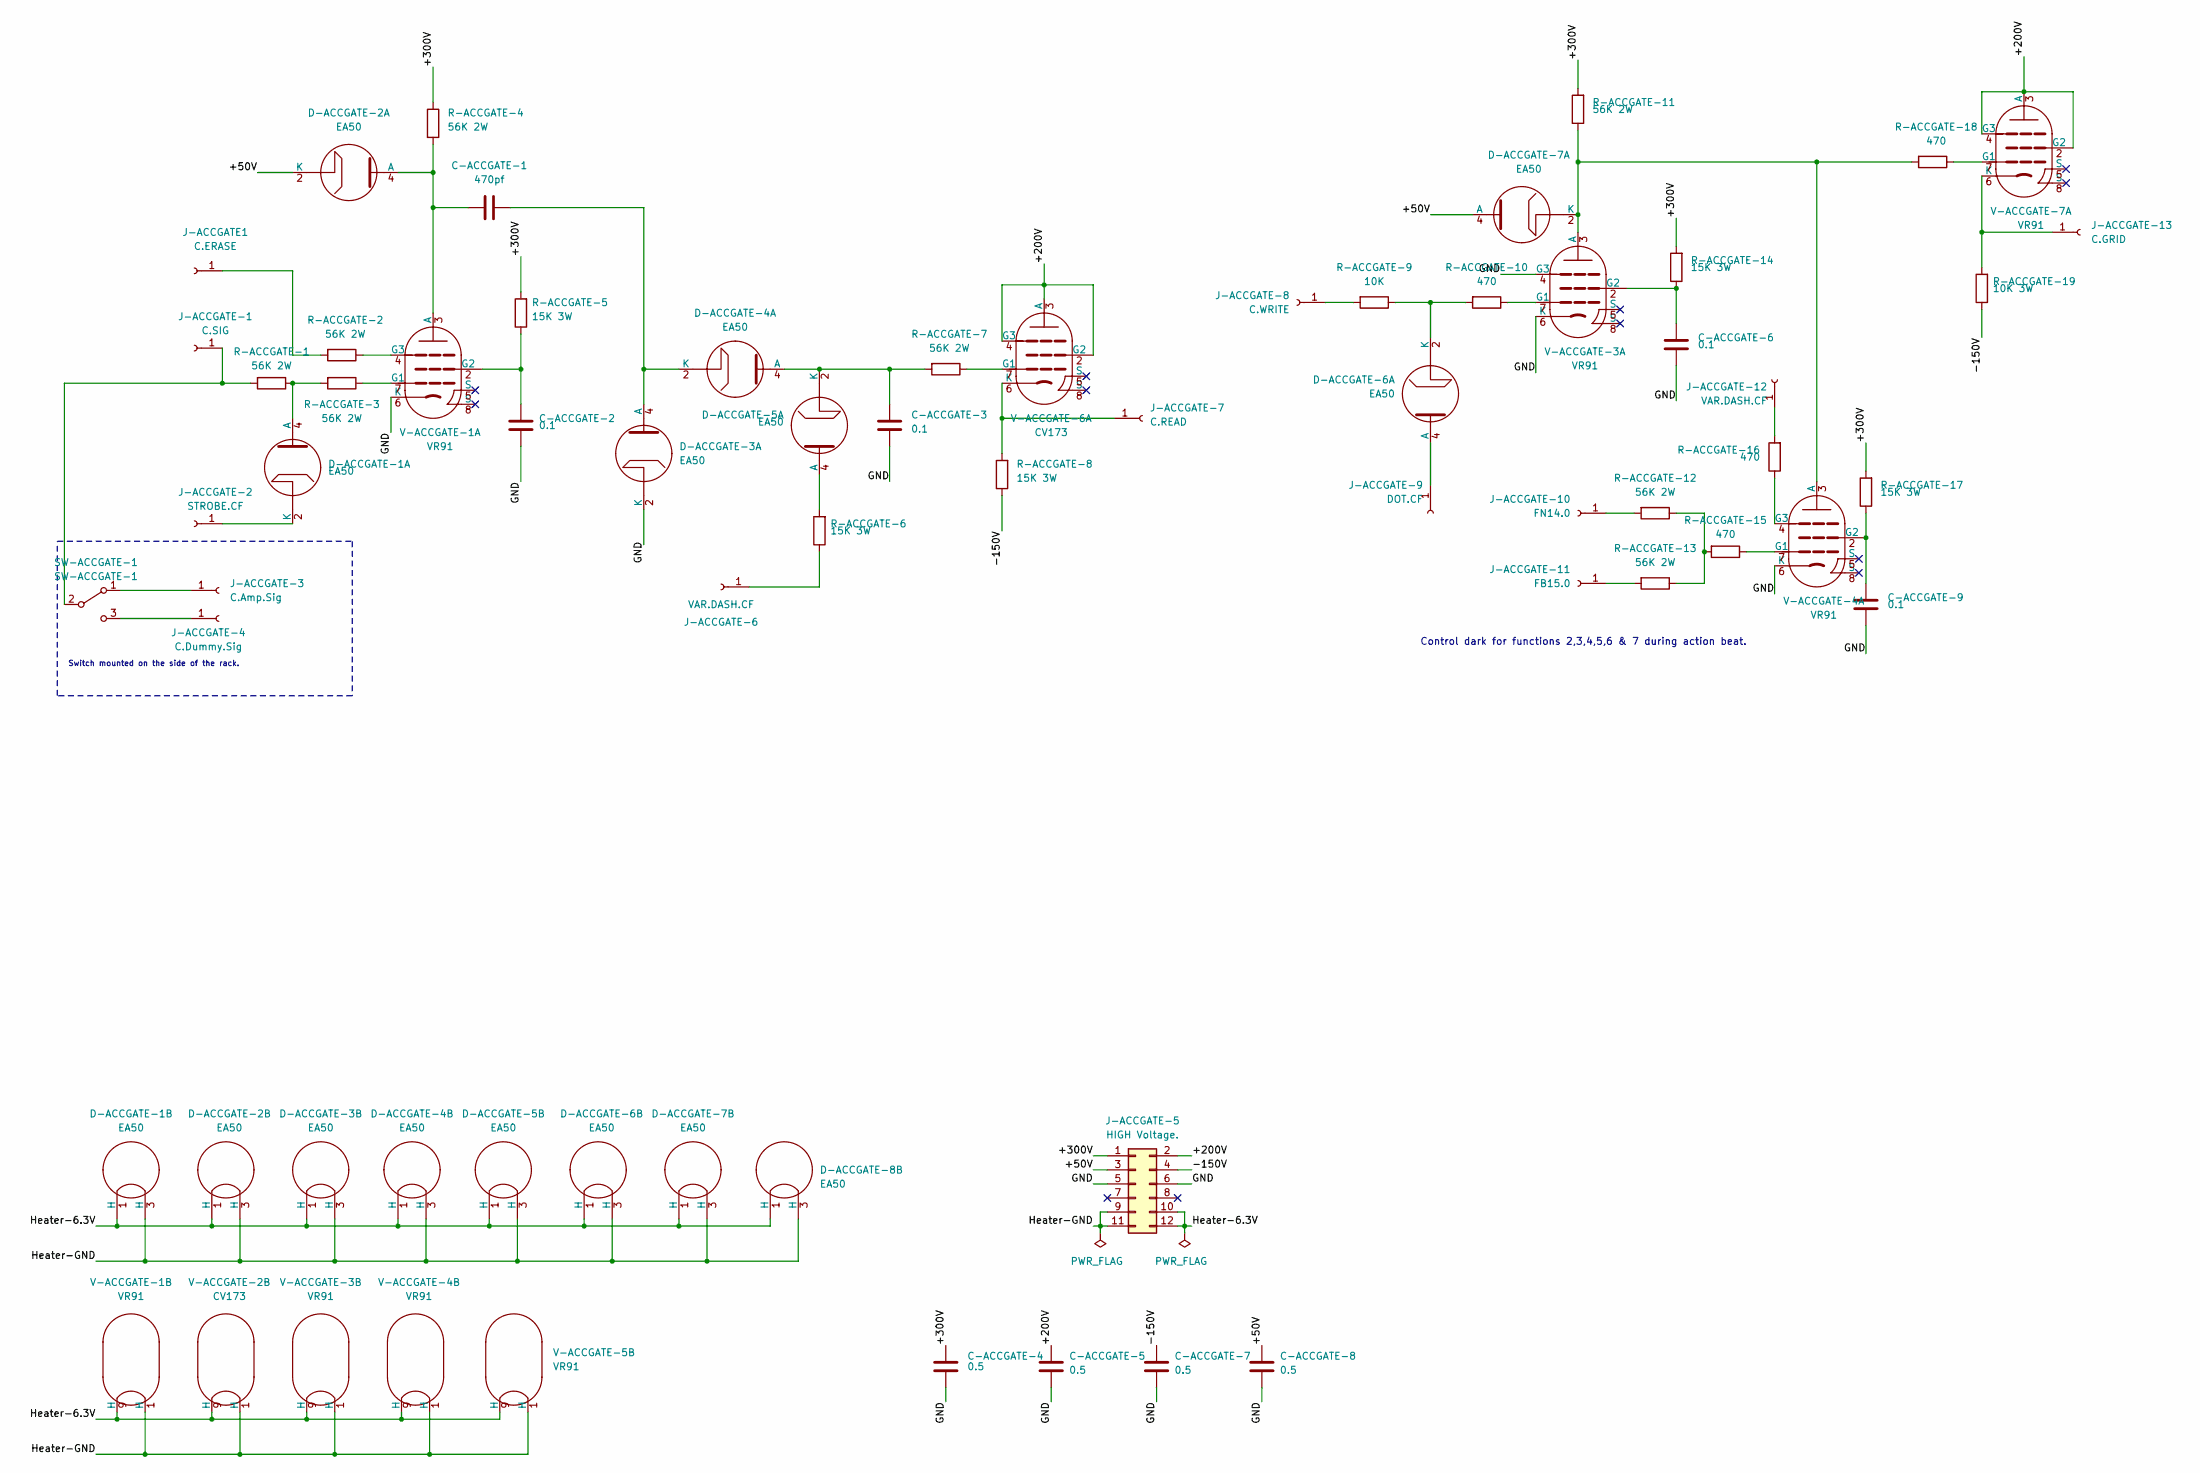
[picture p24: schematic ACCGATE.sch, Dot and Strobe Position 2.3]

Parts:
C-ACCGATE-1: 470pf; C_Disc_D7.5mm_W5.0mm_P5.00mm
C-ACCGATE-2, C-ACCGATE-3, C-ACCGATE-6, C-ACCGATE-9: 0.1; C_Disc_D7.5mm_W5.0mm_P5.00mm
C-ACCGATE-4, C-ACCGATE-5, C-ACCGATE-7, C-ACCGATE-8: 0.5; C_Disc_D7.5mm_W5.0mm_P5.00mm
D-ACCGATE-1, D-ACCGATE-2, D-ACCGATE-3, D-ACCGATE-4, D-ACCGATE-5, D-ACCGATE-6, D-ACCGATE-7, D-ACCGATE-8: EA50; Valve_B3G
J-ACCGATE1: C.ERASE; 242431
J-ACCGATE-1: C.SIG; 242431
J-ACCGATE-2: STROBE.CF; 242431
J-ACCGATE-3: C.Amp.Sig; 242431
J-ACCGATE-4: C.Dummy.Sig; 242431
J-ACCGATE-5: HIGH Voltage.; TE_MATE-N-LOK_1-770972-x_2x06_P4.14mm_Horizontal
J-ACCGATE-6, J-ACCGATE-12: VAR.DASH.CF; 242431
J-ACCGATE-7: C.READ; 242431
J-ACCGATE-8: C.WRITE; 242431
J-ACCGATE-9: DOT.CF; 242431
J-ACCGATE-10: FN14.0; 242431
J-ACCGATE-11: FB15.0; 242431
J-ACCGATE-13: C.GRID; 242431
R-ACCGATE-1, R-ACCGATE-2, R-ACCGATE-3, R-ACCGATE-4, R-ACCGATE-7, R-ACCGATE-11, R-ACCGATE-12, R-ACCGATE-13: 56K 2W; R_Axial_DIN0516_L15.5mm_D5.0mm_P5.08mm_Vertical
R-ACCGATE-5, R-ACCGATE-6, R-ACCGATE-8, R-ACCGATE-14, R-ACCGATE-17: 15K 3W; R_Axial_DIN0516_L15.5mm_D5.0mm_P5.08mm_Vertical
R-ACCGATE-9: 10K; R_Axial_DIN0516_L15.5mm_D5.0mm_P5.08mm_Vertical
R-ACCGATE-10, R-ACCGATE-15, R-ACCGATE-16, R-ACCGATE-18: 470; R_Axial_DIN0516_L15.5mm_D5.0mm_P5.08mm_Vertical
R-ACCGATE-19: 10K 3W; R_Axial_DIN0516_L15.5mm_D5.0mm_P5.08mm_Vertical
SW-ACCGATE-1: SW-ACCGATE-1; M2011SS1W03
V-ACCGATE-1, V-ACCGATE-3, V-ACCGATE-4, V-ACCGATE-5, V-ACCGATE-7: VR91; Valve_9Loctal
V-ACCGATE-2, V-ACCGATE-6: CV173; Valve_9Loctal

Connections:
/ACCGATE/+50V: C-ACCGATE-8.1, D-ACCGATE-2.2 (K), D-ACCGATE-7.4 (A), J-ACCGATE-5.3
/ACCGATE/+200V: C-ACCGATE-5.1, J-ACCGATE-5.2, V-ACCGATE-6.2 (G2), V-ACCGATE-6.3 (A), V-ACCGATE-6.4 (G3), V-ACCGATE-7.2 (G2), V-ACCGATE-7.3 (A), V-ACCGATE-7.4 (G3)
/ACCGATE/+300V: C-ACCGATE-4.1, J-ACCGATE-5.1, R-ACCGATE-4.1, R-ACCGATE-5.2, R-ACCGATE-11.2, R-ACCGATE-14.2, R-ACCGATE-17.2
/ACCGATE/-150V: C-ACCGATE-7.2, J-ACCGATE-5.4, R-ACCGATE-8.1, R-ACCGATE-19.1
/ACCGATE/GND: C-ACCGATE-2.2, C-ACCGATE-3.2, C-ACCGATE-4.2, C-ACCGATE-5.2, C-ACCGATE-6.2, C-ACCGATE-7.1, C-ACCGATE-8.2, C-ACCGATE-9.2, D-ACCGATE-3.2 (K), J-ACCGATE-5.5, J-ACCGATE-5.6, V-ACCGATE-1.6 (K), V-ACCGATE-3.4 (G3), V-ACCGATE-3.6 (K), V-ACCGATE-4.6 (K)
/ACCGATE/Heater-6.3V: D-ACCGATE-1.1 (H), D-ACCGATE-2.1 (H), D-ACCGATE-3.1 (H), D-ACCGATE-4.1 (H), D-ACCGATE-5.1 (H), D-ACCGATE-6.1 (H), D-ACCGATE-7.1 (H), D-ACCGATE-8.1 (H), J-ACCGATE-5.10, J-ACCGATE-5.12, V-ACCGATE-1.9 (H), V-ACCGATE-2.9 (H), V-ACCGATE-3.9 (H), V-ACCGATE-4.9 (H), V-ACCGATE-5.9 (H)
/ACCGATE/Heater-GND: D-ACCGATE-1.3 (H), D-ACCGATE-2.3 (H), D-ACCGATE-3.3 (H), D-ACCGATE-4.3 (H), D-ACCGATE-5.3 (H), D-ACCGATE-6.3 (H), D-ACCGATE-7.3 (H), D-ACCGATE-8.3 (H), J-ACCGATE-5.9, J-ACCGATE-5.11, V-ACCGATE-1.1 (H), V-ACCGATE-2.1 (H), V-ACCGATE-3.1 (H), V-ACCGATE-4.1 (H), V-ACCGATE-5.1 (H)
unnamed: C-ACCGATE-1.1, D-ACCGATE-2.4 (A), R-ACCGATE-4.2, V-ACCGATE-1.3 (A)
unnamed: C-ACCGATE-1.2, D-ACCGATE-3.4 (A), D-ACCGATE-4.2 (K)
unnamed: C-ACCGATE-2.1, R-ACCGATE-5.1, V-ACCGATE-1.2 (G2)
unnamed: C-ACCGATE-3.1, D-ACCGATE-4.4 (A), D-ACCGATE-5.2 (K), R-ACCGATE-7.2
unnamed: C-ACCGATE-6.1, R-ACCGATE-14.1, V-ACCGATE-3.2 (G2)
unnamed: C-ACCGATE-9.1, R-ACCGATE-17.1, V-ACCGATE-4.2 (G2)
unnamed: D-ACCGATE-1.2 (K), J-ACCGATE-2.1
unnamed: D-ACCGATE-1.4 (A), R-ACCGATE-1.1, R-ACCGATE-3.2
unnamed: D-ACCGATE-5.4 (A), R-ACCGATE-6.2
unnamed: D-ACCGATE-6.2 (K), R-ACCGATE-9.1, R-ACCGATE-10.2
unnamed: D-ACCGATE-6.4 (A), J-ACCGATE-9.1
unnamed: D-ACCGATE-7.2 (K), R-ACCGATE-11.1, R-ACCGATE-18.2, V-ACCGATE-3.3 (A), V-ACCGATE-4.3 (A)
unnamed: J-ACCGATE1.1, R-ACCGATE-2.2
unnamed: J-ACCGATE-1.1, R-ACCGATE-1.2, SW-ACCGATE-1.2 (B)
unnamed: J-ACCGATE-3.1, SW-ACCGATE-1.1 (A)
unnamed: J-ACCGATE-4.1, SW-ACCGATE-1.3 (C)
unnamed: J-ACCGATE-6.1, R-ACCGATE-6.1
unnamed: J-ACCGATE-7.1, R-ACCGATE-8.2, V-ACCGATE-6.6 (K)
unnamed: J-ACCGATE-8.1, R-ACCGATE-9.2
unnamed: J-ACCGATE-10.1, R-ACCGATE-12.2
unnamed: J-ACCGATE-11.1, R-ACCGATE-13.2
unnamed: J-ACCGATE-12.1, R-ACCGATE-16.2
unnamed: J-ACCGATE-13.1, R-ACCGATE-19.2, V-ACCGATE-7.6 (K)
unnamed: R-ACCGATE-2.1, V-ACCGATE-1.4 (G3)
unnamed: R-ACCGATE-3.1, V-ACCGATE-1.7 (G1)
unnamed: R-ACCGATE-7.1, V-ACCGATE-6.7 (G1)
unnamed: R-ACCGATE-10.1, V-ACCGATE-3.7 (G1)
unnamed: R-ACCGATE-12.1, R-ACCGATE-13.1, R-ACCGATE-15.2
unnamed: R-ACCGATE-15.1, V-ACCGATE-4.7 (G1)
unnamed: R-ACCGATE-16.1, V-ACCGATE-4.4 (G3)
unnamed: R-ACCGATE-18.1, V-ACCGATE-7.7 (G1)

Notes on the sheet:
Switch mounted on the side of the rack.
Control dark for functions 2,3,4,5,6 & 7 during action beat.

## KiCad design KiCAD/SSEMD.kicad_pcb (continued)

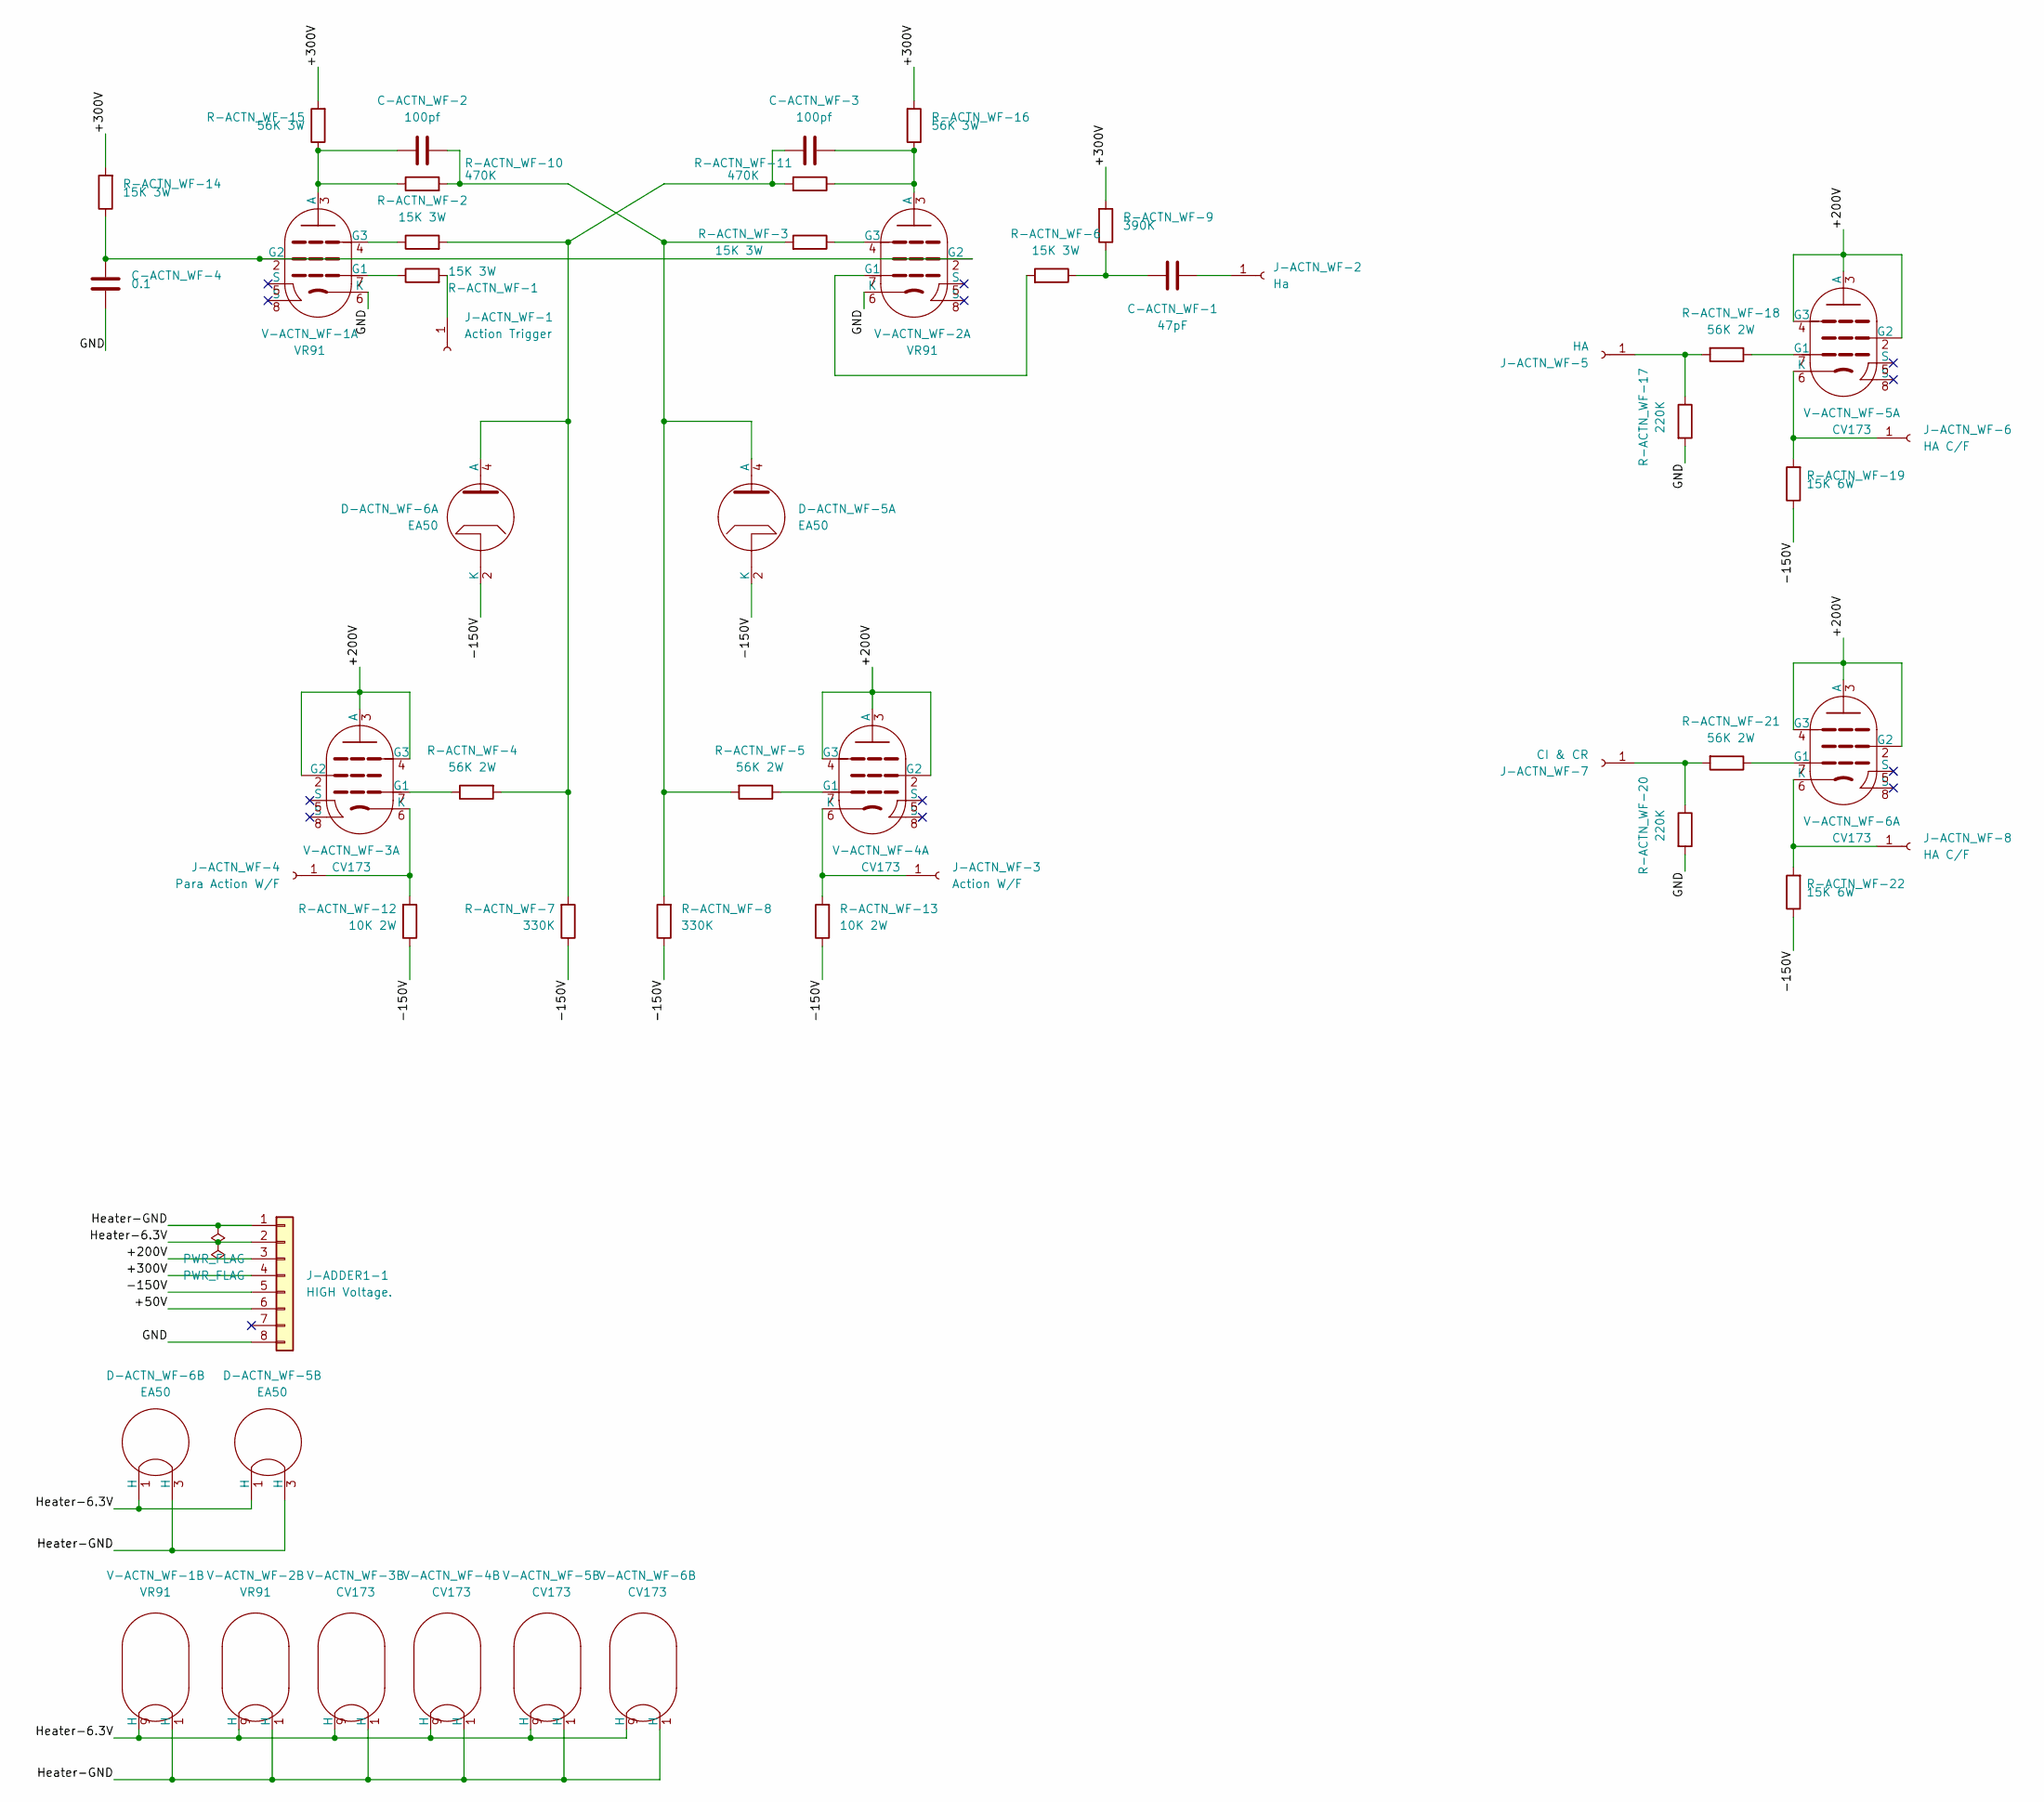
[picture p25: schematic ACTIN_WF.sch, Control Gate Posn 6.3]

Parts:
C-ACTN_WF-1: 47pF; C_Disc_D7.5mm_W5.0mm_P5.00mm
C-ACTN_WF-2, C-ACTN_WF-3: 100pf; C_Disc_D7.5mm_W5.0mm_P5.00mm
C-ACTN_WF-4: 0.1; C_Disc_D7.5mm_W5.0mm_P5.00mm
D-ACTN_WF-5, D-ACTN_WF-6: EA50; Valve_B3G
J-ACTN_WF-1: Action Trigger; 242431
J-ACTN_WF-2: Ha; 242431
J-ACTN_WF-3: Action W/F; 242431
J-ACTN_WF-4: Para Action W/F; 242431
J-ACTN_WF-5: HA; 242431
J-ACTN_WF-6, J-ACTN_WF-8: HA C/F; 242431
J-ACTN_WF-7: CI & CR; 242431
J-ADDER1-1: HIGH Voltage.; TE_MATE-N-LOK_1-770970-x_2x04_P4.14mm_Horizontal
R-ACTN_WF-1, R-ACTN_WF-2, R-ACTN_WF-3, R-ACTN_WF-6, R-ACTN_WF-14: 15K 3W; R_Axial_DIN0516_L15.5mm_D5.0mm_P5.08mm_Vertical
R-ACTN_WF-4, R-ACTN_WF-5, R-ACTN_WF-18, R-ACTN_WF-21: 56K 2W; R_Axial_DIN0516_L15.5mm_D5.0mm_P5.08mm_Vertical
R-ACTN_WF-7, R-ACTN_WF-8: 330K; R_Axial_DIN0516_L15.5mm_D5.0mm_P5.08mm_Vertical
R-ACTN_WF-9: 390K; R_Axial_DIN0516_L15.5mm_D5.0mm_P5.08mm_Vertical
R-ACTN_WF-10, R-ACTN_WF-11: 470K; R_Axial_DIN0516_L15.5mm_D5.0mm_P5.08mm_Vertical
R-ACTN_WF-12, R-ACTN_WF-13: 10K 2W; R_Axial_DIN0516_L15.5mm_D5.0mm_P5.08mm_Vertical
R-ACTN_WF-15, R-ACTN_WF-16: 56K 3W; R_Axial_DIN0516_L15.5mm_D5.0mm_P5.08mm_Vertical
R-ACTN_WF-17, R-ACTN_WF-20: 220K; R_Axial_DIN0516_L15.5mm_D5.0mm_P5.08mm_Vertical
R-ACTN_WF-19, R-ACTN_WF-22: 15K 6W; R_Axial_DIN0516_L15.5mm_D5.0mm_P5.08mm_Vertical
V-ACTN_WF-1, V-ACTN_WF-2: VR91; Valve_9Loctal
V-ACTN_WF-3, V-ACTN_WF-4, V-ACTN_WF-5, V-ACTN_WF-6: CV173; Valve_9Loctal

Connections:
/ACTIN_WF/+200V: J-ADDER1-1.3, V-ACTN_WF-3.2 (G2), V-ACTN_WF-3.3 (A), V-ACTN_WF-3.4 (G3), V-ACTN_WF-4.2 (G2), V-ACTN_WF-4.3 (A), V-ACTN_WF-4.4 (G3), V-ACTN_WF-5.2 (G2), V-ACTN_WF-5.3 (A), V-ACTN_WF-5.4 (G3), V-ACTN_WF-6.2 (G2), V-ACTN_WF-6.3 (A), V-ACTN_WF-6.4 (G3)
/ACTIN_WF/+300V: J-ADDER1-1.4, R-ACTN_WF-9.2, R-ACTN_WF-14.2, R-ACTN_WF-15.2, R-ACTN_WF-16.2
/ACTIN_WF/-150V: D-ACTN_WF-5.2 (K), D-ACTN_WF-6.2 (K), J-ADDER1-1.5, R-ACTN_WF-7.1, R-ACTN_WF-8.1, R-ACTN_WF-12.1, R-ACTN_WF-13.1, R-ACTN_WF-19.1, R-ACTN_WF-22.1
/ACTIN_WF/GND: C-ACTN_WF-4.2, J-ADDER1-1.8, R-ACTN_WF-17.2, R-ACTN_WF-20.2, V-ACTN_WF-1.6 (K), V-ACTN_WF-2.6 (K)
/ACTIN_WF/Heater-6.3V: D-ACTN_WF-5.1 (H), D-ACTN_WF-6.1 (H), J-ADDER1-1.2, V-ACTN_WF-1.9 (H), V-ACTN_WF-2.9 (H), V-ACTN_WF-3.9 (H), V-ACTN_WF-4.9 (F1), V-ACTN_WF-5.9 (H), V-ACTN_WF-6.9 (H)
/ACTIN_WF/Heater-GND: D-ACTN_WF-5.3 (H), D-ACTN_WF-6.3 (H), J-ADDER1-1.1, V-ACTN_WF-1.1 (H), V-ACTN_WF-2.1 (H), V-ACTN_WF-3.1 (H), V-ACTN_WF-4.1 (F1), V-ACTN_WF-5.1 (H), V-ACTN_WF-6.1 (H)
unnamed: C-ACTN_WF-1.1, J-ACTN_WF-2.1
unnamed: C-ACTN_WF-1.2, R-ACTN_WF-6.1, R-ACTN_WF-9.1
unnamed: C-ACTN_WF-2.1, R-ACTN_WF-10.1, R-ACTN_WF-15.1, V-ACTN_WF-1.3 (A)
unnamed: C-ACTN_WF-2.2, D-ACTN_WF-5.4 (A), R-ACTN_WF-3.2, R-ACTN_WF-5.2, R-ACTN_WF-8.2, R-ACTN_WF-10.2
unnamed: C-ACTN_WF-3.1, R-ACTN_WF-11.1, R-ACTN_WF-16.1, V-ACTN_WF-2.3 (A)
unnamed: C-ACTN_WF-3.2, D-ACTN_WF-6.4 (A), R-ACTN_WF-2.2, R-ACTN_WF-4.2, R-ACTN_WF-7.2, R-ACTN_WF-11.2
unnamed: C-ACTN_WF-4.1, R-ACTN_WF-14.1, V-ACTN_WF-1.2 (G2), V-ACTN_WF-2.2 (G2)
unnamed: J-ACTN_WF-1.1, R-ACTN_WF-1.2
unnamed: J-ACTN_WF-3.1, R-ACTN_WF-13.2, V-ACTN_WF-4.6 (K)
unnamed: J-ACTN_WF-4.1, R-ACTN_WF-12.2, V-ACTN_WF-3.6 (K)
unnamed: J-ACTN_WF-5.1, R-ACTN_WF-17.1, R-ACTN_WF-18.2
unnamed: J-ACTN_WF-6.1, R-ACTN_WF-19.2, V-ACTN_WF-5.6 (K)
unnamed: J-ACTN_WF-7.1, R-ACTN_WF-20.1, R-ACTN_WF-21.2
unnamed: J-ACTN_WF-8.1, R-ACTN_WF-22.2, V-ACTN_WF-6.6 (K)
unnamed: R-ACTN_WF-1.1, V-ACTN_WF-1.7 (G1)
unnamed: R-ACTN_WF-2.1, V-ACTN_WF-1.4 (G3)
unnamed: R-ACTN_WF-3.1, V-ACTN_WF-2.4 (G3)
unnamed: R-ACTN_WF-4.1, V-ACTN_WF-3.7 (G1)
unnamed: R-ACTN_WF-5.1, V-ACTN_WF-4.7 (G1)
unnamed: R-ACTN_WF-6.2, V-ACTN_WF-2.7 (G1)
unnamed: R-ACTN_WF-18.1, V-ACTN_WF-5.7 (G1)
unnamed: R-ACTN_WF-21.1, V-ACTN_WF-6.7 (G1)

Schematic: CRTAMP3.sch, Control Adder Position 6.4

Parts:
C-CRTAMP3-1: 18p; C_Disc_D7.5mm_W5.0mm_P5.00mm
C-CRTAMP3-2, C-CRTAMP3-12, C-CRTAMP3-22, C-CRTAMP3-30, C-CRTAMP3-36, C-CRTAMP3-42, C-CRTAMP3-47: 0.5; C_Disc_D7.5mm_W5.0mm_P5.00mm
C-CRTAMP3-3, C-CRTAMP3-13, C-CRTAMP3-23, C-CRTAMP3-37, C-CRTAMP3-43: 2U2; C_Disc_D7.5mm_W5.0mm_P5.00mm
C-CRTAMP3-4, C-CRTAMP3-6, C-CRTAMP3-14, C-CRTAMP3-17, C-CRTAMP3-26, C-CRTAMP3-28, C-CRTAMP3-32, C-CRTAMP3-34, C-CRTAMP3-38, C-CRTAMP3-40, C-CRTAMP3-44, C-CRTAMP3-46, C-CRTAMP3-48, C-CRTAMP3-49: 0.1; C_Disc_D7.5mm_W5.0mm_P5.00mm
C-CRTAMP3-5, C-CRTAMP3-15, C-CRTAMP3-27, C-CRTAMP3-33, C-CRTAMP3-39: 10u; C_Disc_D7.5mm_W5.0mm_P5.00mm
C-CRTAMP3-7, C-CRTAMP3-8, C-CRTAMP3-10, C-CRTAMP3-11, C-CRTAMP3-16, C-CRTAMP3-18, C-CRTAMP3-20, C-CRTAMP3-21, C-CRTAMP3-24, C-CRTAMP3-25: 270pf; C_Disc_D7.5mm_W5.0mm_P5.00mm
C-CRTAMP3-9, C-CRTAMP3-19, C-CRTAMP3-29, C-CRTAMP3-35, C-CRTAMP3-41: 750p; C_Disc_D7.5mm_W5.0mm_P5.00mm
C-CRTAMP3-31: 16U; C_Disc_D7.5mm_W5.0mm_P5.00mm
C-CRTAMP3-45: 0.01; C_Disc_D7.5mm_W5.0mm_P5.00mm
J-CRTAMP3-1: HIGH Voltage.; TE_MATE-N-LOK_1-770970-x_2x04_P4.14mm_Horizontal
J-CRTAMP3-2, J-CRTAMP3-3: PLUS1OR2; 242431
R-CRTAMP3-1, R-CRTAMP3-7, R-CRTAMP3-13, R-CRTAMP3-19, R-CRTAMP3-25, R-CRTAMP3-31, R-CRTAMP3-37, R-CRTAMP3-41: 1M; R_Axial_DIN0516_L15.5mm_D5.0mm_P5.08mm_Vertical
R-CRTAMP3-2, R-CRTAMP3-8, R-CRTAMP3-14, R-CRTAMP3-20, R-CRTAMP3-26, R-CRTAMP3-32: 33; R_Axial_DIN0516_L15.5mm_D5.0mm_P5.08mm_Vertical
R-CRTAMP3-3, R-CRTAMP3-9, R-CRTAMP3-15, R-CRTAMP3-21, R-CRTAMP3-27, R-CRTAMP3-33: 150; R_Axial_DIN0516_L15.5mm_D5.0mm_P5.08mm_Vertical
R-CRTAMP3-4, R-CRTAMP3-10, R-CRTAMP3-16, R-CRTAMP3-22, R-CRTAMP3-28, R-CRTAMP3-34: 10K; R_Axial_DIN0516_L15.5mm_D5.0mm_P5.08mm_Vertical
R-CRTAMP3-5, R-CRTAMP3-11, R-CRTAMP3-17, R-CRTAMP3-23, R-CRTAMP3-29, R-CRTAMP3-35: 1K2; R_Axial_DIN0516_L15.5mm_D5.0mm_P5.08mm_Vertical
R-CRTAMP3-6, R-CRTAMP3-12, R-CRTAMP3-18, R-CRTAMP3-24, R-CRTAMP3-30, R-CRTAMP3-36: 8K2; R_Axial_DIN0516_L15.5mm_D5.0mm_P5.08mm_Vertical
R-CRTAMP3-38: 33K; R_Axial_DIN0516_L15.5mm_D5.0mm_P5.08mm_Vertical
R-CRTAMP3-39: 5K; R_Axial_DIN0516_L15.5mm_D5.0mm_P5.08mm_Vertical
R-CRTAMP3-40: 56K; R_Axial_DIN0516_L15.5mm_D5.0mm_P5.08mm_Vertical
R-CRTAMP3-42: 50K; R_Axial_DIN0516_L15.5mm_D5.0mm_P5.08mm_Vertical
V-CRTAMP3-1, V-CRTAMP3-2, V-CRTAMP3-3, V-CRTAMP3-4, V-CRTAMP3-5, V-CRTAMP3-6: CV173; Valve_9Loctal

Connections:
/CRTAMP3/+300: C-CRTAMP3-2.1, C-CRTAMP3-12.1, C-CRTAMP3-22.1, C-CRTAMP3-30.1, C-CRTAMP3-36.1, C-CRTAMP3-42.1, C-CRTAMP3-44.1, R-CRTAMP3-4.1, R-CRTAMP3-6.1, R-CRTAMP3-10.1, R-CRTAMP3-12.1, R-CRTAMP3-16.1, R-CRTAMP3-18.1, R-CRTAMP3-22.1, R-CRTAMP3-24.1, R-CRTAMP3-28.1, R-CRTAMP3-30.1, R-CRTAMP3-34.1, R-CRTAMP3-36.1, R-CRTAMP3-42.1
/CRTAMP3/-150V: C-CRTAMP3-47.1, J-CRTAMP3-1.5, R-CRTAMP3-40.1
/CRTAMP3/GND: C-CRTAMP3-2.2, C-CRTAMP3-3.2, C-CRTAMP3-5.2, C-CRTAMP3-6.2, C-CRTAMP3-7.1, C-CRTAMP3-8.2, C-CRTAMP3-10.1, C-CRTAMP3-11.2, C-CRTAMP3-12.2, C-CRTAMP3-13.2, C-CRTAMP3-15.2, C-CRTAMP3-16.1, C-CRTAMP3-17.2, C-CRTAMP3-18.2, C-CRTAMP3-20.1, C-CRTAMP3-21.2, C-CRTAMP3-22.2, C-CRTAMP3-23.2, C-CRTAMP3-24.1, C-CRTAMP3-25.2, C-CRTAMP3-27.2, C-CRTAMP3-28.2, C-CRTAMP3-30.2, C-CRTAMP3-31.2, C-CRTAMP3-33.2, C-CRTAMP3-34.2, C-CRTAMP3-36.2, C-CRTAMP3-37.2, C-CRTAMP3-39.2, C-CRTAMP3-40.2, C-CRTAMP3-42.2, C-CRTAMP3-43.2, C-CRTAMP3-44.2, C-CRTAMP3-46.2, C-CRTAMP3-47.2, C-CRTAMP3-49.2, J-CRTAMP3-1.8, R-CRTAMP3-1.1, R-CRTAMP3-3.1, R-CRTAMP3-7.1, R-CRTAMP3-9.1, R-CRTAMP3-13.1, R-CRTAMP3-15.1, R-CRTAMP3-19.1, R-CRTAMP3-21.1, R-CRTAMP3-25.1, R-CRTAMP3-27.1, R-CRTAMP3-31.1, R-CRTAMP3-33.1, R-CRTAMP3-33.2, R-CRTAMP3-42.2, V-CRTAMP3-6.4 (G3), V-CRTAMP3-6.6 (K)
/CRTAMP3/Heater-6.3V: C-CRTAMP3-7.2, C-CRTAMP3-10.2, C-CRTAMP3-16.2, C-CRTAMP3-20.2, J-CRTAMP3-1.2, V-CRTAMP3-1.9 (F1), V-CRTAMP3-2.9 (F1), V-CRTAMP3-3.9 (F1), V-CRTAMP3-4.9 (F1)
/CRTAMP3/Heater-GND: C-CRTAMP3-8.1, C-CRTAMP3-11.1, C-CRTAMP3-18.1, C-CRTAMP3-21.1, C-CRTAMP3-25.1, J-CRTAMP3-1.1, V-CRTAMP3-1.1 (F1), V-CRTAMP3-2.1 (F1), V-CRTAMP3-3.1 (F1), V-CRTAMP3-4.1 (F1), V-CRTAMP3-5.1 (F1), V-CRTAMP3-6.1 (F1)
unnamed: C-CRTAMP3-1.1, C-CRTAMP3-9.1, C-CRTAMP3-19.1, C-CRTAMP3-29.1, C-CRTAMP3-35.1, C-CRTAMP3-41.1, C-CRTAMP3-48.1, R-CRTAMP3-5.2, R-CRTAMP3-11.2, R-CRTAMP3-17.2, R-CRTAMP3-23.2, R-CRTAMP3-29.2, R-CRTAMP3-35.2, R-CRTAMP3-38.1, R-CRTAMP3-39.2, V-CRTAMP3-1.3 (A), V-CRTAMP3-2.3 (A), V-CRTAMP3-3.3 (A), V-CRTAMP3-4.3 (A), V-CRTAMP3-5.3 (A), V-CRTAMP3-6.3 (A)
unnamed: C-CRTAMP3-1.2, J-CRTAMP3-2.1, R-CRTAMP3-1.2, R-CRTAMP3-2.2, R-CRTAMP3-37.1
unnamed: C-CRTAMP3-3.1, R-CRTAMP3-4.2, R-CRTAMP3-5.1
unnamed: C-CRTAMP3-4.1, R-CRTAMP3-6.2, V-CRTAMP3-1.2 (G2)
unnamed: C-CRTAMP3-4.2, C-CRTAMP3-5.1, C-CRTAMP3-6.1, R-CRTAMP3-3.2, V-CRTAMP3-1.4 (G3), V-CRTAMP3-1.6 (K)
unnamed: C-CRTAMP3-9.2, R-CRTAMP3-7.2, R-CRTAMP3-8.2
unnamed: C-CRTAMP3-13.1, R-CRTAMP3-10.2, R-CRTAMP3-11.1
unnamed: C-CRTAMP3-14.1, R-CRTAMP3-12.2, V-CRTAMP3-2.2 (G2)
unnamed: C-CRTAMP3-14.2, C-CRTAMP3-15.1, C-CRTAMP3-17.1, R-CRTAMP3-9.2, V-CRTAMP3-2.4 (G3), V-CRTAMP3-2.6 (K)
unnamed: C-CRTAMP3-19.2, R-CRTAMP3-13.2, R-CRTAMP3-14.2
unnamed: C-CRTAMP3-23.1, R-CRTAMP3-16.2, R-CRTAMP3-17.1
unnamed: C-CRTAMP3-24.2, V-CRTAMP3-5.9 (F1), V-CRTAMP3-6.9 (F1)
unnamed: C-CRTAMP3-26.1, R-CRTAMP3-18.2, V-CRTAMP3-3.2 (G2)
unnamed: C-CRTAMP3-26.2, C-CRTAMP3-27.1, C-CRTAMP3-28.1, R-CRTAMP3-15.2, V-CRTAMP3-3.4 (G3), V-CRTAMP3-3.6 (K)
unnamed: C-CRTAMP3-29.2, R-CRTAMP3-19.2, R-CRTAMP3-20.2
unnamed: C-CRTAMP3-31.1, R-CRTAMP3-22.2, R-CRTAMP3-23.1
unnamed: C-CRTAMP3-32.1, R-CRTAMP3-24.2, R-CRTAMP3-41.2, V-CRTAMP3-4.2 (G2)
unnamed: C-CRTAMP3-32.2, C-CRTAMP3-33.1, C-CRTAMP3-34.1, R-CRTAMP3-21.2, V-CRTAMP3-4.4 (G3), V-CRTAMP3-4.6 (K)
unnamed: C-CRTAMP3-35.2, R-CRTAMP3-25.2, R-CRTAMP3-26.2
unnamed: C-CRTAMP3-37.1, R-CRTAMP3-28.2, R-CRTAMP3-29.1
unnamed: C-CRTAMP3-38.1, R-CRTAMP3-30.2, V-CRTAMP3-5.2 (G2)
unnamed: C-CRTAMP3-38.2, C-CRTAMP3-39.1, C-CRTAMP3-40.1, R-CRTAMP3-27.2, V-CRTAMP3-5.4 (G3), V-CRTAMP3-5.6 (K)
unnamed: C-CRTAMP3-41.2, R-CRTAMP3-31.2, R-CRTAMP3-32.2
unnamed: C-CRTAMP3-43.1, R-CRTAMP3-34.2, R-CRTAMP3-35.1
unnamed: C-CRTAMP3-45.1, R-CRTAMP3-38.2
unnamed: C-CRTAMP3-45.2, J-CRTAMP3-3.1
unnamed: C-CRTAMP3-46.1, R-CRTAMP3-36.2, V-CRTAMP3-6.2 (G2)
unnamed: C-CRTAMP3-48.2, R-CRTAMP3-37.2
unnamed: C-CRTAMP3-49.1, R-CRTAMP3-41.1
unnamed: R-CRTAMP3-2.1, V-CRTAMP3-1.7 (G1)
unnamed: R-CRTAMP3-8.1, V-CRTAMP3-2.7 (G1)
unnamed: R-CRTAMP3-14.1, V-CRTAMP3-3.7 (G1)
unnamed: R-CRTAMP3-20.1, V-CRTAMP3-4.7 (G1)
unnamed: R-CRTAMP3-26.1, V-CRTAMP3-5.7 (G1)
unnamed: R-CRTAMP3-32.1, V-CRTAMP3-6.7 (G1)
unnamed: R-CRTAMP3-39.1, R-CRTAMP3-40.2

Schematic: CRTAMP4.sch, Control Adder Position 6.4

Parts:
C-CRTAMP4-1: 18p; C_Trimmer_Voltronics_JZ
C-CRTAMP4-2, C-CRTAMP4-12, C-CRTAMP4-22, C-CRTAMP4-31, C-CRTAMP4-38, C-CRTAMP4-44, C-CRTAMP4-47: 0.5; C_Disc_D7.5mm_W5.0mm_P5.00mm
C-CRTAMP4-3, C-CRTAMP4-13, C-CRTAMP4-23, C-CRTAMP4-32, C-CRTAMP4-39, C-CRTAMP4-45: 2U2; C_Disc_D7.5mm_W5.0mm_P5.00mm
C-CRTAMP4-4, C-CRTAMP4-6, C-CRTAMP4-14, C-CRTAMP4-17, C-CRTAMP4-26, C-CRTAMP4-28, C-CRTAMP4-29, C-CRTAMP4-33, C-CRTAMP4-35, C-CRTAMP4-36, C-CRTAMP4-40, C-CRTAMP4-42, C-CRTAMP4-46, C-CRTAMP4-48: 0.1; C_Disc_D7.5mm_W5.0mm_P5.00mm
C-CRTAMP4-5, C-CRTAMP4-15, C-CRTAMP4-27, C-CRTAMP4-34, C-CRTAMP4-41: 2u2; C_Disc_D7.5mm_W5.0mm_P5.00mm
C-CRTAMP4-7, C-CRTAMP4-8, C-CRTAMP4-10, C-CRTAMP4-11, C-CRTAMP4-16, C-CRTAMP4-18, C-CRTAMP4-20, C-CRTAMP4-21, C-CRTAMP4-24, C-CRTAMP4-25: 270pf; C_Disc_D7.5mm_W5.0mm_P5.00mm
C-CRTAMP4-9, C-CRTAMP4-19, C-CRTAMP4-30, C-CRTAMP4-37, C-CRTAMP4-43: 750p; C_Disc_D7.5mm_W5.0mm_P5.00mm
C-CRTAMP4-49: 0.01; C_Disc_D7.5mm_W5.0mm_P5.00mm
C-CRTAMP4-50: 8u; C_Disc_D7.5mm_W5.0mm_P5.00mm
J-CRTAMP4-1, J-CRTAMP4-3: PLUS1OR2; 242431
J-CRTAMP4-2: HIGH Voltage.; TE_MATE-N-LOK_1-770970-x_2x04_P4.14mm_Horizontal
R-CRTAMP4-1, R-CRTAMP4-7, R-CRTAMP4-12, R-CRTAMP4-14, R-CRTAMP4-20, R-CRTAMP4-26, R-CRTAMP4-28, R-CRTAMP4-34: 1M; R_Axial_DIN0516_L15.5mm_D5.0mm_P5.08mm_Vertical
R-CRTAMP4-2, R-CRTAMP4-8, R-CRTAMP4-15, R-CRTAMP4-21, R-CRTAMP4-29, R-CRTAMP4-35: 33; R_Axial_DIN0516_L15.5mm_D5.0mm_P5.08mm_Vertical
R-CRTAMP4-3, R-CRTAMP4-9, R-CRTAMP4-16, R-CRTAMP4-22, R-CRTAMP4-30, R-CRTAMP4-36: 150; R_Axial_DIN0516_L15.5mm_D5.0mm_P5.08mm_Vertical
R-CRTAMP4-4, R-CRTAMP4-10, R-CRTAMP4-17, R-CRTAMP4-23, R-CRTAMP4-31, R-CRTAMP4-37: 10K; R_Axial_DIN0516_L15.5mm_D5.0mm_P5.08mm_Vertical
R-CRTAMP4-5, R-CRTAMP4-11, R-CRTAMP4-18, R-CRTAMP4-24, R-CRTAMP4-32, R-CRTAMP4-38: 1K2; R_Axial_DIN0516_L15.5mm_D5.0mm_P5.08mm_Vertical
R-CRTAMP4-6, R-CRTAMP4-13, R-CRTAMP4-19, R-CRTAMP4-25, R-CRTAMP4-33, R-CRTAMP4-39: 8K2; R_Axial_DIN0516_L15.5mm_D5.0mm_P5.08mm_Vertical
R-CRTAMP4-27: 50K; R_Axial_DIN0516_L15.5mm_D5.0mm_P5.08mm_Vertical
R-CRTAMP4-40: 33K; R_Axial_DIN0516_L15.5mm_D5.0mm_P5.08mm_Vertical
R-CRTAMP4-41: 5K; R_Axial_DIN0516_L15.5mm_D5.0mm_P5.08mm_Vertical
R-CRTAMP4-42: 56K; R_Axial_DIN0516_L15.5mm_D5.0mm_P5.08mm_Vertical
V-CRTAMP4-1, V-CRTAMP4-2, V-CRTAMP4-3, V-CRTAMP4-4, V-CRTAMP4-5, V-CRTAMP4-6: CV173; Valve_9Loctal

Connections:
/CRTAMP4/+300: C-CRTAMP4-2.1, C-CRTAMP4-12.1, C-CRTAMP4-22.1, C-CRTAMP4-31.1, C-CRTAMP4-38.1, C-CRTAMP4-44.1, C-CRTAMP4-48.1, R-CRTAMP4-4.1, R-CRTAMP4-6.1, R-CRTAMP4-10.1, R-CRTAMP4-13.1, R-CRTAMP4-17.1, R-CRTAMP4-19.1, R-CRTAMP4-23.1, R-CRTAMP4-25.1, R-CRTAMP4-27.1, R-CRTAMP4-31.1, R-CRTAMP4-33.1, R-CRTAMP4-37.1, R-CRTAMP4-39.1
/CRTAMP4/-150V: C-CRTAMP4-47.1, J-CRTAMP4-2.5, R-CRTAMP4-42.1
/CRTAMP4/GND: C-CRTAMP4-2.2, C-CRTAMP4-3.2, C-CRTAMP4-5.2, C-CRTAMP4-6.2, C-CRTAMP4-7.1, C-CRTAMP4-8.2, C-CRTAMP4-10.1, C-CRTAMP4-11.2, C-CRTAMP4-12.2, C-CRTAMP4-13.2, C-CRTAMP4-15.2, C-CRTAMP4-16.1, C-CRTAMP4-17.2, C-CRTAMP4-18.2, C-CRTAMP4-20.1, C-CRTAMP4-21.2, C-CRTAMP4-22.2, C-CRTAMP4-23.2, C-CRTAMP4-24.1, C-CRTAMP4-25.2, C-CRTAMP4-27.2, C-CRTAMP4-28.2, C-CRTAMP4-31.2, C-CRTAMP4-32.2, C-CRTAMP4-34.2, C-CRTAMP4-35.2, C-CRTAMP4-36.2, C-CRTAMP4-38.2, C-CRTAMP4-39.2, C-CRTAMP4-41.2, C-CRTAMP4-42.2, C-CRTAMP4-44.2, C-CRTAMP4-45.2, C-CRTAMP4-46.2, C-CRTAMP4-47.2, C-CRTAMP4-48.2, C-CRTAMP4-50.2, J-CRTAMP4-2.8, R-CRTAMP4-1.1, R-CRTAMP4-3.1, R-CRTAMP4-7.1, R-CRTAMP4-9.1, R-CRTAMP4-14.1, R-CRTAMP4-16.1, R-CRTAMP4-20.1, R-CRTAMP4-22.1, R-CRTAMP4-27.2, R-CRTAMP4-28.1, R-CRTAMP4-30.1, R-CRTAMP4-34.1, R-CRTAMP4-36.1, R-CRTAMP4-36.2, V-CRTAMP4-6.4 (G3), V-CRTAMP4-6.6 (K)
/CRTAMP4/Heater-6.3V: C-CRTAMP4-7.2, C-CRTAMP4-10.2, C-CRTAMP4-16.2, C-CRTAMP4-20.2, J-CRTAMP4-2.2, V-CRTAMP4-1.9 (F1), V-CRTAMP4-2.9 (F1), V-CRTAMP4-3.9 (F1), V-CRTAMP4-4.9 (F1)
/CRTAMP4/Heater-GND: C-CRTAMP4-8.1, C-CRTAMP4-11.1, C-CRTAMP4-18.1, C-CRTAMP4-21.1, C-CRTAMP4-25.1, J-CRTAMP4-2.1, V-CRTAMP4-1.1 (F1), V-CRTAMP4-2.1 (F1), V-CRTAMP4-3.1 (F1), V-CRTAMP4-4.1 (F1), V-CRTAMP4-5.1 (F1), V-CRTAMP4-6.1 (F1)
unnamed: C-CRTAMP4-1.1, C-CRTAMP4-9.1, C-CRTAMP4-19.1, C-CRTAMP4-29.1, C-CRTAMP4-30.1, C-CRTAMP4-37.1, C-CRTAMP4-43.1, R-CRTAMP4-5.2, R-CRTAMP4-11.2, R-CRTAMP4-18.2, R-CRTAMP4-24.2, R-CRTAMP4-32.2, R-CRTAMP4-38.2, R-CRTAMP4-40.1, R-CRTAMP4-41.2, V-CRTAMP4-1.3 (A), V-CRTAMP4-2.3 (A), V-CRTAMP4-3.3 (A), V-CRTAMP4-4.3 (A), V-CRTAMP4-5.3 (A), V-CRTAMP4-6.3 (A)
unnamed: C-CRTAMP4-1.2, J-CRTAMP4-1.1, R-CRTAMP4-1.2, R-CRTAMP4-2.2, R-CRTAMP4-12.1
unnamed: C-CRTAMP4-3.1, R-CRTAMP4-4.2, R-CRTAMP4-5.1
unnamed: C-CRTAMP4-4.1, R-CRTAMP4-6.2, V-CRTAMP4-1.2 (G2)
unnamed: C-CRTAMP4-4.2, C-CRTAMP4-5.1, C-CRTAMP4-6.1, R-CRTAMP4-3.2, V-CRTAMP4-1.4 (G3), V-CRTAMP4-1.6 (K)
unnamed: C-CRTAMP4-9.2, R-CRTAMP4-7.2, R-CRTAMP4-8.2
unnamed: C-CRTAMP4-13.1, R-CRTAMP4-10.2, R-CRTAMP4-11.1
unnamed: C-CRTAMP4-14.1, R-CRTAMP4-13.2, V-CRTAMP4-2.2 (G2)
unnamed: C-CRTAMP4-14.2, C-CRTAMP4-15.1, C-CRTAMP4-17.1, R-CRTAMP4-9.2, V-CRTAMP4-2.4 (G3), V-CRTAMP4-2.6 (K)
unnamed: C-CRTAMP4-19.2, R-CRTAMP4-14.2, R-CRTAMP4-15.2
unnamed: C-CRTAMP4-23.1, R-CRTAMP4-17.2, R-CRTAMP4-18.1
unnamed: C-CRTAMP4-24.2, V-CRTAMP4-5.9 (F1), V-CRTAMP4-6.9 (F1)
unnamed: C-CRTAMP4-26.1, R-CRTAMP4-19.2, V-CRTAMP4-3.2 (G2)
unnamed: C-CRTAMP4-26.2, C-CRTAMP4-27.1, C-CRTAMP4-28.1, R-CRTAMP4-16.2, V-CRTAMP4-3.4 (G3), V-CRTAMP4-3.6 (K)
unnamed: C-CRTAMP4-29.2, R-CRTAMP4-12.2
unnamed: C-CRTAMP4-30.2, R-CRTAMP4-20.2, R-CRTAMP4-21.2
unnamed: C-CRTAMP4-32.1, C-CRTAMP4-50.1, R-CRTAMP4-23.2, R-CRTAMP4-24.1
unnamed: C-CRTAMP4-33.1, R-CRTAMP4-25.2, R-CRTAMP4-26.2, V-CRTAMP4-4.2 (G2)
unnamed: C-CRTAMP4-33.2, C-CRTAMP4-34.1, C-CRTAMP4-35.1, R-CRTAMP4-22.2, V-CRTAMP4-4.4 (G3), V-CRTAMP4-4.6 (K)
unnamed: C-CRTAMP4-36.1, R-CRTAMP4-26.1
unnamed: C-CRTAMP4-37.2, R-CRTAMP4-28.2, R-CRTAMP4-29.2
unnamed: C-CRTAMP4-39.1, R-CRTAMP4-31.2, R-CRTAMP4-32.1
unnamed: C-CRTAMP4-40.1, R-CRTAMP4-33.2, V-CRTAMP4-5.2 (G2)
unnamed: C-CRTAMP4-40.2, C-CRTAMP4-41.1, C-CRTAMP4-42.1, R-CRTAMP4-30.2, V-CRTAMP4-5.4 (G3), V-CRTAMP4-5.6 (K)
unnamed: C-CRTAMP4-43.2, R-CRTAMP4-34.2, R-CRTAMP4-35.2
unnamed: C-CRTAMP4-45.1, R-CRTAMP4-37.2, R-CRTAMP4-38.1
unnamed: C-CRTAMP4-46.1, R-CRTAMP4-39.2, V-CRTAMP4-6.2 (G2)
unnamed: C-CRTAMP4-49.1, R-CRTAMP4-40.2
unnamed: C-CRTAMP4-49.2, J-CRTAMP4-3.1
unnamed: R-CRTAMP4-2.1, V-CRTAMP4-1.7 (G1)
unnamed: R-CRTAMP4-8.1, V-CRTAMP4-2.7 (G1)
unnamed: R-CRTAMP4-15.1, V-CRTAMP4-3.7 (G1)
unnamed: R-CRTAMP4-21.1, V-CRTAMP4-4.7 (G1)
unnamed: R-CRTAMP4-29.1, V-CRTAMP4-5.7 (G1)
unnamed: R-CRTAMP4-35.1, V-CRTAMP4-6.7 (G1)
unnamed: R-CRTAMP4-41.1, R-CRTAMP4-42.2

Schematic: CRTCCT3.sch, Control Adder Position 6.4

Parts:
C-CRTCCT3-1: 0.25 4kV; C_Disc_D7.5mm_W5.0mm_P5.00mm
C-CRTCCT3-2, C-CRTCCT3-3, C-CRTCCT3-4: 0.1; C_Disc_D7.5mm_W5.0mm_P5.00mm
C-CRTCCT3-5: 0.5 350V; C_Disc_D7.5mm_W5.0mm_P5.00mm
C-CRTCCT3-6: 0.01 4kV; C_Disc_D7.5mm_W5.0mm_P5.00mm
C-CRTCCT3-7: 0.03 4kv; C_Disc_D7.5mm_W5.0mm_P5.00mm
D-CRTCCT3-1: VR78; Valve_B3G
J-CRTCCT3-1: Y2; 242431
J-CRTCCT3-2: X2; 242431
J-CRTCCT3-3: Y1; 242431
J-CRTCCT3-4: X1; 242431
J-CRTCCT3-5, J-CRTCCT3-8: S.PLATE; 242431
J-CRTCCT3-6: HIGH Voltage.; TE_MATE-N-LOK_1-770970-x_2x04_P4.14mm_Horizontal
J-CRTCCT3-7: +300; 242431
R-CRTCCT3-1, R-CRTCCT3-2, R-CRTCCT3-3: 680K; R_Axial_DIN0516_L15.5mm_D5.0mm_P5.08mm_Vertical
R-CRTCCT3-4: 470K; R_Axial_DIN0516_L15.5mm_D5.0mm_P5.08mm_Vertical
R-CRTCCT3-5: 270K; R_Axial_DIN0516_L15.5mm_D5.0mm_P5.08mm_Vertical
R-CRTCCT3-6: 2M2; R_Axial_DIN0516_L15.5mm_D5.0mm_P5.08mm_Vertical
R-CRTCCT3-7: 22K; R_Axial_DIN0516_L15.5mm_D5.0mm_P5.08mm_Vertical
RV-CRTCCT3-1: 500K; Potentiometer_Bourns_3339P_Vertical_HandSoldering
RV-CRTCCT3-2, RV-CRTCCT3-3: 100K; Potentiometer_Bourns_3339P_Vertical_HandSoldering
V-CRTCCT3-1: VCR97; B12D

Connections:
/CRTCCT3/GND: C-CRTCCT3-1.2, C-CRTCCT3-2.1, C-CRTCCT3-3.1, C-CRTCCT3-6.2, J-CRTCCT3-5.2 (Ext), J-CRTCCT3-6.8, J-CRTCCT3-7.2 (Ext), J-CRTCCT3-8.2 (Ext), R-CRTCCT3-1.2, RV-CRTCCT3-2.1
/CRTCCT3/Heater-6.3V: C-CRTCCT3-4.2, C-CRTCCT3-5.1, D-CRTCCT3-1.1 (J), J-CRTCCT3-6.2, RV-CRTCCT3-3.2, V-CRTCCT3-1.2 (K), V-CRTCCT3-1.3 (h)
/CRTCCT3/Heater-GND: C-CRTCCT3-4.1, D-CRTCCT3-1.3 (J), J-CRTCCT3-6.1, V-CRTCCT3-1.4 (h)
/CRTCCT3/S.EHT(800-1400V): C-CRTCCT3-5.2, C-CRTCCT3-6.1, D-CRTCCT3-1.2 (K), R-CRTCCT3-6.1, R-CRTCCT3-7.1
unnamed: C-CRTCCT3-1.1, R-CRTCCT3-4.1, V-CRTCCT3-1.6 (A2)
unnamed: C-CRTCCT3-2.2, RV-CRTCCT3-2.2, V-CRTCCT3-1.5 (A1), V-CRTCCT3-1.7 (CC), V-CRTCCT3-1.10 (A3)
unnamed: C-CRTCCT3-3.2, J-CRTCCT3-7.1 (In), RV-CRTCCT3-2.3
unnamed: C-CRTCCT3-7.1, J-CRTCCT3-8.1 (In)
unnamed: C-CRTCCT3-7.2, D-CRTCCT3-1.4 (A), R-CRTCCT3-6.2, V-CRTCCT3-1.1 (G1)
unnamed: J-CRTCCT3-1.1, V-CRTCCT3-1.8 (y2)
unnamed: J-CRTCCT3-2.1, V-CRTCCT3-1.9 (x2)
unnamed: J-CRTCCT3-3.1, V-CRTCCT3-1.12 (y1)
unnamed: J-CRTCCT3-4.1, V-CRTCCT3-1.11 (x1)
unnamed: R-CRTCCT3-1.1, R-CRTCCT3-2.2
unnamed: R-CRTCCT3-2.1, R-CRTCCT3-3.2
unnamed: R-CRTCCT3-3.1, RV-CRTCCT3-1.1
unnamed: R-CRTCCT3-4.2, RV-CRTCCT3-1.2
unnamed: R-CRTCCT3-5.1, RV-CRTCCT3-3.1
unnamed: R-CRTCCT3-5.2, RV-CRTCCT3-1.3
unnamed: R-CRTCCT3-7.2, RV-CRTCCT3-3.3

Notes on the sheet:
ASTIG
FOCUS
BRILL

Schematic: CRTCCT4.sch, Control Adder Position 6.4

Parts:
C-CRTCCT4-1: 0.25 4kV; C_Disc_D7.5mm_W5.0mm_P5.00mm
C-CRTCCT4-2, C-CRTCCT4-3, C-CRTCCT4-4: 0.1; C_Disc_D7.5mm_W5.0mm_P5.00mm
C-CRTCCT4-5: 0.5 350V; C_Disc_D7.5mm_W5.0mm_P5.00mm
C-CRTCCT4-6: 0.01 4kV; C_Disc_D7.5mm_W5.0mm_P5.00mm
C-CRTCCT4-7: 0.03 4kv; C_Disc_D7.5mm_W5.0mm_P5.00mm
D-CRTCCT4-1: VR78; Valve_B3G
J-CRTCCT4-1: C.PLATE; 242431
J-CRTCCT4-2: C.Y2; 242431
J-CRTCCT4-3: C.Y1; 242431
J-CRTCCT4-4: C.X2; 242431
J-CRTCCT4-5: C.X1; 242431
J-CRTCCT4-6: +300; 242431
J-CRTCCT4-7: C.GRID; 242431
J-CRTCCT4-15: HIGH Voltage.; TE_MATE-N-LOK_1-770970-x_2x04_P4.14mm_Horizontal
R-CRTCCT4-1, R-CRTCCT4-2, R-CRTCCT4-3: 680K; R_Axial_DIN0516_L15.5mm_D5.0mm_P5.08mm_Vertical
R-CRTCCT4-4: 470K; R_Axial_DIN0516_L15.5mm_D5.0mm_P5.08mm_Vertical
R-CRTCCT4-5: 270K; R_Axial_DIN0516_L15.5mm_D5.0mm_P5.08mm_Vertical
R-CRTCCT4-6: 2M2; R_Axial_DIN0516_L15.5mm_D5.0mm_P5.08mm_Vertical
R-CRTCCT4-7: 22K; R_Axial_DIN0516_L15.5mm_D5.0mm_P5.08mm_Vertical
RV-CRTCCT4-1: 500K; Potentiometer_Bourns_3339P_Vertical_HandSoldering
RV-CRTCCT4-2, RV-CRTCCT4-3: 100K; Potentiometer_Bourns_3339P_Vertical_HandSoldering
V-CRTCCT4-1: VCR97; B12D

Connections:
/CRTCCT4/GND: C-CRTCCT4-1.2, C-CRTCCT4-2.1, C-CRTCCT4-3.1, C-CRTCCT4-6.2, J-CRTCCT4-1.2 (Ext), J-CRTCCT4-6.2 (Ext), J-CRTCCT4-7.2 (Ext), J-CRTCCT4-15.8, R-CRTCCT4-1.2, RV-CRTCCT4-2.1
/CRTCCT4/Heater-6.3V: C-CRTCCT4-4.2, C-CRTCCT4-5.1, D-CRTCCT4-1.1 (J), J-CRTCCT4-15.2, RV-CRTCCT4-3.2, V-CRTCCT4-1.2 (K), V-CRTCCT4-1.3 (h)
/CRTCCT4/Heater-GND: C-CRTCCT4-4.1, D-CRTCCT4-1.3 (J), J-CRTCCT4-15.1, V-CRTCCT4-1.4 (h)
/CRTCCT4/S.EHT(800-1400V): C-CRTCCT4-5.2, C-CRTCCT4-6.1, D-CRTCCT4-1.2 (K), R-CRTCCT4-6.1, R-CRTCCT4-7.1
unnamed: C-CRTCCT4-1.1, R-CRTCCT4-4.1, V-CRTCCT4-1.6 (A2)
unnamed: C-CRTCCT4-2.2, RV-CRTCCT4-2.2, V-CRTCCT4-1.5 (A1), V-CRTCCT4-1.7 (CC), V-CRTCCT4-1.10 (A3)
unnamed: C-CRTCCT4-3.2, J-CRTCCT4-6.1 (In), RV-CRTCCT4-2.3
unnamed: C-CRTCCT4-7.1, J-CRTCCT4-7.1 (In)
unnamed: C-CRTCCT4-7.2, D-CRTCCT4-1.4 (A), R-CRTCCT4-6.2, V-CRTCCT4-1.1 (G1)
unnamed: J-CRTCCT4-2.1, V-CRTCCT4-1.8 (y2)
unnamed: J-CRTCCT4-3.1, V-CRTCCT4-1.12 (y1)
unnamed: J-CRTCCT4-4.1, V-CRTCCT4-1.9 (x2)
unnamed: J-CRTCCT4-5.1, V-CRTCCT4-1.11 (x1)
unnamed: R-CRTCCT4-1.1, R-CRTCCT4-2.2
unnamed: R-CRTCCT4-2.1, R-CRTCCT4-3.2
unnamed: R-CRTCCT4-3.1, RV-CRTCCT4-1.1
unnamed: R-CRTCCT4-4.2, RV-CRTCCT4-1.2
unnamed: R-CRTCCT4-5.1, RV-CRTCCT4-3.1
unnamed: R-CRTCCT4-5.2, RV-CRTCCT4-1.3
unnamed: R-CRTCCT4-7.2, RV-CRTCCT4-3.3

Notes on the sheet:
ASTIG
FOCUS
BRILL

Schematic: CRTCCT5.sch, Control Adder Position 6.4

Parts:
C-CRTCCT5-1: 0.25 4kV; C_Disc_D7.5mm_W5.0mm_P5.00mm
C-CRTCCT5-2, C-CRTCCT5-3, C-CRTCCT5-4: 0.1; C_Disc_D7.5mm_W5.0mm_P5.00mm
C-CRTCCT5-5: 0.5 350V; C_Disc_D7.5mm_W5.0mm_P5.00mm
C-CRTCCT5-6: 0.01 4kV; C_Disc_D7.5mm_W5.0mm_P5.00mm
C-CRTCCT5-7: 0.03 4kv; C_Disc_D7.5mm_W5.0mm_P5.00mm
D-CRTCCT5-1: VR78; Valve_B3G
J-CRTCCT5-1: A.PLATE; 242431
J-CRTCCT5-2: A.Y2; 242431
J-CRTCCT5-3: A.Y1; 242431
J-CRTCCT5-4: A.X2; 242431
J-CRTCCT5-5: A.X1; 242431
J-CRTCCT5-6: +300; 242431
J-CRTCCT5-7: A.GRID; 242431
J-CRTCCT5-16: HIGH Voltage.; TE_MATE-N-LOK_1-770970-x_2x04_P4.14mm_Horizontal
R-CRTCCT5-1, R-CRTCCT5-2, R-CRTCCT5-3: 680K; R_Axial_DIN0516_L15.5mm_D5.0mm_P5.08mm_Vertical
R-CRTCCT5-4: 470K; R_Axial_DIN0516_L15.5mm_D5.0mm_P5.08mm_Vertical
R-CRTCCT5-5: 270K; R_Axial_DIN0516_L15.5mm_D5.0mm_P5.08mm_Vertical
R-CRTCCT5-6: 2M2; R_Axial_DIN0516_L15.5mm_D5.0mm_P5.08mm_Vertical
R-CRTCCT5-7: 22K; R_Axial_DIN0516_L15.5mm_D5.0mm_P5.08mm_Vertical
RV-CRTCCT5-1: 500K; Potentiometer_Bourns_3339P_Vertical_HandSoldering
RV-CRTCCT5-2, RV-CRTCCT5-3: 100K; Potentiometer_Bourns_3339P_Vertical_HandSoldering
V-CRTCCT5-1: VCR97; B12D

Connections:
/CRTCCT5/GND: C-CRTCCT5-1.2, C-CRTCCT5-2.1, C-CRTCCT5-3.1, C-CRTCCT5-6.2, J-CRTCCT5-1.2 (Ext), J-CRTCCT5-6.2 (Ext), J-CRTCCT5-7.2 (Ext), J-CRTCCT5-16.8, R-CRTCCT5-1.2, RV-CRTCCT5-2.1
/CRTCCT5/Heater-6.3V: C-CRTCCT5-4.2, C-CRTCCT5-5.1, D-CRTCCT5-1.1 (J), J-CRTCCT5-16.2, RV-CRTCCT5-3.2, V-CRTCCT5-1.2 (K), V-CRTCCT5-1.3 (h)
/CRTCCT5/Heater-GND: C-CRTCCT5-4.1, D-CRTCCT5-1.3 (J), J-CRTCCT5-16.1, V-CRTCCT5-1.4 (h)
/CRTCCT5/S.EHT(800-1400V): C-CRTCCT5-5.2, C-CRTCCT5-6.1, D-CRTCCT5-1.2 (K), R-CRTCCT5-6.1, R-CRTCCT5-7.1
unnamed: C-CRTCCT5-1.1, R-CRTCCT5-4.1, V-CRTCCT5-1.6 (A2)
unnamed: C-CRTCCT5-2.2, RV-CRTCCT5-2.2, V-CRTCCT5-1.5 (A1), V-CRTCCT5-1.7 (CC), V-CRTCCT5-1.10 (A3)
unnamed: C-CRTCCT5-3.2, J-CRTCCT5-6.1 (In), RV-CRTCCT5-2.3
unnamed: C-CRTCCT5-7.1, J-CRTCCT5-7.1 (In)
unnamed: C-CRTCCT5-7.2, D-CRTCCT5-1.4 (A), R-CRTCCT5-6.2, V-CRTCCT5-1.1 (G1)
unnamed: J-CRTCCT5-2.1, V-CRTCCT5-1.8 (y2)
unnamed: J-CRTCCT5-3.1, V-CRTCCT5-1.12 (y1)
unnamed: J-CRTCCT5-4.1, V-CRTCCT5-1.9 (x2)
unnamed: J-CRTCCT5-5.1, V-CRTCCT5-1.11 (x1)
unnamed: R-CRTCCT5-1.1, R-CRTCCT5-2.2
unnamed: R-CRTCCT5-2.1, R-CRTCCT5-3.2
unnamed: R-CRTCCT5-3.1, RV-CRTCCT5-1.1
unnamed: R-CRTCCT5-4.2, RV-CRTCCT5-1.2
unnamed: R-CRTCCT5-5.1, RV-CRTCCT5-3.1
unnamed: R-CRTCCT5-5.2, RV-CRTCCT5-1.3
unnamed: R-CRTCCT5-7.2, RV-CRTCCT5-3.3

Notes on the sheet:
ASTIG
FOCUS
BRILL

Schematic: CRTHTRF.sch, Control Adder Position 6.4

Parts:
T-CRTHTRF-1: Transformer_1P_3S; JST_EH_B8B-EH-A_1x08_P2.50mm_Vertical

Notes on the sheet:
These windings are at an elevated voltage of -1250v
Mounted at the rear of Rack 5
230v AC

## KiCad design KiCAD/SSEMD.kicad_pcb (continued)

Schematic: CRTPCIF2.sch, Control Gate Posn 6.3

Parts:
C-CRTPCIF2-1, C-CRTPCIF2-2, C-CRTPCIF2-3, C-CRTPCIF2-4, C-CRTPCIF2-5, C-CRTPCIF2-6: 22p; C_Disc_D7.5mm_W5.0mm_P5.00mm
C-CRTPCIF2-7: 10000uf 16V; C_Disc_D7.5mm_W5.0mm_P5.00mm
C-CRTPCIF2-8: 4u7 35V; C_Disc_D7.5mm_W5.0mm_P5.00mm
C-CRTPCIF2-9, C-CRTPCIF2-12: 0.1; C_Disc_D7.5mm_W5.0mm_P5.00mm
C-CRTPCIF2-10, C-CRTPCIF2-11: 4n7; C_Disc_D7.5mm_W5.0mm_P5.00mm
D-CRTPCIF2-1: EA50; Valve_B3G
D-CRTPCIF2-2, D-CRTPCIF2-3, D-CRTPCIF2-4, D-CRTPCIF2-5, D-CRTPCIF2-6, D-CRTPCIF2-7, D-CRTPCIF2-8, D-CRTPCIF2-9, D-CRTPCIF2-10, D-CRTPCIF2-11, D-CRTPCIF2-12, D-CRTPCIF2-13: CS60; D_T-1_P5.08mm_Horizontal
D-CRTPCIF2-14: IN4004; D_T-1_P5.08mm_Horizontal
D-CRTPCIF2-15: D_Tunnel; D_DO-201AD_P12.70mm_Horizontal
D-CRTPCIF2-16: IN4007; D_T-1_P5.08mm_Horizontal
J-ADDER1-18: HIGH Voltage.; TE_MATE-N-LOK_1-770970-x_2x04_P4.14mm_Horizontal
J-CRTPCIF2-1: PC.Read; 242431
J-CRTPCIF2-2, J-CRTPCIF2-3: A Read; 242431
J-CRTPCIF2-4: C4; 242431
J-CRTPCIF2-5: VAR.DASH.CF; 242431
J-CRTPCIF2-6: PC.UPLOAD; 242431
J-CRTPCIF2-7: CRT Blank; 242431
J-CRTPCIF2-8: Scope trigger; 242431
J-CRTPCIF2-9: S.ERASE.ALL; 242431
J-CRTPCIF2-10: PC.S.ERASE; 242431
J-CRTPCIF2-11: S Read; 242431
J-CRTPCIF2-12: DB25_Female_MountingHoles; DSUB-25_Female_Horizontal_P2.77x2.84mm_EdgePinOffset4.94mm_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
R-CRTPCIF2-1, R-CRTPCIF2-2, R-CRTPCIF2-3, R-CRTPCIF2-4, R-CRTPCIF2-5, R-CRTPCIF2-6: 100K; R_Axial_DIN0516_L15.5mm_D5.0mm_P5.08mm_Vertical
R-CRTPCIF2-7, R-CRTPCIF2-8, R-CRTPCIF2-9, R-CRTPCIF2-10, R-CRTPCIF2-11, R-CRTPCIF2-12, R-CRTPCIF2-13, R-CRTPCIF2-14, R-CRTPCIF2-15: 10K; R_Axial_DIN0516_L15.5mm_D5.0mm_P5.08mm_Vertical
R-CRTPCIF2-16: 4K7; R_Axial_DIN0516_L15.5mm_D5.0mm_P5.08mm_Vertical
R-CRTPCIF2-17, R-CRTPCIF2-18: 56K 2W; R_Axial_DIN0516_L15.5mm_D5.0mm_P5.08mm_Vertical
R-CRTPCIF2-19: 470K; R_Axial_DIN0516_L15.5mm_D5.0mm_P5.08mm_Vertical
R-CRTPCIF2-20: 330K; R_Axial_DIN0516_L15.5mm_D5.0mm_P5.08mm_Vertical
R-CRTPCIF2-21: 15K 3W; R_Axial_DIN0516_L15.5mm_D5.0mm_P5.08mm_Vertical
R-CRTPCIF2-22: 470; R_Axial_DIN0516_L15.5mm_D5.0mm_P5.08mm_Vertical
U1: L78L05_TO92; TO-92_Inline
U-CRTPCIF2-1, U-CRTPCIF2-4, U-CRTPCIF2-6: 4049; DIP-16_W7.62mm
U-CRTPCIF2-2: SN75188N; DIP794W53P254L1930H508Q14N; Manufacturer_Part_Number SN75188N; Mouser Part Number 595-SN75188N
U-CRTPCIF2-3: 4011; DIP-14_W7.62mm
U-CRTPCIF2-5: 4049; DIP-14_W7.62mm
V-CRTPCIF2-1, V-CRTPCIF2-2: VR91; Valve_9Loctal
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

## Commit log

2020-10-08 Add L-STAT.
    [ACCGATE.sch, ACTIN_WF.sch, ADDER1.sch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]
2020-10-08 System did some house keeping on exit.
    [FSTAT13.sch, L-STAT.sch]
2020-10-08 Fix A/B unit switch.
    [CRTCCT4.sch, CRTCCT5.sch, L-STAT.sch]
2020-10-09 Add Monicct & MonSW. KiCAD auto changed some of the rest.
    [ACCGATE.sch, ACTIN_WF.sch, ADDER1.sch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]
2020-10-10 Finish KEYSW2/ Add extra Symbols for switches.
    [ACCGATE.sch, KEYSW2.sch, SSEMD.kicad_pcb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]
2020-10-11 Expand POWRCTL6b.sch.
    Rearrange Libraries.
    [ACCGATE.sch, ACTIN_WF.sch, ADDER1.sch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]
2020-10-11 Finish powrctl6b
    Likely wrong bit of it I didn't understand other bits seem wrong inthe orginal.
    [KVPSU1.sch, KVPSU2.sch, POWRCTL6b.sch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]
2020-10-13 Add Prepulse PSEPCTL RMONDRS.
    [ACCGATE.sch, ACTIN_WF.sch, ADDER1.sch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]
2020-10-13 Add scfollws.sch
    [ACCGATE.sch, ACTIN_WF.sch, ADDER1.sch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]
2020-10-14 Add sclock correct fault in ACGATE.
    [ACCGATE.sch, ACTIN_WF.sch, ADDER1.sch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]
2020-10-15 Add SDOT&STB.
    [ACCGATE.sch, ACTIN_WF.sch, ADDER1.sch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]
2020-10-16 Add sclock, sdot&stb smonxtb
    [ACCGATE.sch, ACTIN_WF.sch, ADDER1.sch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]
2020-10-17 Add StorGate & some Valve Logic data.
    [ACCGATE.sch, ACTIN_WF.sch, ADDER1.sch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]
2020-10-18 Add SUBTR1.sch, SXTMBASE.sch TRANSFER.sch.
    [ACCGATE.sch, ACTIN_WF.sch, ADDER1.sch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]
2020-10-18 Add TYPEWE WRERCCTS YAMP&HVR.
    Which com,pletes the first pass. All the pages are done but I haven't checked them yet and there are bound to be errosr.
    [ACCGATE.sch, ACTIN_WF.sch, ADDER1.sch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]
